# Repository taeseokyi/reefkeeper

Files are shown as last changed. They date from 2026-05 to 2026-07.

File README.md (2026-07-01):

# AquaWiz - 고정밀 pH/dKH 자동 측정 시스템

🌐 **실시간 측정 그래프:** https://taeseokyi.github.io/reefwiz/
(안드로이드 Chrome에서 열어 메뉴 → **홈 화면에 추가**를 누르면 앱처럼 설치됩니다)

> **:warning: 경고:** 이 프로젝트의 하드웨어, 소프트웨어, 문서는 **어떠한 공식 검증도 거치지 않았습니다.** 측정 정확도, 전기적 안전성, 장기 신뢰성에 대한 보증이 없으며, 사용으로 발생하는 모든 결과(장비 손상, 생물 피해, 화재, 감전 등)에 대한 **책임은 전적으로 사용자 본인**에게 있습니다.

산호 수조(리프 탱크)를 위한 Arduino Nano 기반 **자동 경도(dKH) 측정기**입니다.
탄산염 화학법을 이용하여 참조 해수와 수조수의 pH 차이로부터 dKH를 자동 산출합니다.

셋팅 구성

### 최종 형태 — 밀폐 폐루프 (공통 헤드스페이스)

> **밀폐는 선택이 아니라 필수입니다.** 참조수 통·측정 챔버·펌프 흡입을 **하나의 밀폐된 공기**로 묶어, 측정 순간 참조수(ref)와 수조수(tank)가 **같은 pCO₂**를 공유하도록 보장합니다. 이것이 방 CO₂ 변동을 차동으로 상쇄하는 핵심 조건이며, 동시에 증발(경도 농축)까지 차단합니다. 밀폐 적용 후 첫 새벽(고-CO₂) 측정에서 그간 재현되던 새벽 오차가 사라졌습니다(ΔpH −0.043 → **−0.008**) — [측정 대장](docs/measurement-ledger.md) 2026-06-19 참조.

| 제어기 |
|:---:|
| 제어기 |

### 주요 특징

- **[±0.07 dKH 정확도](docs/system-setup.md#측정-정확도)** — 16비트 ADC + 64회 오버샘플링 + Nernst 온도 보정, 분해능 ±0.001 dKH
- **[PC 연동 평형 자동 측정](docs/system-setup.md#자동-측정-시퀀스-pc-측-v4)** — 샘플링 → 폭기(CO2 평형) → tank·ref **진짜 평형(평탄)까지** pH 측정 → dKH 계산 → 정리. 펌웨어가 아닌 PC측 파이썬 스크립트가 평탄(수렴) 판정으로 단계를 제어
- **[탄산염 화학법](#측정-원리)** — `KH_tank = KH_ref × 10^(-ΔpH)`, 참조수와 동시 탈기로 CO2 변수 제거
- **[Nernst 온도 보정](docs/system-setup.md#nernst-온도-보정)** — 보정 온도 EEPROM 저장, 15~35°C 전 범위 오차 0%
- **[블루투스 제어](docs/user-manual.md#14-블루투스-터미널-앱)** — HC-06으로 스마트폰에서 원격 제어/모니터링 ( <a href="https://play.google.com/store/apps/details?id=de.kai_morich.serial_bluetooth_terminal" target="_blank">Serial Bluetooth Terminal</a> 앱 추천)
- **[참조 dKH 역산](docs/user-manual.md#35-calref--참조-dkh-역산)** — 수조 dKH 실측값으로 참조수 dKH를 자동 계산, 참조수 별도 측정 불필요
- **[밀폐 공통 헤드스페이스 (필수)](docs/system-setup.md#위즈-탱크)** — 참조수·측정수·펌프 흡입이 한 밀폐 공기를 공유 → 측정 순간 ref·tank pCO₂ 일치(방 CO₂ 공통모드 상쇄) + 증발/오염 차단. 새벽 고-CO₂에서도 ΔpH 안정(2026-06-19 검증)
- **[3D 프린팅 하우징](docs/system-setup.md#하우징-3d-프린팅)** — OpenSCAD 파라메트릭 설계, 부품 실측 후 즉시 출력
- **확장 가능** — ESP32 보드와 시리얼/블루투스 연결로 Wi-Fi, 웹 대시보드, 모바일 앱, 인터넷 접속으로 확장 가능

> 정밀한 pH 측정을 위해 Wi-Fi가 없는 Arduino Nano를 사용하여 전자기 간섭을 최소화하였습니다. Wi-Fi, 웹 대시보드, 데이터 로깅 등 부족한 기능은 ESP32를 시리얼/블루투스로 연결하면 해결 가능합니다.

> 연동 펌프의 토출량은 설정한 시간(초)에 비례하지만, 호스 길이나 수두차에 따라 실제 물량이 달라질 수 있습니다. 각 펌프에 PWM 속도 컨트롤러의 Motor− 출력을 L298N ENA/ENB에 연결하여 역 PWM으로 모터 속도를 제어하므로, 토출량을 미세하게 조정할 수 있습니다.

## 한눈에 보기

| 시스템 구성도 | 호스 연결도 |
|:---:|:---:|
| 구성도 | 호스 |

| 회로도 (Fritzing) | 하우징 (3D 프린팅) |
|:---:|:---:|
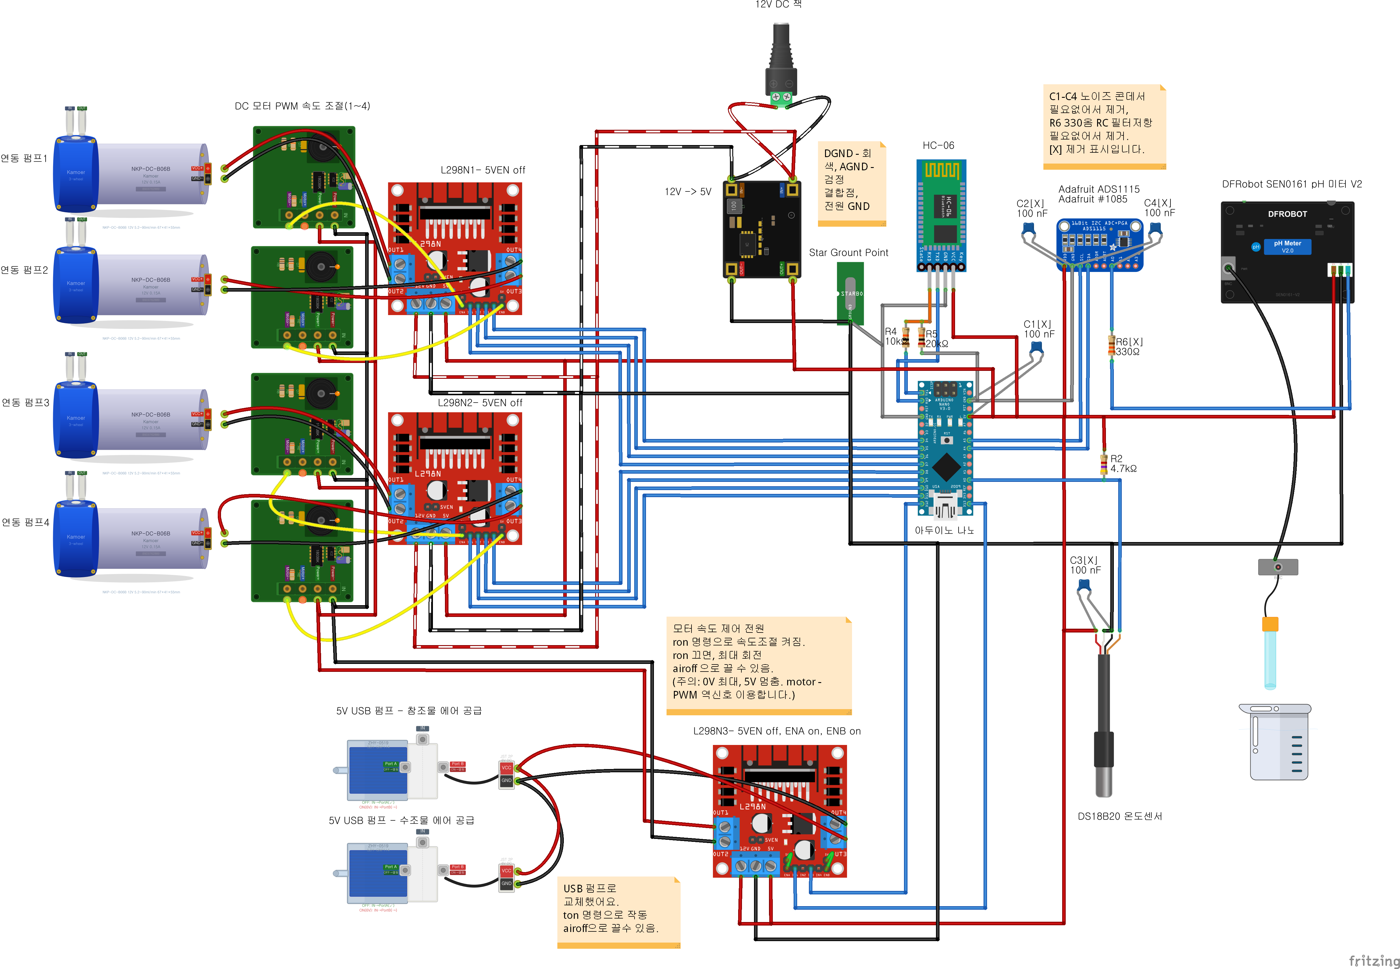
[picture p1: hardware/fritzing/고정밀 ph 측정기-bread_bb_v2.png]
회로도
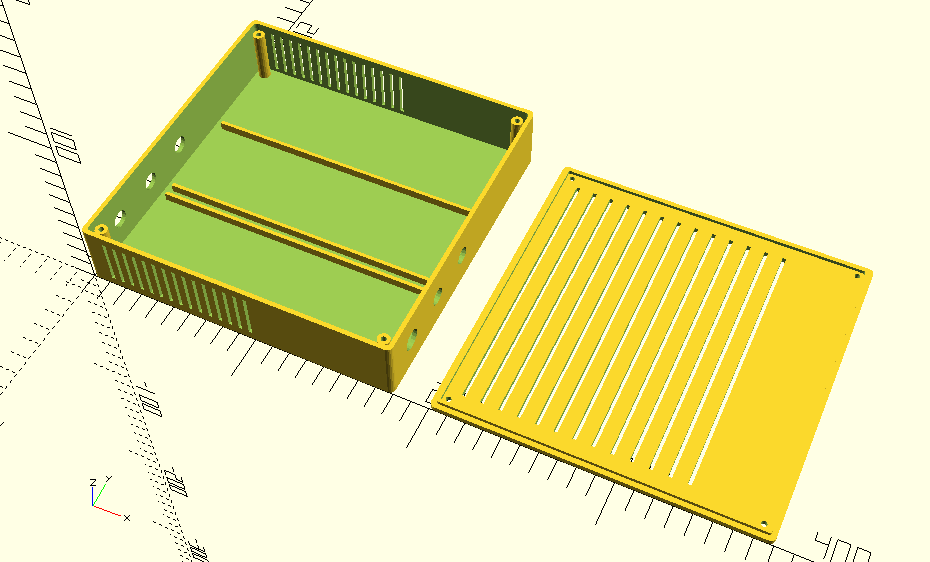
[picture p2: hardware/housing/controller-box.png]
제어기
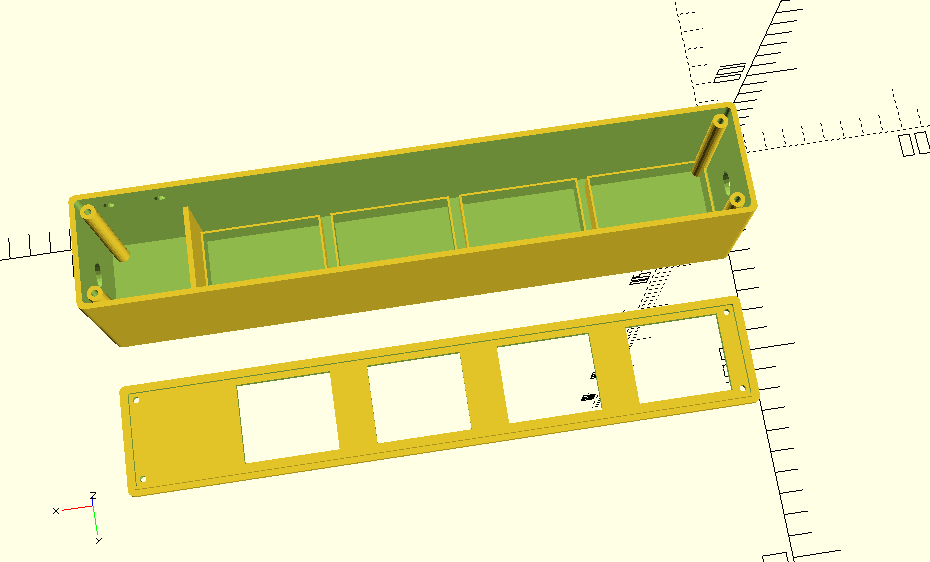
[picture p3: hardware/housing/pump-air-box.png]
펌프
|  |   |

## 측정 정확도

> **dKH 8.5 기준, 시스템 정확도 ±0.07 dKH (±1.2%)** — pH 프로브 반복성이 전체 오차의 97%를 차지하며, 전자 회로와 펌웨어 계산 로직은 프로브 성능을 100% 활용할 수 있는 수준입니다.

| 항목 | 성능 | 핵심 기술 |
|---|---|---|
| 측정 분해능 | **±0.001 dKH** | 16비트 ADC (ADS1115) + 64샘플 트림평균(정렬 후 상·하위 16개 버리고 중앙 32개 평균 → 폭기 버블 스파이크 제거) |
| 시스템 정확도 | **±0.07 dKH (±1.2%)** | Nernst 보정 + 동일 온도 차등 측정 |
| 온도 보정 오차 | **0%** | 보정 온도 EEPROM 저장, 15~35°C 전 범위 |

[상세 오차 분석 →](docs/system-setup.md#측정-정확도)

> **이 수치는 책상 계산이 아니라 수십 회의 실측·검증을 거쳐 다듬은 결과입니다.** 코드 버전(V0~V4)별 측정 기록, 환경 변수(방 CO₂) 통제, 차동 측정이 방 CO₂ 의존성을 제거함을 보인 ΔpH 검증, 그리고 그 해석을 뒷받침한 학술 문헌까지 — 신뢰성의 근거는 모두 [**측정 대장**](docs/measurement-ledger.md)에 시각순으로 정리되어 있습니다.

> **✅ 완전 널테스트로 확정 (2026-06-21):** 같은 물(위즈 해수)을 ref·tank 양쪽에 넣어 *물 차이를 0으로 만든* 완전 널에서 **ΔpH −0.003, dKH 8.387 (참값 8.448 대비 오차 −0.061)** 을 측정했습니다. 물 차이가 구성상 0이므로 이 −0.06 dKH가 계측기의 *순수* 시스템 offset입니다 — ±0.07 정확도 사양을 실측으로 뒷받침합니다. (참고: 측정 시점에 보였던 큰 오차는 *시험용 옛 200mL 시료 물의 알칼리니티 손실(CaCO₃ 석출)* 이었으며 계측기 오차가 아니었습니다. 신선한 물에선 무보정으로 ±0.1 dKH 안.) — [측정 대장 최종 결론](docs/measurement-ledger.md) 참조.

## 측정 원리

```
KH_tank = KH_ref × 10^(-ΔpH)
ΔpH = pH_ref − pH_tank
```

탈기 후 두 샘플의 CO2 농도가 동일해지면, pH 차이는 순수하게 알칼리니티(dKH) 차이만을 반영합니다.

> **★전제 = 같은 pCO₂.** 위 식은 측정 순간 ref·tank의 CO₂가 동일할 때만 순수 dKH차를 줍니다. 이를 보장하는 것이 **밀폐 공통 헤드스페이스**입니다 — 두 물이 하나의 밀폐 공기를 공유하므로 방 CO₂가 변해도 공통모드로 상쇄됩니다. 밀폐는 [위즈 탱크 구성](docs/system-setup.md#위즈-탱크)에서 **필수**로 다룹니다.

## 하드웨어

| 부품 | 모델 | 역할 |
|---|---|---|
| MCU | Arduino Nano V3.0 (ATmega328P) | 메인 컨트롤러 |
| pH 센서 | DFRobot SEN0161-V2 | pH 전압 측정 |
| ADC | Adafruit ADS1115 (16-bit) | I2C 고정밀 ADC |
| 온도 센서 | DS18B20 (PTFE) | Nernst 온도 보상 |
| 블루투스 | HC-06 | 하드웨어 Serial (9600 baud) |
| 모터 드라이버 | L298N x 3 | L298N1/N2: 도징 펌프 (12V), L298N3: 에어 펌프 (5V) |
| 도징 펌프 | Kamoer NKP-DC-B06S x 4 | 참조수/수조수 도징 |
| 에어 펌프 | USB 5V 에어 펌프 x 2 | 참조수/수조수 폭기 (L298N3 제어) |
| 전원 | 12V DC + Buck Converter (5V) | 전원 공급 |

- 구매 링크 포함 상세 목록: [준비물 목록](docs/parts-list.md)
- 구성 요소 상세 / 펌프 역할: [자동화 환경 구성 — 구성 요소](docs/system-setup.md#구성-요소)
- 3D 프린팅 하우징: [자동화 환경 구성 — 하우징](docs/system-setup.md#하우징-3d-프린팅)

### 회로도

브레드보드 회로도

Fritzing 소스: <a href="hardware/fritzing/고정밀%20ph%20측정기-bread.fzz" target="_blank">고정밀 ph 측정기-bread.fzz</a> | PDF: <a href="hardware/fritzing/고정밀%20ph%20측정기-bread_bb.pdf" target="_blank">브레드보드 도면</a>

**핀 배치 요약:**

```
D0  (RX)  ← HC-06 TX        D1  (TX)  → HC-06 RX (전압분배기)
D4~D7     → L298N1 IN1~IN4  D8~D11    → L298N2 IN1~IN4
D12       → L298N3 IN2 (에어 펌프 ON/OFF, ron/roff)  D13  → L298N3 IN4 (PWM 속도 제어기 ON/OFF, ton/toff)
A0  (D14) ← DS18B20 DQ      A4/A5     ↔ ADS1115 I2C
```

### 전원 / 접지

```
12V DC Jack
  ├── L298N1, L298N2 (모터 전원, 12V → 도징 펌프)
  ├── Buck 12V→5V (Arduino, ADS1115, HC-06)
  └── USB 5V → L298N3 (에어 펌프 제어)
속도 제어: PWM 컨트롤러 Motor− → L298N ENA/ENB (역 PWM)
접지: Star Ground Point (DGND/AGND 분리 후 한 점 결합)
```

## 빌드 및 업로드

| 라이브러리 | 제작자 |
|---|---|
| DFRobot_PH | DFRobot |
| Adafruit ADS1X15 | Adafruit |
| OneWire | Paul Stoffregen |
| DallasTemperature | Miles Burton |

1. Arduino IDE에서 [`firmware/aquawiz_ph_meter_final/aquawiz_ph_meter_final.ino`](firmware/aquawiz_ph_meter_final/aquawiz_ph_meter_final.ino) 열기
2. 보드: **Arduino Nano**, 프로세서: **ATmega328P** 선택
3. **HC-06을 D0/D1에서 분리** 후 업로드 → 완료 후 재연결

## 사용 방법

### 초기 설정

```
1. pH 2점 보정:   enterph → calph (pH7) → exitph → enterph → calph (pH4) → exitph
2. 온도 오프셋:   settemp:-0.3
3. 참조 dKH:      setref:8.5
```

### 자동 측정 (PC 연동)

폭기 중 측정을 반복하며 **tank·ref가 진짜 평형(평탄)에 도달할 때까지** 측정해야 하므로(평탄 판정 = 측정값 비교 후 반복 결정), 자동화는 펌웨어가 아닌 **PC측 파이썬 스크립트**가 담당합니다. 펌웨어에는 더 이상 `seq` 매크로가 없습니다.

```bash
# 1회 측정 후 종료 (Windows 작업 스케줄러 정시 호출용 / 수동 실행 가능)
python bin/measure_kh_once.py        # 포트 = 스크립트 기본값 COM15
python bin/measure_kh_once.py COM7   # 포트 직접 지정
```

스크립트는 준비(샘플링·헹굼) → **[A] tank·ref 동시 폭기 + tank 평탄까지** → 전이 → **[B] ref 평탄까지** → `calkh` → 정리 순으로 펌웨어 명령을 단계별 전송합니다. 상세 흐름·상수·스케줄러 등록은 [자동화 환경 구성 — 자동 측정 시퀀스](docs/system-setup.md#자동-측정-시퀀스-pc-측-v4)를 참조하세요.

### 주요 명령어

| 분류 | 명령어 |
|---|---|
| pH 측정 | `ref`, `tank`, `calkh`, `calref`, `status`, `khhist` |
| pH 보정 | `enterph`, `calph`, `exitph` |
| 설정 | `settime:HH`, `setref:x`, `settemp:x` |
| 모터 | `m1f:초`, `m1b:초`, `m1s` (m1~m4) |
| 에어/PWM | `ron`/`roff` (D12 에어 ON/OFF), `ton`/`toff` (D13 PWM 제어기 ON/OFF), `airoff` (둘 다 OFF) |
| 정지 | `m1s`~`m4s` (개별), `stop` (전체 모터+핀 OFF) |

전체 명령어 및 상세 설명은 [사용 설명서](docs/user-manual.md)를 참조하세요.

## 문서

| 문서 | 설명 |
|---|---|
| [자동화 환경 구성](docs/system-setup.md) | 구성 요소, 호스 연결, 측정 시퀀스, 하우징 |
| [사용 설명서](docs/user-manual.md) | 전체 명령어, 보정, 오류 메시지, 팁 |
| [준비물 목록](docs/parts-list.md) | 부품 사진, 구매 링크, 금액 |
| [**측정 대장**](docs/measurement-ledger.md) | 코드 버전별 실측 기록·환경·ΔpH 검증·참조 문헌 — **결과 신뢰성의 근거** |

## 산호 수조 권장 dKH 범위

| 유형 | dKH |
|---|-----|
| 자연 해수 | 6.5 ~ 7.5 |
| 산호 수조 권장 | 8 ~ 12 |
| SPS 경산호 최적 | 8 ~ 9 |
| LPS/소프트 코랄 | 7 ~ 11 |

## 라이선스

이 프로젝트는 개인 용도로 제작되었습니다.

---

이 프로젝트의 펌웨어, 문서, 다이어그램, 하우징 설계의 **80% 이상이 AI의 도움**을 받아 작성되었습니다.

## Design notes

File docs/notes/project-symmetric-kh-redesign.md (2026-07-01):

# project-symmetric-kh-redesign

> "KH 측정 대칭화 재설계 확정안 — 저장수조 직접 폭기, tank 우선, KCl 스윕=tank 헹굼, 3M KCl 보관 — 구현+Windows 배포 완료(2026-06-14)"

---

**2026-06-12 설계 확정 (사용자 주도), WSL bin/ 구현. 2026-06-14 펌프시간 튜닝 + Windows `measure_kh_once.py` 배포 완료(커밋 9b333e2).** 수렴 판정(`measure_converged`: 45초 간격, 연속 차 <CONV_EPS=**0.005**, 최대 6회, STABLE_SECS=60). 실제 펌프 동작시간은 [project-pump-timings](project-pump-timings.md) 참조(아래 시퀀스의 :5/:2는 설계 당시 placeholder). dkh.dat 형식은 불변(서버 호환), 수렴 횟수는 measure_kh.log 에만 기록.

**문제:** 기존 시퀀스는 참조수가 측정컵에서 30분 폭기(프로브 30분 소크=완전 평형) 후 측정, 수조수는 교체 ~20초 만에 측정 → 전극 응답 지연이 tank에만 실리는 계통 편향. 드리프트(0.01 pH/h)는 ref↔tank 간격이 짧아 무시 가능(~0.002 dKH); 표적은 지연 편향.

**확정 시퀀스 (tank 우선):**
```
[준비]  airoff → ton → m1f:5 (수조수→챔버)
[폭기]  ron 30분 (저장수조 5L + 챔버 동시) — 프로브는 측정컵 KCl에 휴식 → airoff
[tank]  m3b:5 (KCl 배출)
        m2f:2 → m2b:2   ← KCl 스윕 = tank 헹굼 겸용
        m2f:5 → T초 안정화 → 'tank' → m2b:5
[ref]   m4f:2 → m4b:2   ← ref 헹굼 (tank 잔막 제거)
        m4f:5 → T초 안정화 → 'ref' → 'calkh' → m4b:5
[정리]  m1b:5 (KCl 포함 챔버수→본수조 방출·희석) → m3f:5 (KCl 재공급) → airoff
```

**설계 근거:**
- 폭기를 저장수조 자체에서: 새 용기/펌프/펌웨어 불필요, 유일한 물리 작업=참조측 에어스톤을 측정컵→저장수조 이전. 5L 관성으로 ref 평형 안정.
- tank 우선: KCl 스윕이 tank 헹굼을 겸해 단계 절약. 쓸린 KCl은 챔버→m1b→본수조(무한 희석). ref 헹굼 반환수가 KCl-free → 5L 앵커(8.448) 보호.
- 펌웨어는 측정 순서 무관: ref/tank 플래그 독립(ino:618-619), calkh는 둘 다 요구 후 리셋(ino:404-430).
- 헹굼=희석 원리(잔막 0.3mL/채움 50mL ≈ 1/100), 펌프 제트가 교반 역할, 흔들기 불필요. ref 헹굼은 화학적으론 보험이지만 **타이밍 대칭(지연 공통모드 상쇄)을 위해 유지** — tank/ref 블록의 헹굼·채움·안정화 시간을 초 단위로 동일하게.

**보관액: 3M KCl in RODI (1L당 224g ≈ 22% w/v, 시약 직접 제조)**
- 용해도 OK: 포화 ≈4.2M@25°C, 3M은 0°C 근처까지 석출 없음 (이게 3M이 표준인 이유).
- 측정 외 상시 소크 = 컨디셔닝 그 자체 → **별도 재생 루틴 불필요.** 응답 둔화(수렴 횟수 증가로 감지) 시에만 묽은 HCl 세척 고려.
- 중성염이라 스윕 혼입 dKH 무영향. 본수조 K⁺ 유입 하루 ~1g KCl(잔막 0.2mL 가정) → 환수 길면 가끔 K⁺ 테스트.
- 저장조 증발 농축 → RODI 수위 보충.

**스크립트 구현 메모 (다음 세션):**
- 안정화 T = 60~120초, tank/ref 동일.
- 수렴 판정 권장: 'tank'/'ref'를 45초 간격 반복, 연속 차 <0.005이면 진행(최대 6회). 펌웨어가 마지막 값 덮어쓰므로 수정 불필요. 수렴 횟수 로그 = 전극 건강 지표.
- 참조수 5L 증발 농축(1%=+0.08 dKH 상당) → 주기적 수위 보충/calref.
- 에어스톤 이전 직후 첫 사이클은 폭기 1~2시간 수동 연장(5L 첫 평형).
- 에어스톤 이전 직후 첫 사이클은 폭기 수동 연장 권장(5L 첫 평형). 평상시 폭기=20분(AIR_SECS 1200).

**커밋/문서 (2026-06-12, 커밋 9979dfb 푸시 완료):** bin 스크립트 + `docs/system-setup.md` "자동 측정 시퀀스" 섹션 전면 재작성(설계 배경·9단계 흐름·스크립트 상수표·운용 메모) + 문서/SVG의 "KCL 3%"→"3M KCl" 일괄 변경.

**KCl 스윕 정당성 (사용자 질문에 답한 논리, 재논의 방지용):** 스윕한 KCl이 수조물 비이커 경유로 측정수에 일부 되돌아오는 것 맞음(반환 비율≈채움량/비이커수량≈1/3, 헹굼 없으면 ~18mM vs 있으면 ~6mM). 그래도 헹굼이 나은 이유: ①되돌아온 혼입은 **묽고 균일** — 중성염이라 알칼리도 무영향, 이온강도 +2% 수준으로 pH 영향 <0.002. ②헹굼이 막는 진짜 문제는 3M 원액 잔막의 **국소 농도 구배** → 정션 전위 드리프트(수 mV, 1mV≈0.017pH≈0.3dKH) + 수렴 지연. ③ref 블록에 헹굼이 있으므로 tank 헹굼 제거 시 전극 이력 비대칭 재발. ④혼입분은 m1b로 본수조 방출되어 누적 없음.

**Why:** 응답 지연 비대칭 제거가 목표. 사용자 결정 사항(저장수조 폭기, tank 우선, 3M KCl)을 보존해 다음 세션에서 재논의 없이 구현.

**How to apply:** 구현·배포 완료. 운용 모니터링은 measure_kh.log의 `[수렴실패]` 빈도(잦으면 STABLE_SECS↑)와 수렴 횟수(전극 노화) 관찰. 관련: [project-measure-kh-script](project-measure-kh-script.md), [project-pump-timings](project-pump-timings.md), [project-firmware-kh-calc](project-firmware-kh-calc.md), [feedback-run-windows-py-from-wsl](feedback-run-windows-py-from-wsl.md)

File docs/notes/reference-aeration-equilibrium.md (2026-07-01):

# reference-aeration-equilibrium

> "폭기 화학 — 대기평형이 pH 상한, \"과폭기\" 불가, 폭기 부족(비대칭)만 dKH 오차 유발"

---

폭기는 물의 pCO₂를 방 공기(~400ppm)와 **평형**시키는 과정. 평형 도달 시 pCO₂(물)=pCO₂(공기)가 되어 **더 폭기해도 pH가 안 올라감 — 대기평형 pH가 천장**. 따라서 "과폭기로 ΔpH가 평형을 넘어 틀어진다"는 메커니즘은 **없다**(사용자 지적 맞음, 2026-06-15). 폭기가 dKH를 틀어뜨리는 건 오직 **부족(ref·tank 비대칭)**일 때 — 한쪽에 CO₂가 잔류하면 그쪽 pH가 부당히 낮아져 가짜 ΔpH.

차동식 `KH_tank = 8.448 × 10^(−(pH_ref−pH_tank))`([project-firmware-kh-calc](project-firmware-kh-calc.md))가 순수 KH차를 반영하려면 **ref·tank의 pCO₂가 같아야** 함. 그래서 측정 시퀀스는 ref(5L 김치통)+tank(챔버) **동시 폭기**로 양쪽을 같은 평형에 맞춤([project-symmetric-kh-redesign](project-symmetric-kh-redesign.md)). 양쪽 평형 후 남는 ΔpH = 진짜 KH차 + 전극 노이즈(±0.005~0.01). 민감도 ≈19.5 dKH/pH(0.01 pH = 0.19 dKH)라 작은 ΔpH도 dKH로 증폭됨. 평형 도달이 안 되면(부피 큼) 시간이 율속 — 5L는 8h에도 잔차 0.020, 소부피(~150mL)면 20분 1회로 완전평형. 관련 [project-kh-offset-aeration-test](project-kh-offset-aeration-test.md)

**부피 대칭 불필요(2026-06-15 사용자 정정)**: 평형 pH = f(AT, pCO₂, T, S)이고 **부피 항 없음**(헨리법칙 [CO₂]aq=K_H·pCO₂는 부피 무관). 따라서 수조수 100mL vs 참조수 1L처럼 **부피가 달라도 둘 다 완전 평형이면 ΔpH 오차 0** — 부피는 상쇄됨. "같은 부피라야 대칭"은 부분평형(미완)일 때만 성립(부피 다르면 평형곡선상 다른 지점). 즉 관건은 부피 일치가 아니라 **둘 다 완전 평형 도달 + ref/tank의 pCO₂·온도 일치**. 율속은 느린 쪽(부피 큰 ref) → 폭기시간을 그 기준으로. ref를 상시 폭기로 늘 평형 유지하면 매 측정 때 100mL 수조수만 평형시키면 됨(소부피라 빠름). 완전평형 도달의 실측 증거 = 수렴판정 plateau(45s/0.005). 1L·20분이면 마진 충분([reference-aeration-literature](reference-aeration-literature.md) Takahashi 직접버블링 15분).

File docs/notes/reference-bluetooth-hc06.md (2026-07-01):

# reference-bluetooth-hc06

> "HC-06 블루투스 WSL 연결 방법 — rfcomm, MAC 주소"

---

**HC-06 MAC:** `98:DA:60:0F:C5:7A`

**WSL에서 연결 순서:**
1. Windows PowerShell (관리자): `usbipd bind --busid 1-1` (최초 1회)
2. Windows PowerShell: `usbipd attach --wsl --busid 1-1` (재시작 시마다)
3. WSL: `sudo service bluetooth start`
4. WSL: `sudo rfcomm release rfcomm0` (기존 bind 있을 때)
5. WSL: `sudo rfcomm connect rfcomm0 98:DA:60:0F:C5:7A 1`
   → "Connected /dev/rfcomm0 ..." 메시지 후 터미널 유지 (또는 nohup 백그라운드)

**주의사항:**
- HC-06은 1:1 연결 — 폰 앱 연결 중이면 PC에서 접속 불가, 폰 먼저 끊을 것
- rfcomm connect 터미널 닫으면 연결 끊김
- bluetoothctl trust 설정 필요: `bluetoothctl trust 98:DA:60:0F:C5:7A`

**연결 확인:**
```bash
python3 -c "import serial,time; s=serial.Serial('/dev/rfcomm0',9600,timeout=3); time.sleep(1); s.write(b'status\r\n'); time.sleep(2); [print(s.readline().decode().strip()) for _ in range(20) if s.in_waiting]"
```

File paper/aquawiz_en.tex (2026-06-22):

\documentclass[11pt]{article}

% ---- arXiv-style preprint layout (pdflatex) ----
\usepackage[utf8]{inputenc}
\usepackage[T1]{fontenc}
\usepackage{lmodern}
\usepackage[margin=1in]{geometry}
\usepackage{amsmath,amssymb}
\usepackage{graphicx}
\usepackage{booktabs}
\usepackage{array}
\usepackage{multirow}
\usepackage{longtable}
\usepackage{caption}
\usepackage{authblk}
\usepackage{xcolor}
\usepackage{enumitem}
\usepackage[hidelinks]{hyperref}
\usepackage{textcomp}
\usepackage{mhchem}
\usepackage{siunitx}
\sisetup{detect-all}
\usepackage{pgfplots}
\pgfplotsset{compat=1.15}
\usetikzlibrary{arrows.meta,positioning,calc}

\captionsetup{font=small,labelfont=bf}
\renewcommand{\arraystretch}{1.15}

% convenience macros
\newcommand{\dpH}{\ensuremath{\Delta\mathrm{pH}}}
\newcommand{\dkh}{\ensuremath{\,\mathrm{dKH}}}
\newcommand{\co}{\ensuremath{\mathrm{CO_2}}}
\newcommand{\pco}{\ensuremath{p_{\mathrm{CO_2}}}}
\newcommand{\at}{\ensuremath{A_\mathrm{T}}}

\title{\bfseries A Low-Cost Single-Probe Differential-pH Aeration Monitor for\\
Seawater Carbonate Alkalinity: Systematic-Error Decomposition and\\
Sub-0.25\,dKH Accuracy via Sealed Common-Headspace Equilibration}

\author[1]{nowforyou\thanks{Correspondence: \texttt{taeseokyi@gmail.com}}}
\affil[1]{REEF FAMILY}

\date{\today}

\begin{document}
\maketitle

\begin{abstract}
\noindent
Carbonate alkalinity (``KH'', expressed in degrees, \dkh) is the single most
control-critical water-chemistry parameter in reef aquaria, yet affordable
continuous monitors are scarce and reagent titration is laborious. We describe
an open, reagent-free monitor that infers alkalinity from the equilibrium pH a
seawater sample reaches after aeration to atmospheric \co{}, using a
\emph{single} pH probe to measure an aquarium sample (``tank'') and a
known-alkalinity reference (``ref'') in immediate succession. Because dKH is
computed from the pH \emph{difference}
($\mathrm{KH_{tank}} = \mathrm{KH_{ref}}\cdot 10^{\dpH}$), absolute probe drift
and room-\co{} excursions are common-mode signals that cancel. Over a
nine-day instrumented campaign (30 logged measurements across five
firmware/method revisions) we observed a persistent uncorrected error of
$-0.92\dkh$ and, rather than zero-point calibrating it away, decomposed it.
Three interventions---(i) plateau-following measurement to true gas
equilibrium, (ii) a single \emph{sealed common headspace} shared by sample,
reference and pump intake, and (iii) an actively aerated 5\,L reference anchor
that pins the headspace \pco{}---collapsed the dawn-\co{} error and the
diurnal evaporation confound, and shrank measurement scatter to
$\mathrm{SD}=\pm0.08\dkh$ (about one-third of the $\pm0.25\dkh$ design goal). A
sequence of null experiments (identical water in both vessels, true
$\dpH=0$) then localized the residual: a \emph{complete null} returned
$\dpH=-0.003$, $\mathrm{dKH}=8.387$, i.e.\ an instrument offset of only
$-0.06\dkh$. The remaining $-0.86\dkh$ was traced to alkalinity loss
(\co{}\,driven \ce{CaCO3} precipitation / biofilm) in the days-old, small,
open tank aliquot---a sample-handling artifact, not a measurement fault.
Re-running the null on the same aged aliquot over the following day showed the
offset drifting away from zero ($-0.22$ then $+0.22\dkh$ on successive runs) with
the electronics untouched, confirming the attribution in the time domain.
The instrument therefore meets the $\pm0.25\dkh$ goal uncorrected, with
zero-point calibration deemed unnecessary. Our independently obtained error
structure (room-\co{} sensitivity, bubble-quality dependence, sealing as the
remedy) reproduces the published behaviour of a commercial counterpart, providing
external validation of both the diagnosis and the remedy.
\end{abstract}

\noindent\textbf{Keywords:} reef aquarium; carbonate alkalinity; total
alkalinity; \co{} equilibration; differential pH; low-cost instrumentation;
common-mode rejection; \ce{CaCO3} precipitation.

% =====================================================================
\section{Introduction}
% =====================================================================
Stony corals and other calcifying reef organisms deposit calcium carbonate at
a rate that continuously consumes carbonate alkalinity. In a closed reef
aquarium the resulting alkalinity drawdown is fast (often
$0.5$--$1.5\dkh\,\mathrm{day^{-1}}$) and swings of more than $\sim1\dkh$ are
implicated in coral tissue stress. Alkalinity (\at{}, conventionally reported
by hobbyists as ``KH'' in German degrees, $1\dkh \approx
0.357\,\mathrm{meq\,L^{-1}}$) is therefore the parameter most worth measuring
\emph{often}.

The accessible options are unsatisfying for continuous use. Manual reagent
titration (e.g.\ commercial drop kits) is accurate but labour-intensive and
discrete. Colorimetric robots automate titration but consume reagent and are
expensive. Direct potentiometric pH alone is \emph{not} an alkalinity measurement,
because seawater pH depends jointly on \at{} and \pco{}, and aquarium \pco{}
varies strongly over the day (room ventilation, photosynthesis, respiration).

A reagent-free alternative exploits the fact that if a sample is aerated until
its \pco{} equilibrates with the surrounding air, the equilibrium pH becomes a
single-valued function of alkalinity at fixed temperature and salinity. A
commercial product (AquaWiz) is built on this principle and is used by reef
hobbyists, but community reports document recurring inaccuracy tied to room-\co{}
fluctuation and to aeration/bubble quality. The contribution of this paper is
not the principle but a \emph{quantitative diagnosis}: starting from a working
DIY build, we conduct a nine-day instrumented campaign, expose a $-0.92\dkh$ raw error,
and show by construction (null experiments) that essentially all of it is a
sample-handling artifact rather than an instrument limitation---reducing the
true instrument offset to $-0.06\dkh$ and meeting a $\pm0.25\dkh$ goal without
calibration. Along the way we establish a small set of design rules (sealed
common headspace; plateau-following to true equilibrium; an actively aerated
reference anchor; a two-gate plateau criterion) that we expect to generalize to
any single-probe differential-pH alkalinity monitor.

% =====================================================================
\section{Measurement Principle}\label{sec:principle}
% =====================================================================

\subsection{Aeration makes equilibrium pH a proxy for alkalinity}
At fixed temperature $T$ and salinity $S$, the seawater carbonate system has
two degrees of freedom; fixing any two of
$\{\at{}, \mathrm{DIC}, \pco{}, \mathrm{pH}\}$ determines the rest. Aeration with
a large excess of room air drives the dissolved \co{} toward Henry's-law
equilibrium with the gas phase, $[\co{}]_{aq}=K_H\,\pco{}$, so that
$\pco{}(\mathrm{water}) \to \pco{}(\mathrm{air})$. Once \pco{} is clamped by the
atmosphere, the equilibrium pH is a single-valued function of alkalinity:
\begin{equation}
\mathrm{pH_{eq}} = f(\at{},\,\pco{},\,T,\,S).
\label{eq:pheq}
\end{equation}
With \pco{}, $T$, $S$ held common, the \emph{only} variable that can move
$\mathrm{pH_{eq}}$ is \at{}. Measured equilibrium pH is therefore a proxy for
alkalinity.

\subsection{Why the differential cancels room \co{}}
The instrument never relies on the absolute value of \pco{}. It aerates the
reference and the tank sample to the \emph{same} atmospheric ceiling (in the
final design, by aerating both against one shared headspace simultaneously,
Sec.~\ref{sec:methods}) and reports the \emph{difference} of their equilibrium
pH. Because the absolute \pco{} term is common to both samples, it cancels in
the difference: a room-\co{} excursion is a common-mode signal that drops out.
What survives the subtraction is the true alkalinity difference plus electrode
noise ($\pm0.005$--$0.01$\,pH). This is the central robustness argument of the
method, and the reason a \emph{single} probe (rather than two matched probes)
is used: a single sensor's slow asymmetry-potential and reference-junction
drift load identically onto both readings and cancel in \dpH{}.

\subsection{Over-aeration is impossible; only \emph{insufficient} aeration errs}
Equation~\eqref{eq:pheq} has a hard ceiling at $\pco{}(\mathrm{air})$: once the
water reaches atmospheric equilibrium, further aeration cannot raise pH. There
is consequently no ``over-aeration'' failure mode. Error enters only through
\emph{insufficiency}: if residual \co{} remains in one vessel, that side's pH is
unfairly depressed and a spurious \dpH{} appears. The differential's assumption
is precisely that ref and tank share the same \pco{}; broken symmetry breaks
the cancellation. This motivates measuring to a genuine plateau rather than for
a fixed time (Sec.~\ref{sec:methods}).

\subsection{Volume independence at full equilibrium}
Equation~\eqref{eq:pheq} contains no volume term (Henry's law is
intensive). Hence even a large volume mismatch---in our final null,
$100\,\mathrm{mL}$ of tank water against a $5\,\mathrm{L}$ reference---produces
\emph{zero} differential error provided both vessels reach \emph{full}
equilibrium. The familiar ``equal volumes for symmetry'' rule applies only
under \emph{partial} equilibration, where unequal volumes sit at different
points on the first-order approach curve
$C(t)-C^\ast = (C_0-C^\ast)\,e^{-t/\tau}$. The true requirements are just
(a) both fully equilibrated and (b) matched \pco{} and $T$. The larger volume
is rate-limiting, with a time constant
\begin{equation}
\tau \;\propto\; \frac{V}{K_H\,Q_\mathrm{gas}}\,\beta
\;\sim\; \frac{1}{\mathrm{VVM}}\,\beta,
\label{eq:tau}
\end{equation}
where $\mathrm{VVM}=Q_\mathrm{gas}/V$ is gas volume per liquid volume per
minute and $\beta$ is a seawater chemical factor (only trace
$[\co{}]_{aq}$ is strippable; the Revelle buffering raises $\tau$ by
$\sim8$--$15\times$). Equation~\eqref{eq:tau} is the basis for the
``increase aeration to shorten the measurement'' lever discussed later, and for
the choice to miniaturize the rate-limiting reference.

\subsection{The differential dKH formula}
The firmware (Arduino Nano / ATmega328P; pH via DFRobot Gravity probe + ADS1115
16-bit ADC) digitizes one probe, reading reference then tank pH, and computes
\begin{equation}
\boxed{\;\mathrm{KH_{tank}} \;=\; \mathrm{KH_{ref}}\cdot 10^{-(\mathrm{pH_{ref}}-\mathrm{pH_{tank}})}
\;=\; \mathrm{KH_{ref}}\cdot 10^{\dpH}\;}
\label{eq:dkh}
\end{equation}
with $\dpH \equiv \mathrm{pH_{tank}}-\mathrm{pH_{ref}}$ and
$\mathrm{KH_{ref}}=8.448\dkh$ an EEPROM-stored \emph{anchor} constant (set by a
\texttt{calref} command after evaporation top-off; \emph{not} a per-run
measurement---this is why the reference column reads a constant 8.448 in every
log line). Equation~\eqref{eq:dkh} depends only on \dpH{}; absolute pH cancels
exactly. Differentiating,
\begin{equation}
\frac{d\,\mathrm{KH_{tank}}}{d\,\dpH}\bigg|_{\dpH=0}
= \mathrm{KH_{ref}}\ln 10 \approx 19.45\;\dkh\,\mathrm{pH^{-1}},
\label{eq:sens}
\end{equation}
i.e.\ $0.01$\,pH of uncancelled difference maps to $\approx0.19\dkh$. This high
sensitivity is what makes both the cancellation and the plateau criterion
matter. Temperature compensation is applied per reading by a Nernst relation
$\mathrm{pH_{corr}}=7.0+(\mathrm{pH_{raw}}-7.0)\,(273.15+T_\mathrm{cal})/(273.15+T_\mathrm{meas})$,
nominally zero-error over 15--35\,\textcelsius. Each pH reading is a trimmed
mean of 64 samples (discard the top and bottom 16, average the middle 32) to
reject aeration-bubble spikes.

% =====================================================================
\section{Apparatus}\label{sec:apparatus}
% =====================================================================
The build (Table~\ref{tab:bom}, Fig.~\ref{fig:device}) is a closed fluidic loop
around four bidirectional peristaltic pumps, two USB air pumps, a single pH
probe, and a 1-Wire temperature sensor, all driven by an Arduino Nano over a
9600-baud Bluetooth (HC-06) serial link to a host PC.

\begin{figure}[t]
\centering
\begin{tikzpicture}[
  font=\footnotesize, >={Latex[length=1.8mm]},
  vessel/.style={draw, rounded corners=2pt, fill=blue!6, align=center},
  pump/.style={draw, circle, fill=yellow!35, font=\scriptsize\bfseries, inner sep=0.4pt, minimum size=5.5mm},
  flow/.style={<->, thick, blue!55!black},
  air/.style={-{Latex[length=1.6mm]}, densely dotted, red!65!black, thick},
  wire/.style={-{Latex[length=1.6mm]}, gray!55!black},
]
% sealed headspace
\draw[dashed, rounded corners=7pt, gray!65, line width=0.9pt] (0.1,-3.05) rectangle (10.9,1.95);
\node[anchor=north east, gray!55!black, font=\scriptsize] at (10.8,1.88) {Sealed common headspace ($\approx$4\,L)};
% controller (outside, top)
\node[draw, rounded corners=2pt, fill=gray!10, align=center] (mcu) at (4.9,2.75)
  {Arduino Nano $+$ HC-06\,/\,ADS1115 pH\,/\,DS18B20};
% vessels
\node[vessel, minimum width=15mm, minimum height=20mm, fill=cyan!10] (aq) at (-2.2,-0.6) {Main\\reef\\aquarium};
\node[vessel, minimum width=14mm, minimum height=14mm] (hold) at (1.9,0.7) {Holding};
\node[vessel, minimum width=21mm, minimum height=21mm] (meas) at (4.9,-0.7) {Measurement\\chamber};
\node[vessel, minimum width=16mm, minimum height=19mm] (ref) at (8.9,-0.4) {Reference\\1\,L\\\scriptsize($+T$ sensor)};
\node[vessel, minimum width=15mm, minimum height=11mm, fill=green!8] (kcl) at (4.9,-2.45) {3\,M KCl};
\node[draw, rounded corners=1pt, fill=red!9, font=\scriptsize, align=center] (airp) at (8.9,-2.45) {Air pumps (\texttt{ron})};
% pH probe
\draw[line width=1pt] ([xshift=-3mm]meas.north) -- ++(0,5mm) coordinate (pp);
\node[font=\scriptsize, anchor=south] at (pp) {pH probe};
% liquid flows with pumps
\draw[flow] (aq.east) -- (hold.west);
\node[pump] at ($(aq.east)!0.5!(hold.west)$) {M1};
\draw[flow] (hold.south) -- (meas.north west);
\node[pump] at ($(hold.south)!0.5!(meas.north west)$) {M2};
\draw[flow] (ref.west) -- (meas.east);
\node[pump] at ($(ref.west)!0.5!(meas.east)$) {M4};
\draw[flow] (kcl.north) -- (meas.south);
\node[pump] at ($(kcl.north)!0.5!(meas.south)$) {M3};
% air lines
\draw[air] (airp.north) -- (ref.south);
\draw[air] (airp.west) to[out=180,in=-90] (meas.south east);
% probe wire to controller
\draw[wire] (pp) to[out=90,in=-90] (mcu.south);
\end{tikzpicture}
\caption{Schematic of the sealed closed-loop monitor. A single pH probe in the
measurement chamber reads the tank aliquot and the reference in turn; four
bidirectional peristaltic pumps (M1--M4) move liquid between the main aquarium,
holding beaker, measurement chamber, reference reservoir, and KCl store; two air
pumps (\texttt{ron}) aerate the reference and the chamber simultaneously. The
reference, chambers and pump intakes share one sealed headspace ($\approx$4\,L),
so sample and reference see identical $p_{\mathrm{CO_2}}$ and evaporation is
suppressed; the controller sits outside. Between runs the probe rests in 3\,M
KCl (M3).}
\label{fig:device}
\end{figure}

\begin{table}[t]
\centering
\caption{Bill of materials (current build).}
\label{tab:bom}
\footnotesize
\begin{tabular}{@{}p{0.26\linewidth} p{0.50\linewidth} c@{}}
\toprule
Subsystem & Part & Qty \\
\midrule
Microcontroller & Arduino Nano V3.0 (ATmega328P) & 1 \\
pH probe & DFRobot Gravity pH V2 (SEN0161-V2), single glass electrode & 1 \\
ADC & DFRobot Gravity I\textsuperscript{2}C ADS1115 (16-bit) & 1 \\
Temperature & DS18B20 waterproof (1-Wire), in the 5\,L reference & 1 \\
Comms & HC-06 Bluetooth, 9600\,baud & 1 \\
Pumps & NKP-DC-B06B 12\,V peristaltic, bidirectional (M1--M4) & 4 \\
Motor drivers & L298 2\,A modules (2 for pumps, 1 for air) & 3 \\
Air pumps & USB 5\,V, switched together (\texttt{ron}) & 2 \\
Reference reservoir & 5\,L sealed container (``Wiz tank'') & 1 \\
Chambers & 200\,mL beakers: holding, measurement, 3\,M KCl & 3 \\
Probe storage & 3\,M KCl ($\approx$22\,\% w/v) & --- \\
\bottomrule
\end{tabular}
\end{table}

\paragraph{Fluidic topology (current).} All pumps are bidirectional
($\mathtt{f}$ = forward, $\mathtt{b}$ = reverse):
\begin{itemize}[nosep,leftmargin=1.4em]
\item \textbf{M1}: main aquarium $\leftrightarrow$ \emph{holding} beaker;
\item \textbf{M2}: holding $\leftrightarrow$ \emph{measurement} chamber;
\item \textbf{M3}: 3\,M KCl beaker $\leftrightarrow$ measurement chamber (probe soak / storage);
\item \textbf{M4}: 5\,L reference $\leftrightarrow$ measurement chamber.
\end{itemize}
Routing the tank sample through an intermediate holding beaker lets it be
temporarily \emph{parked} while the reference is measured, minimizing the
between-phase delay (Sec.~\ref{sec:methods}). Run times are encoded as the
integer in $\mathtt{mXf{:}NN}$ / $\mathtt{mXb{:}NN}$ (seconds); reverse runs
$\sim$8--10\,s longer than forward to fully clear the hose (current values
$\mathtt{m1f{:}70/m1b{:}82}$, $\mathtt{m2f{:}60/m2b{:}68}$,
$\mathtt{m3f{:}60/m3b{:}68}$, $\mathtt{m4f{:}60/m4b{:}70}$; the 5\,L hose is
longest, hence \texttt{m4b:70}).

\paragraph{Control commands.} Air and motor enables are independent lines:
\texttt{ron} turns \emph{both} air pumps on (used only while liquid is
stationary---bubble cleaning and measurement); \texttt{ton} enables the PWM
motor controller (\emph{required} before any pump will turn); \texttt{airoff}
drops both. A load-bearing invariant follows: because \texttt{airoff} also
disables the PWM controller, every liquid move must be preceded by
\texttt{airoff}\,$\rightarrow$\,\texttt{ton}; the last air command before a
motor must be \texttt{ton}. Measurement primitives are \texttt{tank} / \texttt{ref}
(sample and store one pH reading) and \texttt{calkh} (apply
Eq.~\eqref{eq:dkh}).

\paragraph{Sealed common headspace (required).} The 5\,L reference, the
measurement chamber, and the pump intake share \emph{one} sealed headspace.
This is not an optional refinement: it (i) guarantees tank and ref see identical
\pco{} at the instant of measurement (the differential's premise), (ii) blocks
room-\co{} excursions at the source, and (iii) suppresses evaporation. In the
final configuration the headspace is $\approx$4\,L, the reference $\approx$1\,L,
and the tank aliquot $100\,\mathrm{mL}$; an air stone placed \emph{in} the
reference actively pins the shared \pco{} within minutes (the
``anchor'', Sec.~\ref{sec:methods}). Separate or isolated headspaces are
explicitly forbidden---two headspaces drift independently and destroy the
cancellation.

% =====================================================================
\section{Methods}\label{sec:methods}
% =====================================================================

\subsection{Two-phase plateau-following cycle (V4)}
Plateau detection is a host-side decision loop, so the PC script drives the
firmware step by step. The cycle measures \textbf{tank first, then ref}, so the
5\,L reference is co-aerated throughout the tank phase and converges quickly
when its turn comes:
\begin{enumerate}[nosep,leftmargin=1.6em]
\item \emph{Prep:} \texttt{m3b} (drain KCl from chamber)
$\rightarrow$ \texttt{m1f} (aquarium $\to$ holding)
$\rightarrow$ \texttt{m2f} (holding $\to$ chamber).
\item \emph{Phase A:} \texttt{ron}; measure \texttt{tank} every 30\,s until
plateau (chamber tank + 5\,L aerated together).
\item \emph{Transition:} \texttt{m2b} parks the tank aliquot back in holding;
\texttt{m4f} brings reference into the chamber.
\item \emph{Phase B:} \texttt{ron}; measure \texttt{ref} until plateau
(fast---already near equilibrium).
\item \texttt{calkh}; then cleanup: \texttt{m4b} (recover ref to 5\,L),
\texttt{m1b} (return parked tank to aquarium), \texttt{m3f} (restore KCl soak),
\texttt{airoff} (probe rests in KCl).
\end{enumerate}

\subsection{Two-gate plateau criterion}
Readings are held as integer milli-pH (mpH) to avoid floating-point boundary
jitter. A plateau is declared only when \emph{both} gates hold over a sliding
window (Table~\ref{tab:plateau}): a short \emph{span} gate (last 4 readings,
$\mathrm{max}-\mathrm{min}\le 2$\,mpH) rejects noise, and a longer \emph{net}
gate (last 8 readings, $|w_{-1}-w_{0}|\le 1$\,mpH) rejects a slow monotonic
exponential tail that the span gate alone would mistake for convergence. The
longer net look-back (8 vs.\ 4 points; ``B1'') was the fix for early latches in
which the tank stopped climbing prematurely. Per-phase wall-clock and
read-count caps ($\mathtt{PHASE\_MAX}=7200\,\mathrm{s}$,
$\mathtt{MEAS\_MAX}=240$) and a consecutive-failure cap
($\mathtt{FAIL\_MAX}=5$) bound the loop so it can never hang.

\begin{table}[t]
\centering
\caption{Plateau-following parameters (\texttt{measure\_until\_flat}).}
\label{tab:plateau}
\footnotesize
\begin{tabular}{@{}llp{0.5\linewidth}@{}}
\toprule
Constant & Value & Meaning \\
\midrule
\texttt{FLAT\_SPAN\_N}  & 4 & span window (jitter gate) \\
\texttt{FLAT\_SPAN\_MPH}& 2 & last 4: $\max-\min\le 2$\,mpH \\
\texttt{FLAT\_NET\_N}   & 8 & net look-back (drift gate; B1) \\
\texttt{FLAT\_NET\_MPH} & 1 & last 8: $|w_{-1}-w_0|\le 1$\,mpH \\
\texttt{MEAS\_INTERVAL} & 30\,s & between readings (aeration continuous) \\
\texttt{PHASE\_MAX\_SECS}& 7200\,s & per-phase cap (2\,h; 4\,h total) \\
\texttt{MEAS\_MAX}      & 240 & per-phase read cap \\
\texttt{FAIL\_MAX}      & 5 & consecutive parse failures tolerated \\
\bottomrule
\end{tabular}
\end{table}

Figure~\ref{fig:plateau} shows a measured pair of approach curves. The tank,
freshly drawn into the chamber, climbs a slow first-order tail toward its
ceiling and is held by the net gate until it is genuinely flat (latching at
$\sim$624\,s when the 8-point net drift falls to 1\,mpH). The reference, having
co-aerated in the 5\,L reservoir throughout the tank phase, is already at
equilibrium and latches in $\sim$2.6\,min---a direct illustration of why
measuring tank-first is faster, and of why the span gate alone (satisfied near
$\sim$546\,s) would have latched the tank early.

\begin{figure}[t]
\centering
\begin{tikzpicture}
\begin{axis}[
  width=0.86\linewidth, height=6.2cm,
  xlabel={Elapsed time (s)}, ylabel={pH (equilibrium approach)},
  xmin=-20,xmax=660, ymin=7.825, ymax=7.915,
  grid=both, major grid style={gray!18}, minor grid style={gray!8},
  legend style={at={(0.63,0.55)},anchor=center, fill=white, fill opacity=0.85,
    text opacity=1, draw=gray!40, font=\footnotesize}, legend cell align=left,
  tick label style={font=\footnotesize}, label style={font=\small},
]
\addplot[blue!70!black, mark=*, mark size=1.1pt, thick] coordinates {
(0,7.829)(38,7.832)(77,7.834)(116,7.836)(156,7.838)(195,7.840)(234,7.841)
(273,7.843)(312,7.844)(351,7.845)(390,7.846)(429,7.847)(468,7.848)(507,7.849)
(546,7.849)(585,7.850)(624,7.850)};
\addlegendentry{tank (chamber sample)}
\addplot[red!75!black, mark=square*, mark size=1.1pt, thick, dashed] coordinates {
(0,7.906)(38,7.909)(77,7.909)(117,7.909)(156,7.909)};
\addlegendentry{ref (co-aerated 5\,L)}
\node[anchor=west,font=\scriptsize,blue!50!black] at (axis cs:430,7.843) {net-gate latch @624\,s};
\draw[blue!50!black,->,>=stealth] (axis cs:560,7.844) -- (axis cs:620,7.849);
\end{axis}
\end{tikzpicture}
\caption{Measured plateau-following curves (sealed, net-gate run). The tank
sample (solid) climbs a slow exponential tail and is latched only when the
two-gate criterion (last-4 span $\le 2$\,mpH \emph{and} last-8 net $\le 1$\,mpH)
is met; the co-aerated reference (dashed) is already near equilibrium and latches
quickly. The two series sit at different pH because the underlying samples differ
(this run predates the null campaign); only their respective \emph{plateau}
values enter Eq.~\eqref{eq:dkh}.}
\label{fig:plateau}
\end{figure}

\subsection{Logging and fault handling}
Each completed run appends one line
\texttt{HH ref\_pH tank\_pH 8.448 tank\_kh temp} to \texttt{dkh.dat}. Two
distinct markers encode abnormal outcomes: an \emph{all-zeros} line on hard
failure (timeout, serial loss, or unverified KCl soak), which additionally
\emph{latches}---a subsequent run refuses to measure and re-writes the marker
until a human clears it, protecting the probe from unattended pump cycling; and
a \emph{negative} \texttt{tank\_kh} (magnitude preserved, sign flipped) when a
phase hits its cap without reaching plateau, which the data server reads as
``did-not-plateau'' but which does \emph{not} trip the latch. A \texttt{finally}
block runs an emergency cleanup (air off, drain chamber, restore KCl soak) on
any non-completion.

\subsection{Null-test protocol}
The diagnostic backbone is the \emph{null test}: the reference and tank vessels
are filled with the \emph{same} water so the true alkalinity difference is zero
and the correct output is exactly $\dpH=0$, $\mathrm{dKH}=8.448$. Two variants
are used. In a \emph{partial null}, only the small tank aliquot is replaced with
fresh seawater while the aged 5\,L reference is retained, so a change in \dpH{}
isolates the tank water's contribution. In a \emph{complete null}, reference
water is also placed in the tank chamber, so the water difference is zero
\emph{by construction} and any residual \dpH{} is purely instrumental.

\subsection{Revision history and the one-change-at-a-time rule}
The build evolved through five revisions (Table~\ref{tab:versions}). Changes
were made one causal axis at a time, so that each measurement campaign tests a
single mechanism; where two constants were changed together
(e.g.\ stabilization window and convergence band), they were justified as the
\emph{same} causal axis (response completeness), not two independent variables.

\begin{table}[t]
\centering
\caption{Method/firmware revisions. ``ron held'' = continuous aeration between runs.}
\label{tab:versions}
\footnotesize
\begin{tabular}{@{}llp{0.56\linewidth}@{}}
\toprule
Rev & Period & Change vs.\ prior \\
\midrule
V0 & 6/14--6/15 & First symmetric build; reference drawn from 5\,L into a cup; fixed 1200\,s aeration. \\
V1 & 6/15--6/16 & Added continuous aeration between runs (\texttt{ron} held). \\
V2 & 6/16--6/17 & Reference taken as a small directly-aerated aliquot (holding $\to$ chamber); aeration off during the reading. \\
V3 & 6/17 & Aeration \emph{during} measurement (pin tank/ref to same \pco{}); path symmetrized; KCl-rinse bubble clean (later dropped). \\
V4 & 6/17$\to$ & \textbf{Plateau-following} to true equilibrium (no fixed time); two-phase tank-then-ref; anti-hang caps; emergency cleanup. Subsequently: \emph{sealed common headspace}, \emph{5\,L active anchor}, and the two-gate (B1) criterion. \\
\bottomrule
\end{tabular}
\end{table}

% =====================================================================
\section{Results}\label{sec:results}
% =====================================================================
Table~\ref{tab:data} lists the full campaign. Throughout, $\dpH<0$ means the
tank read more acidic than the reference (lower apparent alkalinity), and by
Eq.~\eqref{eq:dkh} the raw error is
$\mathrm{dKH}-8.448 = 8.448\,(10^{\dpH}-1)$.

{\scriptsize\setlength{\tabcolsep}{4pt}
\begin{longtable}{@{}r l l r r r r r p{0.30\linewidth}@{}}
\caption{Complete measurement campaign (30 runs). ``abs pH'' is the common-mode
level (a room-\co{} proxy within a single day only). Config abbreviations:
S = sealed headspace, A = 5\,L active anchor, N = net-gate, B1 = net look-back 8.
\textbf{Null staging:} a fresh seawater batch is aliquoted at the start; PN =
partial null (the $100\,\mathrm{mL}$ tank chamber alone is refilled with that
fresh aliquot while the aged $5\,\mathrm{L}$ reference is kept, isolating the
tank-water contribution); CN = complete null (reference water is then transferred
into the tank chamber as well, so both vessels hold \emph{identical} water and the
water difference is zero by construction).}
\label{tab:data}\\
\toprule
\# & Date/time & Cfg & pH$_\mathrm{ref}$ & pH$_\mathrm{tank}$ & \dpH{} & dKH & $T$ & Conditions \\
\midrule
\endfirsthead
\multicolumn{9}{l}{\scriptsize\emph{Table~\ref{tab:data} (continued)}}\\
\toprule
\# & Date/time & Cfg & pH$_\mathrm{ref}$ & pH$_\mathrm{tank}$ & \dpH{} & dKH & $T$ & Conditions \\
\midrule
\endhead
\midrule
\multicolumn{9}{r}{\scriptsize\emph{continued on next page}}\\
\endfoot
\bottomrule
\endlastfoot
1 & 06-14 20:12 & V0 & 7.959 & 8.021 & $+0.062$ & 9.741 & 26.7 & first manual symmetric run \\
2 & 06-14 21:00 & V0 & 7.997 & 8.072 & $+0.075$ & 10.054& 26.2 & --- \\
3 & 06-15 05:00 & V0 & 8.057 & 8.077 & $+0.020$ & 8.843 & 26.4 & dawn but $+$; window open (ventilated), low \co{} \\
4 & 06-15 13:00 & V1 & 8.050 & 8.042 & $-0.008$ & 8.293 & 27.0 & first continuous aeration \\
5 & 06-15 21:00 & V1 & 8.109 & 8.091 & $-0.018$ & 8.109 & 27.3 & clean low-\co{} point \\
6 & 06-16 05:00 & V1 & 7.810 & 7.751 & $-0.059$ & 7.362 & 27.5 & dawn closed-room \co{} spike (both abs pH fell $\sim$0.3) \\
7 & 06-16 13:00 & V1b& 8.091 & 8.063 & $-0.028$ & 7.922 & 27.7 & tighter window/band \\
-- & 06-16 21:00 & --- & \multicolumn{5}{c}{\emph{failed (0.000; power cut, port semaphore)}} & \\
8 & 06-16 21:21 & V2 & 8.042 & 8.021 & $-0.021$ & 8.039 & 28.6 & first V2 (manual) \\
9 & 06-17 05:00 & V2 & 7.997 & 7.939 & $-0.058$ & 7.386 & 27.8 & V2 dawn test \emph{failed}; regressed to V1 \\
10& 06-17 13:00 & V3 & 8.109 & 8.091 & $-0.018$ & 8.095 & 28.2 & first V3; ref under-equilibrated (5 reads) \\
11& 06-17 21:00 & V4 & 8.113 & 8.071 & $-0.042$ & 7.669 & 27.8 & first V4 + trim-mean firmware; clean plateaus \\
12& 06-18 05:00 & V4 & 7.738 & 7.695 & $-0.043$ & 7.657 & 28.2 & \textbf{decisive:} dawn $-0.043\approx$ evening $-0.042$ despite 0.4 abs-pH swing $\Rightarrow$ \co{}-level independence \\
13& 06-18 13:00 & V4 & 8.081 & 8.055 & $-0.026$ & 7.950 & 28.3 & same low \co{} as \#11 yet $-0.026$; dKH $+0.29$ jump $\Rightarrow$ baseline \emph{not} constant (evaporation, open 200\,mL day 5) \\
14& 06-19 05:00 & V4+S & 7.976 & 7.968 & $-0.008$ & 8.283 & 28.1 & \textbf{seal verif.\,\textcircled{1}}: dawn dip collapses $-0.05\!\to\!-0.008$; plateau 33$\to$4 reads \\
15& 06-19 13:00 & V4+S & 7.957 & 7.947 & $-0.010$ & 8.255 & 28.6 & \textbf{seal verif.\,\textcircled{2}}: dawn$\to$noon jump $+0.29\!\to\!-0.03$ ($\sim$10$\times$); evaporation removed \\
16& 06-19 21:00 & V4+S & 7.969 & 7.968 & $-0.001$ & 8.421 & 26.8 & near-perfect null (raw err $-0.027$, smallest); but $+0.166$ vs.\ \#14/15 $\Rightarrow$ offset not a perfect constant; AC transient ($-1.8$\,\textcelsius) \\
17& 06-20 05:00 & V4+S & 7.922 & 7.871 & $-0.051$ & 7.521 & 27.7 & dawn dip recurs; tank 11$\times$ monotone = early latch (not true plateau); AC cooling slowed kinetics \\
18& 06-20 15:00 & V4+SAN& 7.975 & 7.929 & $-0.046$ & 7.602 & 27.1 & first 5\,L anchor; tank \emph{true} plateau (34$\times$, 21.6\,min) yet $-0.046$ $\Rightarrow$ \textbf{genuine gap}, not latch artifact \\
19& 06-20 18:11 & V4+S,2$\times$& 7.979 & 7.924 & $-0.055$ & 7.443 & 26.4 & controlled exp; 2$\times$ aeration halves climb (1296$\to$711\,s) but \dpH{} unchanged $\Rightarrow$ \emph{not} kinetics \\
20& 06-20 18:57 & V4+S,2$\times$& 7.975 & 7.931 & $-0.044$ & 7.636 & 26.7 & ref-first + hose swap; gap persists $\Rightarrow$ order/path/non-equilibrium all rejected \\
21& 06-20 19:50 & V4+S & 7.975 & 7.926 & $-0.049$ & 7.539 & 26.9 & reproduction \\
22& 06-20 20:29 & V4+SA& 7.977 & 7.921 & $-0.056$ & 7.426 & 26.9 & tank-first+park; ref fastest ever (4$\times$); tank early latch (7.921) $\Rightarrow$ motivates B1 \\
23& 06-20 21:00 & V4+SA,B1& 7.979 & 7.926 & $-0.053$ & 7.474 & 27.0 & \textbf{B1 ok}: tank 25$\times$/945\,s true plateau; confirms \#22 was $\sim$5\,mpH short; gap (7th) \\
24& 06-21 05:00 & V4+SA,B1& 7.974 & 7.928 & $-0.046$ & 7.594 & 26.7 & dawn matches evening cluster $\Rightarrow$ time-of-day dependence ruled out (gap, 8th) \\
25& 06-21 06:00 & V4+S,PN& 7.973 & 7.963 & $-0.010$ & $-8.255$ & 26.7 & \textbf{partial null}: fresh tank only; tank pH $+37$\,mpH, \dpH{} $-0.05\!\to\!-0.010$; tank not plateaued (old cap) $\Rightarrow$ lower bound \\
26& 06-21 13:00 & V4+S,PN& 7.964 & 7.956 & $-0.008$ & 8.298 & 27.2 & \textbf{partial null, full eq.}: dKH 8.298, raw err $-0.15$; back in good cluster; 4\,h cap validated \\
27& 06-21 19:00 & V4+S,CN& 7.960 & 7.957 & $-0.003$ & 8.387 & 27.4 & \textbf{complete null}: reference water into tank chamber too $\Rightarrow$ both identical; raw err $-0.061$ = pure instrument offset; $100\,$mL vs.\ 5\,L cancels \\
28& 06-21 21:00 & V4+S,CN& 7.959 & 7.958 & $-0.001$ & 8.434 & 27.4 & \textbf{complete null} (2nd): $\dpH-0.001$ (resolution limit), raw err $-0.014$ (smallest); reconfirms the $\le0.06\dkh$ offset \\
-- & 06-22 05:00 & V4+S,CN & \multicolumn{5}{c}{\emph{failed (cap)}} & 55-min scheduler cap killed it mid-ref; tank had plateaued (7.955); fix: 5\,h cap \\
29& 06-22 09:00 & V4+S,CN& 7.959 & 7.948 & $-0.011$ & 8.226 & 27.4 & \textbf{aged complete null} ($\sim$14\,h, $100\,\mathrm{mL}$ exposed aliquot): null decayed to raw err $-0.22$; tank true plateau 59$\times$ (long aeration drives precipitation, KH$\downarrow$) \\
30& 06-22 13:00 & V4+S,CN& 7.950 & 7.961 & $+0.011$ & 8.664 & 27.6 & \textbf{aged null reverses} ($\sim$18\,h): short plateau (tank 8$\times$), $\dpH>0$, dKH $8.664$ (raw err $+0.22$) $\Rightarrow$ evaporative concentration (KH$\uparrow$) overtakes precipitation \\
\bottomrule
\end{longtable}
}

\subsection{The dawn-\co{} error and its diagnosis}
The earliest clear pathology was a dawn collapse of \dpH{} (run \#6,
$-0.059$; error $-1.09\dkh$). The decisive clue was common mode: \emph{both}
absolute pH values fell $\sim0.3$ overnight (ref $8.109\!\to\!7.810$, tank
$8.091\!\to\!7.751$), reversing the daytime upward trend---the signature of a
closed-room \co{} build-up acidifying the aeration water. A natural experiment
confirmed it: on the one ventilated night (run \#3, window open) the absolute
pH stayed high and \dpH{} was a normal $+0.020$, whereas closed nights gave
$-0.058/-0.059$. Crucially, room \co{} is exactly the common-mode variable the
differential is \emph{supposed} to cancel; its leakage into \dpH{} signalled a
broken ref/tank symmetry, not an environmental problem to be ventilated away.

\subsection{Plateau-following and the inter-phase drift conflict}
Measuring to a true plateau (V4) removed the \co{}-\emph{level} dependence: runs
\#11/\#12 gave $\dpH=-0.042$ and $-0.043$ across a 0.4-unit swing in absolute
pH. But the first V4 run had exposed a competing failure: a 31-minute tank
measurement whose pH rose to a peak then \emph{fell} (room \co{} drifting during
the measurement), latching at a value set by whenever the single probe happened
to sample each vessel. This \emph{inter-phase drift}, of order
\begin{equation}
\epsilon_\mathrm{drift} \;\approx\; \Delta t_{\mathrm{tank{-}ref}}\times \frac{dC}{dt},
\label{eq:drift}
\end{equation}
sets up a fundamental conflict with a single probe: full equilibrium needs long
measurements, but long measurements widen the tank--ref sampling gap
$\Delta t$ and thus the drift. The same form with $dT/dt$ explains run \#16,
where an air-conditioner cooling overshoot ($-1.8$\,\textcelsius{} during the
run) coincided with a $+0.166\dkh$ excursion.

\subsection{Sealing collapses both confounds}
A single \emph{sealed common headspace} resolves the conflict at the source. By
compelling the reference and tank to share a single common air volume, it makes
the common \pco{} intrinsic rather than coincidental, blocks room-\co{}
excursions, and additionally suppresses the evaporation that had been
concentrating the open tank aliquot.
The effect was immediate (runs \#14/\#15): the dawn dip collapsed from
$-0.05$ to $-0.008$; the dawn$\to$noon dKH jump shrank $\sim$10$\times$
(from $+0.29$ open to $-0.03$ sealed); and the plateau time was reduced from
$\sim$33 readings ($\sim$50\,min) to $\sim$4 ($\sim$5\,min)---which in turn
collapses $\Delta t$ in Eq.~\eqref{eq:drift}, structurally removing the
inter-phase drift. The uncorrected error fell from $-0.78$ to $\sim-0.18\dkh$.

\subsection{The active anchor and the persistence of a genuine gap}
Sealing alone left a slow headspace drift, because a passive shared air volume
re-equilibrates only by surface diffusion (tens of minutes). Placing an air
stone \emph{in} the 5\,L reference (the ``anchor'') actively pins the shared
\pco{} within minutes; a volume audit confirms the dominance hierarchy
(sample $\sim$3\,\si{\micro mol} $\ll$ headspace $\sim$65\,\si{\micro mol}
$\ll$ 5\,L $\sim$500\,\si{\micro mol}). Yet with the anchor and the net-gate
in place, a $\sim$$-0.046$ to $-0.053$ gap \emph{persisted} even when the tank
reached a verified true plateau (run \#18: 34 readings, 21.6\,min). A
controlled pair of experiments (runs \#19/\#20) then rejected, in turn, four
device-side explanations: doubling the aeration halved the climb time but left
\dpH{} unchanged (\emph{not} kinetics); reversing the measurement order and
swapping hoses did not reverse the sign (\emph{not} order, warm-up, or fluid
path); and a tank started from a higher initial pH settled to the \emph{same}
equilibrium (\emph{not} under-equilibration). The gap was a property of the
\emph{water}.

\subsection{Null experiments localize the error}
Because the device hypotheses were exhausted, we tested the water directly.
A \emph{partial null} (run \#25, fresh seawater in the tank chamber only)
collapsed \dpH{} from $-0.05$ to $-0.010$ (tank pH $+37$\,mpH); at full
equilibrium (run \#26) it gave $\mathrm{dKH}=8.298$, raw error $-0.15$---back in
the good cluster. Swapping fresh water into the tank had recovered almost the
entire error, implicating the aged tank aliquot. The \emph{complete null}
(run \#27), with reference water in \emph{both} vessels so the water difference
is zero by construction, returned $\dpH=-0.003$, $\mathrm{dKH}=8.387$, raw error
$\mathbf{-0.061}$, with both sides at verified true plateaus despite the
$100\,\mathrm{mL}$:$5\,\mathrm{L}$ volume mismatch---a direct confirmation of
volume independence (Sec.~\ref{sec:principle}).

\subsection{Error decomposition and accuracy}
The two nulls decompose the headline error (Table~\ref{tab:budget},
Fig.~\ref{fig:budget}):
\begin{equation}
\underbrace{-0.92\dkh}_{\text{raw}} \;=\;
\underbrace{-0.86\dkh}_{\substack{\text{aged-tank alkalinity loss}\\(\ce{CaCO3}\text{ precip./biofilm})}}
\;+\;
\underbrace{-0.06\dkh}_{\substack{\text{instrument offset}\\(\dpH=-3\,\mathrm{mpH})}}.
\end{equation}
Across the seven-point cluster (runs \#18--24) the \emph{precision} was
$\dpH = -0.0499\pm0.0048$ ($\approx$5\,mpH), $\mathrm{dKH}=7.531\pm0.084$---a
scatter about one-third of the $\pm0.25\dkh$ goal. With the bulk error
identified as a sample artifact and the instrument offset at $-0.06\dkh$
(one-quarter of the goal), the monitor meets $\pm0.25\dkh$ \emph{uncorrected};
zero-point calibration was judged unnecessary, and with normal (non-degraded)
reef water the uncorrected error should fall within $\pm0.1\dkh$.

\begin{table}[t]
\centering
\caption{Error budget after full diagnosis.}
\label{tab:budget}
\footnotesize
\begin{tabular}{@{}lcl@{}}
\toprule
Component & Magnitude & Character / remedy \\
\midrule
Aged-tank alkalinity loss & $-0.86\dkh$ & sample handling; use fresh aliquot \\
Instrument offset & $-0.06\dkh$ & $\dpH=-3$\,mpH; below correction value \\
Precision (1$\sigma$) & $\pm0.08\dkh$ & electrode noise + residual drift \\
Room-\co{} dependence & $\approx 0$ & removed by sealing \\
Evaporation confound & $\approx 0$ & removed by sealing \\
\bottomrule
\end{tabular}
\end{table}

\begin{figure}[t]
\centering
\begin{tikzpicture}
\begin{axis}[
  ybar, bar width=30pt,
  width=0.82\linewidth, height=5.8cm,
  symbolic x coords={Raw,Degrade,Offset},
  xtick=data,
  xticklabels={Raw error,Aged-tank degrade,Instrument offset},
  nodes near coords, nodes near coords align={below},
  every node near coord/.append style={font=\footnotesize,
    /pgf/number format/.cd, fixed, fixed zerofill, precision=2},
  ymin=-1.05, ymax=0.12,
  ylabel={Contribution to error (dKH)},
  tick label style={font=\footnotesize}, label style={font=\small},
  ymajorgrids, major grid style={gray!18},
  enlarge x limits=0.28,
]
\addplot[draw=black, fill=blue!22] coordinates {(Raw,-0.92)(Degrade,-0.86)(Offset,-0.06)};
\draw[gray] (axis cs:Raw,0) -- (axis cs:Offset,0);
\end{axis}
\end{tikzpicture}
\caption{Decomposition of the $-0.92\dkh$ raw error. The complete null isolates
the instrument offset at $-0.06\dkh$ (one-quarter of the $\pm0.25\dkh$ goal); the
partial null attributes the remaining $-0.86\dkh$ to alkalinity loss in the aged
tank aliquot (\ce{CaCO3} precipitation / biofilm)---a sample artifact, not an
instrument fault.}
\label{fig:budget}
\end{figure}

\subsection{Time-resolved breakdown of the null}
The decomposition makes a falsifiable prediction: if the bulk error is sample
chemistry rather than electronics, an otherwise-perfect null should \emph{drift}
as the sample ages, in whichever direction the dominant chemistry dictates. We
tested this by re-running the complete null on the same $100\,\mathrm{mL}$
aliquot over the following day, without touching the instrument
(Fig.~\ref{fig:degrade}, runs \#29--30). The raw error---$-0.061$ and
$-0.014\dkh$ at 0 and 2\,h---first fell to $-0.222\dkh$ at $\sim$14\,h, then
\emph{reversed} to $+0.216\dkh$ at $\sim$18\,h; both extremes were reached at
verified true plateaus (tank 59 and 8 readings), so each is genuine, not a
latching artifact. They are opposite signs of one vulnerability: a long aeration
run (\#29) raises carbonate saturation and drives \ce{CaCO3} precipitation,
lowering alkalinity (KH$\downarrow$), whereas a short run after prolonged
exposure of the small, repeatedly opened aliquot (\#30) lets evaporative
concentration win (KH$\uparrow$). Either way the small exposed aliquot wanders by
$\sim\pm0.2\dkh$ while the instrument offset floor stays at its fresh value. This
is the time-domain confirmation of the error decomposition---and a practical
caveat: a small, aged, exposed aliquot is unreliable in \emph{both} directions,
so the sample must be fresh and adequately sized.

\begin{figure}[t]
\centering
\begin{tikzpicture}
\begin{axis}[
  width=0.84\linewidth, height=6.0cm,
  xlabel={Time since first complete null (h)},
  ylabel={Raw null error (dKH)},
  xmin=-1, xmax=19.5, ymin=-0.33, ymax=0.33,
  grid=both, major grid style={gray!18},
  tick label style={font=\footnotesize}, label style={font=\small},
]
\draw[gray,thick] (axis cs:-1,0) -- (axis cs:19.5,0);
\draw[green!45!black,dashed] (axis cs:-1,0.25) -- (axis cs:19.5,0.25);
\draw[green!45!black,dashed] (axis cs:-1,-0.25) -- (axis cs:19.5,-0.25);
\node[anchor=east,font=\scriptsize,green!40!black] at (axis cs:19.4,0.29) {$\pm0.25\dkh$ goal};
\addplot[blue!70!black, mark=*, thick,
  error bars/.cd, y dir=both, y explicit]
  coordinates {
  (0,-0.061) +- (0,0.08)
  (2,-0.014) +- (0,0.08)
  (14,-0.222) +- (0,0.08)
  (18,0.216) +- (0,0.08)
  };
\node[font=\scriptsize,blue!45!black,align=center] at (axis cs:10.6,-0.135) {precipitation\\KH$\downarrow$};
\node[font=\scriptsize,blue!45!black,align=center] at (axis cs:15.2,0.125) {evaporation\\KH$\uparrow$};
\end{axis}
\end{tikzpicture}
\caption{Time-resolved \emph{bidirectional} drift of the complete null. With
reference water in \emph{both} vessels (water difference zero by construction),
the raw error stays within the $\pm0.08\dkh$ precision (error bars) and the
$\pm0.25\dkh$ goal for the first hours, then wanders as the small
($100\,\mathrm{mL}$), exposed tank aliquot ages: a long aeration run drives
\ce{CaCO3} precipitation (KH$\downarrow$, $-0.22\dkh$ at $\sim$14\,h), while
prolonged exposure lets evaporative concentration win (KH$\uparrow$, $+0.22\dkh$
at $\sim$18\,h). The electronics are unchanged; only the sample alkalinity
drifts, in either direction---confirming that the dominant error term is sample
chemistry (cf.\ Fig.~\ref{fig:budget}).}
\label{fig:degrade}
\end{figure}

% =====================================================================
\section{Discussion}
% =====================================================================
\paragraph{Implications of the error decomposition.} The natural response to a
stable $\sim-0.8\dkh$ offset is to zero-point calibrate. Resisting that---on the
methodological principle that a calibration constant should be applied only
after independent replication, and never to a small non-independent
sample---was decisive, because the offset turned out \emph{not} to be a
constant device property (it varied $\pm0.085\dkh$ across the sealed cluster and
ultimately proved to be mostly degraded sample water). Calibrating it away would
have embedded a sample artifact in the instrument's calibration and masked the
genuine $-0.06\dkh$ floor.

\paragraph{External validation.} Our independently derived error structure
mirrors published behaviour of the commercial AquaWiz, lending it external
support. Community reports identify room-\co{} variation as the dominant error
and a sealed container as the field fix; the manufacturer's own guidance---that
a sharp \co{} change ``only affects readings for about an hour'' and that one
should ``connect the air intake to the skimmer's outdoor air line''---matches
both our $\sim$1-hour inter-phase drift episode and our gas-reference-fixing
remedy (we realize it by sealing rather than by an outdoor line). The
second-most-reported commercial error, bubble-quality degradation from salt
creep ($>2\dkh$ error, clean every six months), matches our aeration-sufficiency
analysis. Reported field accuracy ($\le0.2\dkh$ vs.\ a Hanna checker;
$\le0.75\dkh$ uncalibrated over seven weeks; ``under $0.5\dkh$ = excellent, use
for trend'') brackets our $\pm0.25\dkh$ result and our trend-oriented intent.
Notably, commercial units are managed by periodic calibration and cleaning and do not pursue a
true equilibrium plateau; our plateau-following step extends this further.

\paragraph{Scientific grounding.} The kinetic separation underlying the method
is well established: the aqueous \co{} hydration/dehydration relaxation completes
in $\sim$16\,s \cite{johnson1982}, so chemistry is never rate-limiting;
the slow step is physical gas exchange, $\sim$15\,min for direct
bubbling \cite{takahashi}, consistent with our observed plateau times. The
differential ``$\at{}$ from \pco{}-equilibration plus pH'' principle has a recent
analytical-chemistry basis demonstrated down to $0.5\,\mathrm{mL}$ samples at
$\pm1$--$2\,\si{\micro mol\,kg^{-1}}$ precision \cite{fleger2025}, supporting
small-volume miniaturization as the correct direction.

\paragraph{Limitations.} (i) With a single probe the inter-phase drift of
Eq.~\eqref{eq:drift} cannot be driven to zero; it is only suppressed (by sealing
and by minimizing $\Delta t$). (ii) The dominant historical error was sample
degradation, so the operating discipline---use a fresh, adequately sized tank
aliquot and recirculate rather than store---is part of the instrument, not an
afterthought. (iii) Long plateaus under slow drift can make a measurement run to
hours; the wall-clock caps bound this but a hard external scheduler limit must be
set above the code's 4-hour ceiling. (iv) Absolute pH is informative only as a
within-day \co{} proxy; only \dpH{} is quantitative.

\paragraph{Recommended operation.} Seal the common headspace; anchor the
reference with active aeration; measure tank-then-ref with the two-gate plateau
criterion; use fresh sample water; clean the air path periodically; and treat
the output as a trend instrument calibrated, if at all, against an independent
kit on a monthly cadence keyed to the ref$\leftrightarrow$tank divergence.

% =====================================================================
\section{Conclusion}
% =====================================================================
A reagent-free, single-probe differential-pH aeration monitor can measure reef
carbonate alkalinity to better than $\pm0.25\dkh$ \emph{without} zero-point
calibration, once three design rules are observed: a single sealed common
headspace, plateau-following to true gas equilibrium, and an actively aerated
reference anchor. The value of the eight-day campaign was less in any one number
than in \emph{decomposing} a $-0.92\dkh$ raw error: null experiments showed that
$-0.86\dkh$ of it was alkalinity loss in a degraded sample aliquot and only
$-0.06\dkh$ was the instrument. The differential design delivered its promised
common-mode rejection of room \co{} and probe drift; what remained was chemistry
in a beaker, not error in the electronics. We expect the design rules and the
null-decomposition methodology to transfer to other low-cost alkalinity
instruments.

% ---------------------------------------------------------------
\section*{Reproducibility}
Firmware, the host measurement script (\texttt{measure\_kh\_once.py}), the raw
log (\texttt{dkh.dat}), and the full measurement ledger are available in the
project repository~\cite{repo}.

\section*{Acknowledgments}
This project was completed thanks to the passion of Mango-miyeok of REEF FAMILY
and all the participants of the DIY meetup.

% ---------------------------------------------------------------
\begin{thebibliography}{9}
\bibitem{repo} nowforyou (REEF FAMILY), ``ReefKeeper: open differential-pH
aeration alkalinity monitor (firmware, host scripts, measurement ledger),''
project repository, \url{https://github.com/taeseokyi/reefkeeper}.
\bibitem{johnson1982} K.~S.~Johnson, ``Carbon dioxide hydration and dehydration
kinetics in seawater,'' \emph{Limnol.\ Oceanogr.} \textbf{27}(5), 849--855
(1982). doi:10.4319/lo.1982.27.5.0849.
\bibitem{soli} A.~L.~Soli and R.~H.~Byrne, ``CO\textsubscript{2} system
hydration and dehydration kinetics and the equilibrium CO\textsubscript{2}/H\textsubscript{2}CO\textsubscript{3}
ratio in aqueous NaCl solution,'' \emph{Mar.\ Chem.} (2002).
\bibitem{zeebe2001} R.~E.~Zeebe and D.~Wolf-Gladrow, \emph{CO\textsubscript{2}
in Seawater: Equilibrium, Kinetics, Isotopes}, Elsevier Oceanography Series 65
(2001).
\bibitem{takahashi} T.~Takahashi, ``Methods for measurement of
$p\mathrm{CO_2}$ and total CO\textsubscript{2} in seawater'' (carbonate-system
methodology; direct-bubbling equilibration $\sim$15\,min).
\bibitem{fleger2025} K.~Fleger, X.~Liu, W.~Berelson, J.~Adkins \emph{et al.},
``Total alkalinity measurements in small samples based on
CO\textsubscript{2} equilibration and spectrophotometric pH,''
\emph{Anal.\ Chim.\ Acta} (2025). doi:10.1016/j.aca.2025.344432.
\bibitem{roberts2005} (Gas-stripping first-order equilibration;
$\ln(C_0/C_t)\propto \phi/V$.) Roberts, \emph{Geophys.\ Res.\ Lett.} (2005).
\bibitem{egleston2010} C.~S.~Egleston, C.~L.~Sabine, F.~M.~M.~Morel,
``Revelle (buffer) factor of the seawater carbonate system,''
\emph{Global Biogeochem.\ Cycles} (2010).
\bibitem{community} Reef-hobbyist community field reports on the commercial
AquaWiz alkalinity monitor (room-\co{} error, sealed-container fix, bubble
degradation, manufacturer guidance): Reef2Reef threads \#1159272, \#1073924,
\#1115439; UltimateReef \#939234; Bay Area Reefers \#40433.
\end{thebibliography}

\end{document}

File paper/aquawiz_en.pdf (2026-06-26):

## A Low-Cost Single-Probe Differential-pH Aeration Monitor for Seawater Carbonate Alkalinity: Systematic-Error Decomposition and Sub-0.25 dKH Accuracy via Sealed Common-Headspace Equilibration

nowforyou∗1

1REEF FAMILY

June 27, 2026

Abstract
Carbonate alkalinity (“KH”, expressed in degrees, dKH) is the single most control-critical waterchemistry parameter in reef aquaria, yet affordable continuous monitors are scarce and reagent titration is laborious. We describe an open, reagent-free monitor that infers alkalinity from the equilibrium pH a seawater sample reaches after aeration to atmospheric CO2, using a single pH probe to measure an aquarium sample (“tank”) and a known-alkalinity reference (“ref”) in immediate succession. Because dKH is computed from the pH difference (KHtank = KHref ·10∆pH), absolute probe drift and room-CO2 excursions are common-mode signals that cancel. Over a nine-day instrumented campaign (30 logged measurements across five firmware/method revisions) we observed a persistent uncorrected error of −0.92 dKH and, rather than zero-point calibrating it away, decomposed it. Three interventions—(i) plateau-following measurement to true gas equilibrium, (ii) a single sealed common headspace shared by sample, reference and pump intake, and (iii) an actively aerated 5 L reference anchor that pins the headspace pCO2—collapsed the dawn-CO2 error and the diurnal evaporation confound, and shrank measurement scatter to SD = ±0.08 dKH (about one-third of the ±0.25 dKH design goal). A sequence of null experiments (identical water in both vessels, true ∆pH = 0) then localized the residual: a complete null returned ∆pH = −0.003, dKH = 8.387, i.e. an instrument offset of only −0.06 dKH. The remaining −0.86 dKH was traced to alkalinity loss (CO2 driven CaCO3 precipitation / biofilm) in the days-old, small, open tank aliquot—a sample-handling artifact, not a measurement fault. Re-running the null on the same aged aliquot over the following day showed the offset drifting away from zero (−0.22 then +0.22 dKH on successive runs) with the electronics untouched, confirming the attribution in the time domain. The instrument therefore meets the ±0.25 dKH goal uncorrected, with zero-point calibration deemed unnecessary. Our independently obtained error structure (room-CO2 sensitivity, bubble-quality dependence, sealing as the remedy) reproduces
the published behaviour of a commercial counterpart, providing external validation of both the diagnosis and the remedy.

Keywords: reef aquarium; carbonate alkalinity; total alkalinity; CO2 equilibration; differential pH; low-cost instrumentation; common-mode rejection; CaCO3 precipitation.

∗Correspondence: taeseokyi@gmail.com

## 1 Introduction

Stony corals and other calcifying reef organisms deposit calcium carbonate at a rate that continuously consumes carbonate alkalinity. In a closed reef aquarium the resulting alkalinity drawdown is fast (often 0.5–1.5 dKH day−1
) and swings of more than ∼ 1 dKH are implicated in coral tissue stress. Alkalinity (AT, conventionally reported by hobbyists as “KH” in German degrees, 1 dKH ≈ 0.357 meq L−1
) is therefore the parameter most worth measuring often. The accessible options are unsatisfying for continuous use. Manual reagent titration (e.g. commercial drop kits) is accurate but labour-intensive and discrete. Colorimetric robots automate titration but consume reagent and are expensive. Direct potentiometric pH alone is not an alkalinity measurement, because seawater pH depends jointly on AT and pCO2
, and aquarium pCO2 varies strongly over the day (room ventilation, photosynthesis, respiration).
A reagent-free alternative exploits the fact that if a sample is aerated until its pCO2 equilibrates
with the surrounding air, the equilibrium pH becomes a single-valued function of alkalinity at fixed temperature and salinity. A commercial product (AquaWiz) is built on this principle and is used by reef hobbyists, but community reports document recurring inaccuracy tied to room-CO2 fluctuation and to aeration/bubble quality. The contribution of this paper is not the principle but a quantitative diagnosis: starting from a working DIY build, we conduct a nine-day instrumented campaign, expose a −0.92 dKH raw error, and show by construction (null experiments) that essentially all of it is a sample-handling artifact rather than an instrument limitation—reducing the true instrument offset to −0.06 dKH and meeting a ±0.25 dKH goal without calibration. Along the way we establish a small set of design rules (sealed common headspace; plateau-following to true equilibrium; an actively aerated reference anchor; a two-gate plateau criterion) that we expect to generalize to any single-probe differential-pH alkalinity monitor.

## 2 Measurement Principle

### 2.1 Aeration makes equilibrium pH a proxy for alkalinity

At fixed temperature T and salinity S, the seawater carbonate system has two degrees of freedom; fixing any two of {AT, DIC, pCO2

, pH} determines the rest. Aeration with a large excess of room air drives the dissolved CO2 toward Henry’s-law equilibrium with the gas phase, [CO2]aq = KH pCO2 ,
so that pCO2

(water) → pCO2
(air). Once pCO2
is clamped by the atmosphere, the equilibrium pH is a single-valued function of alkalinity:

pHeq = f(AT, pCO2

, T, S). | (1)

With pCO2

, T, S held common, the only variable that can move pHeq is AT. Measured equilibrium pH is therefore a proxy for alkalinity.

### 2.2 Why the differential cancels room CO2

The instrument never relies on the absolute value of pCO2

. It aerates the reference and the tank sample to the same atmospheric ceiling (in the final design, by aerating both against one shared headspace simultaneously, Sec. 4) and reports the difference of their equilibrium pH. Because the absolute pCO2

term is common to both samples, it cancels in the difference: a room-CO2 excursion is a common-mode signal that drops out. What survives the subtraction is the true alkalinity difference plus electrode noise (±0.005–0.01 pH). This is the central robustness argument of the method, and the reason a single probe (rather than two matched probes) is used: a single sensor’s slow asymmetry-potential and reference-junction drift load identically onto both readings and cancel in ∆pH.

### 2.3 Over-aeration is impossible; only insufficient aeration errs

Equation (1) has a hard ceiling at pCO2

(air): once the water reaches atmospheric equilibrium, further aeration cannot raise pH. There is consequently no “over-aeration” failure mode. Error enters only through insufficiency: if residual CO2 remains in one vessel, that side’s pH is unfairly depressed and a spurious ∆pH appears. The differential’s assumption is precisely that ref and tank share the same pCO2

; broken symmetry breaks the cancellation. This motivates measuring to a genuine plateau rather than for a fixed time (Sec. 4).

### 2.4 Volume independence at full equilibrium

Equation (1) contains no volume term (Henry’s law is intensive). Hence even a large volume mismatch—in our final null, 100 mL of tank water against a 5 L reference—produces zero differential error provided both vessels reach full equilibrium. The familiar “equal volumes for symmetry” rule applies only under partial equilibration, where unequal volumes sit at different points on the first-order approach curve C(t) − C

∗ = (C0 − C

∗
) e

−t/τ . The true requirements are just (a) both fully equilibrated and (b) matched pCO2 and T. The larger volume is rate-limiting, with a time constant

τ ∝

V

KH Qgas

β ∼

1
VVM
β, | (2)

where VVM = Qgas/V is gas volume per liquid volume per minute and β is a seawater chemical factor (only trace [CO2]aq is strippable; the Revelle buffering raises τ by ∼ 8–15×). Equation (2) is the basis for the “increase aeration to shorten the measurement” lever discussed later, and for the choice to miniaturize the rate-limiting reference.

### 2.5 The differential dKH formula

The firmware (Arduino Nano / ATmega328P; pH via DFRobot Gravity probe + ADS1115 16-bit ADC) digitizes one probe, reading reference then tank pH, and computes

KHtank = KHref · 10−(pHref−pHtank) = KHref · 10∆pH | (3)

with ∆pH ≡ pHtank −pHref and KHref = 8.448 dKH an EEPROM-stored anchor constant (set by a calref command after evaporation top-off; not a per-run measurement—this is why the reference column reads a constant 8.448 in every log line). Equation (3) depends only on ∆pH; absolute pH cancels exactly. Differentiating,

d KHtank
d ∆pH
∆pH=0

= KHref ln 10 ≈ 19.45 dKH pH−1
, | (4)

i.e. 0.01 pH of uncancelled difference maps to ≈ 0.19 dKH. This high sensitivity is what makes both the cancellation and the plateau criterion matter. Temperature compensation is applied per reading by a Nernst relation pHcorr = 7.0+ (pHraw −7.0) (273.15+Tcal)/(273.15+Tmeas), nominally zero-error over 15–35 ℃. Each pH reading is a trimmed mean of 64 samples (discard the top and bottom 16, average the middle 32) to reject aeration-bubble spikes.

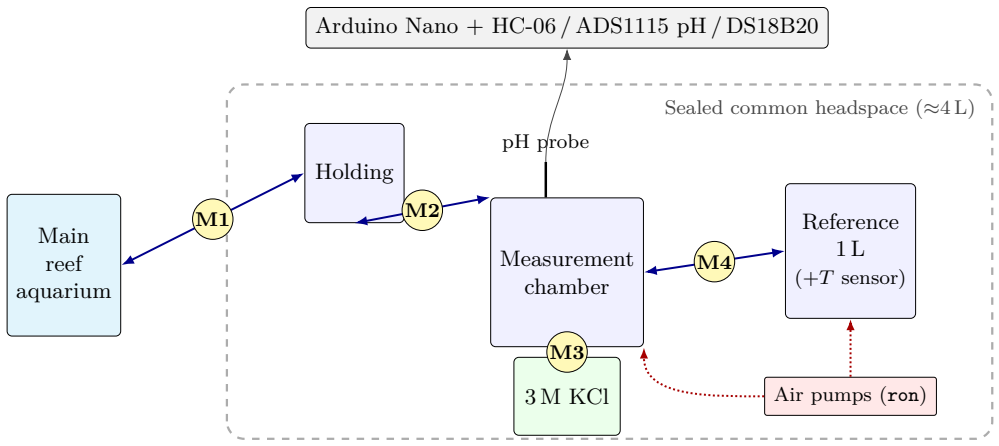
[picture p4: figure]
Sealed common headspace (≈4 L); Main reef aquarium; Holding; Measurement chamber; Reference 1 L; (+T sensor); 3 M KCl; Air pumps (ron); pH probe

Arduino Nano + HC-06 / ADS1115 pH / DS18B20

Figure 1: Schematic of the sealed closed-loop monitor. A single pH probe in the measurement chamber reads the tank aliquot and the reference in turn; four bidirectional peristaltic pumps (M1–M4) move liquid between the main aquarium, holding beaker, measurement chamber, reference reservoir, and KCl store; two air pumps (ron) aerate the reference and the chamber simultaneously. The reference, chambers and pump intakes share one sealed headspace (≈4 L), so sample and reference see identical pCO2
and evaporation is
suppressed; the controller sits outside. Between runs the probe rests in 3 M KCl (M3).

## 3 Apparatus

The build (Table 1, Fig. 1) is a closed fluidic loop around four bidirectional peristaltic pumps, two USB air pumps, a single pH probe, and a 1-Wire temperature sensor, all driven by an Arduino Nano over a 9600-baud Bluetooth (HC-06) serial link to a host PC.

Fluidic topology (current). All pumps are bidirectional (f = forward, b = reverse):
- M1: main aquarium ↔ holding beaker;
- M2: holding ↔ measurement chamber;
- M3: 3 M KCl beaker ↔ measurement chamber (probe soak / storage);
- M4: 5 L reference ↔ measurement chamber.
Routing the tank sample through an intermediate holding beaker lets it be temporarily parked while the reference is measured, minimizing the between-phase delay (Sec. 4). Run times are encoded as the integer in mXf:NN / mXb:NN (seconds); reverse runs ∼8–10 s longer than forward to fully clear the hose (current values m1f:70/m1b:82, m2f:60/m2b:68, m3f:60/m3b:68, m4f:60/m4b:70; the 5 L hose is longest, hence m4b:70).

Control commands. Air and motor enables are independent lines: ron turns both air pumps on (used only while liquid is stationary—bubble cleaning and measurement); ton enables the PWM motor controller (required before any pump will turn); airoff drops both. A load-bearing invariant follows: because airoff also disables the PWM controller, every liquid move must be preceded by airoff → ton; the last air command before a motor must be ton. Measurement primitives are tank / ref (sample and store one pH reading) and calkh (apply Eq. (3)).

Sealed common headspace (required). The 5 L reference, the measurement chamber, and the pump intake share one sealed headspace. This is not an optional refinement: it (i) guarantees tank and ref see identical pCO2

at the instant of measurement (the differential’s premise), (ii) blocks

Table 1: Bill of materials (current build).

Subsystem | Part | Qty
Microcontroller | Arduino Nano V3.0 (ATmega328P) | 1
pH probe | DFRobot Gravity pH V2 (SEN0161-V2), single glass elec- trode | 1
ADC | DFRobot Gravity I²C ADS1115 (16-bit) | 1
Temperature | DS18B20 waterproof (1-Wire), in the 5 L reference | 1
Comms | HC-06 Bluetooth, 9600 baud | 1
Pumps | NKP-DC-B06B 12 V peristaltic, bidirectional (M1–M4) | 4
Motor drivers | L298 2 A modules (2 for pumps, 1 for air) | 3
Air pumps | USB 5 V, switched together (ron) | 2
Reference reservoir | 5 L sealed container (“Wiz tank”) | 1
Chambers | 200 mL beakers: holding, measurement, 3 M KCl | 3
Probe storage | 3 M KCl (≈22 % w/v) | —

room-CO2 excursions at the source, and (iii) suppresses evaporation. In the final configuration the headspace is ≈4 L, the reference ≈1 L, and the tank aliquot 100 mL; an air stone placed in the reference actively pins the shared pCO2 within minutes (the “anchor”, Sec. 4). Separate or isolated headspaces are explicitly forbidden—two headspaces drift independently and destroy the cancellation.

## 4 Methods

### 4.1 Two-phase plateau-following cycle (V4)

Plateau detection is a host-side decision loop, so the PC script drives the firmware step by step. The cycle measures tank first, then ref, so the 5 L reference is co-aerated throughout the tank phase and converges quickly when its turn comes:
1. Prep: m3b (drain KCl from chamber) → m1f (aquarium → holding) → m2f (holding → chamber).
2. Phase A: ron; measure tank every 30 s until plateau (chamber tank + 5 L aerated together).
3. Transition: m2b parks the tank aliquot back in holding; m4f brings reference into the chamber.
4. Phase B: ron; measure ref until plateau (fast—already near equilibrium).
5. calkh; then cleanup: m4b (recover ref to 5 L), m1b (return parked tank to aquarium), m3f (restore KCl soak), airoff (probe rests in KCl).

### 4.2 Two-gate plateau criterion

Readings are held as integer milli-pH (mpH) to avoid floating-point boundary jitter. A plateau is declared only when both gates hold over a sliding window (Table 2): a short span gate (last 4 readings, max − min ≤ 2 mpH) rejects noise, and a longer net gate (last 8 readings, |w−1 − w0| ≤ 1 mpH) rejects a slow monotonic exponential tail that the span gate alone would mistake for convergence. The longer net look-back (8 vs. 4 points; “B1”) was the fix for early latches in which the tank stopped climbing prematurely. Per-phase wall-clock and read-count caps (PHASE_MAX = 7200 s, MEAS_MAX = 240) and a consecutive-failure cap (FAIL_MAX = 5) bound the loop so it can never hang.
Figure 2 shows a measured pair of approach curves. The tank, freshly drawn into the chamber, climbs a slow first-order tail toward its ceiling and is held by the net gate until it is genuinely flat

Table 2: Plateau-following parameters (measure_until_flat).

Constant | Value | Meaning
FLAT_SPAN_N | 4 | span window (jitter gate)
FLAT_SPAN_MPH | 2 | last 4: max − min ≤ 2 mpH
FLAT_NET_N | 8 | net look-back (drift gate; B1)
FLAT_NET_MPH | 1 | last 8: |w−1 − w0| ≤ 1 mpH
MEAS_INTERVAL | 30 s | between readings (aeration continuous)
PHASE_MAX_SECS | 7200 s | per-phase cap (2 h; 4 h total)
MEAS_MAX | 240 | per-phase read cap
FAIL_MAX | 5 | consecutive parse failures tolerated

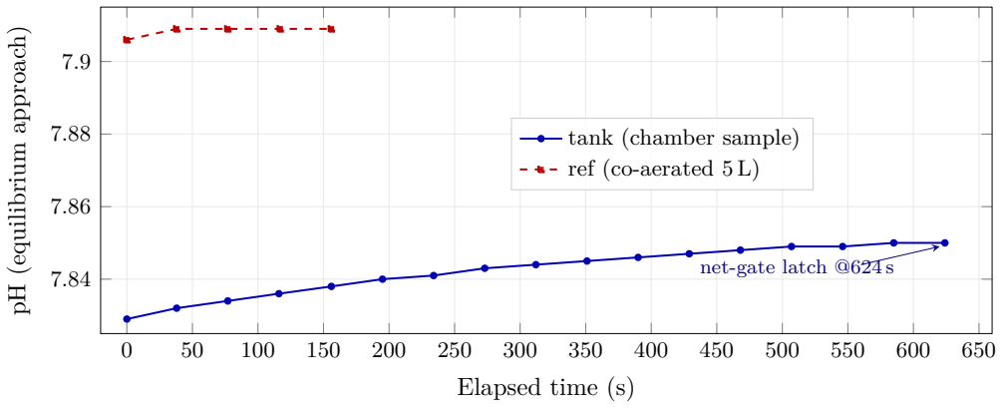
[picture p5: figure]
net-gate; latch @624 s; Elapsed time (s); pH (equilibrium approach); tank (chamber; sample); ref (co-aerated

Figure 2: Measured plateau-following curves (sealed, net-gate run). The tank sample (solid) climbs a slow exponential tail and is latched only when the two-gate criterion (last-4 span ≤ 2 mpH and last-8 net ≤ 1 mpH) is met; the co-aerated reference (dashed) is already near equilibrium and latches quickly. The two series sit at different pH because the underlying samples differ (this run predates the null campaign); only their respective plateau values enter Eq. (3).

(latching at ∼624 s when the 8-point net drift falls to 1 mpH). The reference, having co-aerated in the 5 L reservoir throughout the tank phase, is already at equilibrium and latches in ∼2.6 min—a direct illustration of why measuring tank-first is faster, and of why the span gate alone (satisfied near ∼546 s) would have latched the tank early.

### 4.3 Logging and fault handling

Each completed run appends one line HH ref_pH tank_pH 8.448 tank_kh temp to dkh.dat. Two distinct markers encode abnormal outcomes: an all-zeros line on hard failure (timeout, serial loss, or unverified KCl soak), which additionally latches—a subsequent run refuses to measure and rewrites the marker until a human clears it, protecting the probe from unattended pump cycling; and a negative tank_kh (magnitude preserved, sign flipped) when a phase hits its cap without reaching plateau, which the data server reads as “did-not-plateau” but which does not trip the latch. A finally block runs an emergency cleanup (air off, drain chamber, restore KCl soak) on any non-completion.

Table 3: Method/firmware revisions. “ron held” = continuous aeration between runs.

Rev | Period | Change vs. prior
V0 | 6/14–6/15 | First symmetric build; reference drawn from 5 L into a cup; fixed 1200 s aeration.
V1 | 6/15–6/16 | Added continuous aeration between runs (ron held).
V2 | 6/16–6/17 | Reference taken as a small directly-aerated aliquot (holding → chamber); aeration off during the reading.
V3 | 6/17 | Aeration during measurement (pin tank/ref to same pCO2 ); path symmetrized; KCl-rinse bubble clean (later dropped).
V4 | 6/17→ | Plateau-following to true equilibrium (no fixed time); two-phase tank-then-ref; anti-hang caps; emergency cleanup. Subsequently: sealed common headspace, 5 L active anchor, and the two-gate (B1) criterion.

### 4.4 Null-test protocol

The diagnostic backbone is the null test: the reference and tank vessels are filled with the same water so the true alkalinity difference is zero and the correct output is exactly ∆pH = 0, dKH = 8.448. Two variants are used. In a partial null, only the small tank aliquot is replaced with fresh seawater while the aged 5 L reference is retained, so a change in ∆pH isolates the tank water’s contribution. In a complete null, reference water is also placed in the tank chamber, so the water difference is zero by construction and any residual ∆pH is purely instrumental.

### 4.5 Revision history and the one-change-at-a-time rule

The build evolved through five revisions (Table 3). Changes were made one causal axis at a time, so that each measurement campaign tests a single mechanism; where two constants were changed together (e.g. stabilization window and convergence band), they were justified as the same causal axis (response completeness), not two independent variables.

## 5 Results

Table 4 lists the full campaign. Throughout, ∆pH < 0 means the tank read more acidic than the reference (lower apparent alkalinity), and by Eq. (3) the raw error is dKH−8.448 = 8.448 (10∆pH − 1).

Table 4: Complete measurement campaign (30 runs). “abs pH” is the common-mode level (a room-CO2 proxy within a single day only). Config abbreviations: S = sealed headspace, A = 5 L active anchor, N = net-gate, B1 = net look-back 8. Null staging: a fresh seawater batch is aliquoted at the start; PN = partial null (the 100 mL tank chamber alone is refilled with that fresh aliquot while the aged 5 L reference is kept, isolating the tank-water contribution); CN = complete null (reference water is then transferred into the tank chamber as well, so both vessels hold identical water and the water difference is zero by construction).

# Date/time | Cfg | pHref | pHtank | ∆pH | dKH | T Conditions

1 06-14 20:12 V0 | 7.959 | 8.021 +0.062 | 9.741 | 26.7 first manual symmetric run
2 06-14 21:00 V0 | 7.997 | 8.072 +0.075 | 10.054 | 26.2 —
3 06-15 05:00 V0 | 8.057 | 8.077 +0.020 | 8.843 | 26.4 dawn but +; window open (venti-
| | | | | | lated), low CO2
4 06-15 13:00 V1 | 8.050 | 8.042 −0.008 | 8.293 | 27.0 first continuous aeration

continued on next page

Table 4 (continued)

# Date/time | Cfg | pHref | pHtank | ∆pH | dKH | T Conditions

5 06-15 21:00 V1 | 8.109 | 8.091 −0.018 | 8.109 | 27.3 clean low-CO2 point
6 06-16 05:00 V1 | 7.810 | 7.751 −0.059 | 7.362 | 27.5 dawn closed-room CO2 spike (both
| | | | | | abs pH fell ∼0.3)
7 06-16 13:00 V1b | 8.091 | 8.063 −0.028 | 7.922 | 27.7 tighter window/band
– 06-16 21:00 — | failed (0.000; power cut, port semaphore)
8 06-16 21:21 V2 | 8.042 | 8.021 −0.021 | 8.039 | 28.6 first V2 (manual)
9 06-17 05:00 V2 | 7.997 | 7.939 −0.058 | 7.386 | 27.8 V2 dawn test failed; regressed to V1
10 06-17 13:00 V3 | 8.109 | 8.091 −0.018 | 8.095 | 28.2 first V3; ref under-equilibrated (5
| | | | | | reads)
11 06-17 21:00 V4 | 8.113 | 8.071 −0.042 | 7.669 | 27.8 first V4 + trim-mean firmware; clean
| | | | | | plateaus
12 06-18 05:00 V4 | 7.738 | 7.695 −0.043 | 7.657 | 28.2 decisive: dawn −0.043 ≈ evening
| | | | | | −0.042 despite 0.4 abs-pH swing ⇒ CO2-level independence
13 06-18 13:00 V4 | 8.081 | 8.055 −0.026 | 7.950 | 28.3 same low CO2 as #11 yet −0.026;
| | | | | | dKH +0.29 jump ⇒ baseline not con- stant (evaporation, open 200 mL day 5)
14 06-19 05:00 V4+S | 7.976 | 7.968 −0.008 | 8.283 | 28.1 seal verif. ⃝1 : | dawn dip collapses
| | | | | | −0.05→−0.008; plateau 33→4 reads
15 06-19 13:00 V4+S | 7.957 | 7.947 −0.010 | 8.255 | 28.6 seal verif. ⃝2 : | dawn→noon jump
| | | | | | +0.29 → −0.03 (∼10×); evaporation removed
16 06-19 21:00 V4+S | 7.969 | 7.968 −0.001 | 8.421 | 26.8 near-perfect null (raw err −0.027,
| | | | | | smallest); but +0.166 vs. #14/15 ⇒ offset not a perfect constant; AC tran- sient (−1.8 ℃)
17 06-20 05:00 V4+S | 7.922 | 7.871 −0.051 | 7.521 | 27.7 dawn dip recurs; tank 11× monotone
| | | | | | = early latch (not true plateau); AC cooling slowed kinetics
18 06-20 15:00 V4+SAN | 7.975 | 7.929 −0.046 | 7.602 | 27.1 first 5 L anchor; tank true plateau
| | | | | | (34×, 21.6 min) yet −0.046 ⇒ gen- uine gap, not latch artifact
19 06-20 18:11 V4+S,2× 7.979 | 7.924 −0.055 | 7.443 | 26.4 controlled exp; 2× aeration halves
| | | | | | climb (1296→711 s) but ∆pH un- changed ⇒ not kinetics
20 06-20 18:57 V4+S,2× 7.975 | 7.931 −0.044 | 7.636 | 26.7 ref-first + hose swap; gap persists
| | | | | | ⇒ order/path/non-equilibrium all re- jected
21 06-20 19:50 V4+S | 7.975 | 7.926 −0.049 | 7.539 | 26.9 reproduction
22 06-20 20:29 V4+SA | 7.977 | 7.921 −0.056 | 7.426 | 26.9 tank-first+park; ref fastest ever (4×);
| | | | | | tank early latch (7.921) ⇒ motivates B1
23 06-20 21:00 V4+SA,B1 | 7.979 | 7.926 −0.053 | 7.474 | 27.0 B1 ok: tank 25×/945 s true plateau;
| | | | | | confirms #22 was ∼5 mpH short; gap (7th)
24 06-21 05:00 V4+SA,B1 | 7.974 | 7.928 −0.046 | 7.594 | 26.7 dawn matches evening cluster ⇒ time-
| | | | | | of-day dependence ruled out (gap, 8th)
25 06-21 06:00 V4+S,PN | 7.973 | 7.963 −0.010 −8.255 | 26.7 partial null: fresh tank only; tank
| | | | | | pH +37 mpH, ∆pH −0.05 → −0.010; tank not plateaued (old cap) ⇒ lower bound
26 06-21 13:00 V4+S,PN | 7.964 | 7.956 −0.008 | 8.298 | 27.2 partial null, full eq.: dKH 8.298,
| | | | | | raw err −0.15; back in good cluster; 4 h cap validated
27 06-21 19:00 V4+S,CN | 7.960 | 7.957 −0.003 | 8.387 | 27.4 complete null: reference water into
| | | | | | tank chamber too ⇒ both identical; raw err −0.061 = pure instrument off- set; 100 mL vs. 5 L cancels

continued on next page

Table 4 (continued)

# Date/time | Cfg | pHref | pHtank | ∆pH | dKH | T Conditions

28 06-21 21:00 V4+S,CN | 7.959 | 7.958 −0.001 | 8.434 | 27.4 complete null (2nd): ∆pH − 0.001
| | | | | | (resolution limit), raw err −0.014 (smallest); reconfirms the ≤ 0.06 dKH offset
– 06-22 05:00 V4+S,CN | failed (cap) | 55-min scheduler cap killed it mid-ref;
| | | | | | tank had plateaued (7.955); fix: 5 h cap
29 06-22 09:00 V4+S,CN | 7.959 | 7.948 −0.011 | 8.226 | 27.4 aged complete null (∼14 h, 100 mL
| | | | | | exposed aliquot): null decayed to raw err −0.22; tank true plateau 59× (long aeration drives precipitation, KH↓)
30 06-22 13:00 V4+S,CN | 7.950 | 7.961 +0.011 | 8.664 | 27.6 aged null reverses (∼18 h): short
| | | | | | plateau (tank 8×), ∆pH > 0, dKH 8.664 (raw err +0.22) ⇒ evaporative concentration (KH↑) overtakes precip- itation

### 5.1 The dawn-CO2 error and its diagnosis

The earliest clear pathology was a dawn collapse of ∆pH (run #6, −0.059; error −1.09 dKH). The decisive clue was common mode: both absolute pH values fell ∼ 0.3 overnight (ref 8.109 → 7.810, tank 8.091 → 7.751), reversing the daytime upward trend—the signature of a closed-room CO2 build-up acidifying the aeration water. A natural experiment confirmed it: on the one ventilated night (run #3, window open) the absolute pH stayed high and ∆pH was a normal +0.020, whereas closed nights gave −0.058/ − 0.059. Crucially, room CO2 is exactly the common-mode variable the differential is supposed to cancel; its leakage into ∆pH signalled a broken ref/tank symmetry, not an environmental problem to be ventilated away.

### 5.2 Plateau-following and the inter-phase drift conflict

Measuring to a true plateau (V4) removed the CO2-level dependence: runs #11/#12 gave ∆pH = −0.042 and −0.043 across a 0.4-unit swing in absolute pH. But the first V4 run had exposed a competing failure: a 31-minute tank measurement whose pH rose to a peak then fell (room CO2 drifting during the measurement), latching at a value set by whenever the single probe happened to sample each vessel. This inter-phase drift, of order

ϵdrift ≈ ∆ttank−ref ×

dC
dt , | (5)

sets up a fundamental conflict with a single probe: full equilibrium needs long measurements, but long measurements widen the tank–ref sampling gap ∆t and thus the drift. The same form with dT /dt explains run #16, where an air-conditioner cooling overshoot (−1.8 ℃ during the run) coincided with a +0.166 dKH excursion.

### 5.3 Sealing collapses both confounds

A single sealed common headspace resolves the conflict at the source. By compelling the reference
and tank to share a single common air volume, it makes the common pCO2 | intrinsic rather than
coincidental, blocks room-CO2 excursions, and additionally suppresses the evaporation that had been concentrating the open tank aliquot. The effect was immediate (runs #14/#15): the dawn dip collapsed from −0.05 to −0.008; the dawn→noon dKH jump shrank ∼10× (from +0.29 open

to −0.03 sealed); and the plateau time was reduced from ∼33 readings (∼50 min) to ∼4 (∼5 min)— which in turn collapses ∆t in Eq. (5), structurally removing the inter-phase drift. The uncorrected error fell from −0.78 to ∼ −0.18 dKH.

### 5.4 The active anchor and the persistence of a genuine gap

Sealing alone left a slow headspace drift, because a passive shared air volume re-equilibrates only by surface diffusion (tens of minutes). Placing an air stone in the 5 L reference (the “anchor”) actively pins the shared pCO2 within minutes; a volume audit confirms the dominance hierarchy (sample ∼3 µmol ≪ headspace ∼65 µmol ≪ 5 L ∼500 µmol). Yet with the anchor and the net-gate in place, a ∼−0.046 to −0.053 gap persisted even when the tank reached a verified true plateau (run #18: 34 readings, 21.6 min). A controlled pair of experiments (runs #19/#20) then rejected, in turn, four device-side explanations: doubling the aeration halved the climb time but left ∆pH unchanged (not kinetics); reversing the measurement order and swapping hoses did not reverse the sign (not order, warm-up, or fluid path); and a tank started from a higher initial pH settled to the same equilibrium (not under-equilibration). The gap was a property of the water.

### 5.5 Null experiments localize the error

Because the device hypotheses were exhausted, we tested the water directly. A partial null (run #25, fresh seawater in the tank chamber only) collapsed ∆pH from −0.05 to −0.010 (tank pH +37 mpH); at full equilibrium (run #26) it gave dKH = 8.298, raw error −0.15—back in the good cluster. Swapping fresh water into the tank had recovered almost the entire error, implicating the aged tank aliquot. The complete null (run #27), with reference water in both vessels so the water difference is zero by construction, returned ∆pH = −0.003, dKH = 8.387, raw error −0.061, with both sides at verified true plateaus despite the 100 mL:5 L volume mismatch—a direct confirmation of volume independence (Sec. 2).

### 5.6 Error decomposition and accuracy

The two nulls decompose the headline error (Table 5, Fig. 3):

−0.92 dKH | {z }

raw

= −0.86 dKH | {z }

aged-tank alkalinity loss
(CaCO3 precip./biofilm)
+ −0.06 dKH | {z }

instrument offset
(∆pH=−3 mpH)
. | (6)

Across the seven-point cluster (runs #18–24) the precision was ∆pH = −0.0499±0.0048 (≈5 mpH), dKH = 7.531 ± 0.084—a scatter about one-third of the ±0.25 dKH goal. With the bulk error identified as a sample artifact and the instrument offset at −0.06 dKH (one-quarter of the goal), the monitor meets ±0.25 dKH uncorrected; zero-point calibration was judged unnecessary, and with normal (non-degraded) reef water the uncorrected error should fall within ±0.1 dKH.

### 5.7 Time-resolved breakdown of the null

The decomposition makes a falsifiable prediction: if the bulk error is sample chemistry rather than electronics, an otherwise-perfect null should drift as the sample ages, in whichever direction the dominant chemistry dictates. We tested this by re-running the complete null on the same 100 mL aliquot over the following day, without touching the instrument (Fig. 4, runs #29–30). The raw error—−0.061 and −0.014 dKH at 0 and 2 h—first fell to −0.222 dKH at ∼14 h, then reversed to +0.216 dKH at ∼18 h; both extremes were reached at verified true plateaus (tank 59 and 8

Table 5: Error budget after full diagnosis.

Component | Magnitude | Character / remedy
Aged-tank alkalinity loss | −0.86 dKH | sample handling; use fresh aliquot
Instrument offset | −0.06 dKH | ∆pH = −3 mpH; below correction value
Precision (1σ) | ±0.08 dKH | electrode noise + residual drift
Room-CO2 dependence | ≈ 0 | removed by sealing
Evaporation confound | ≈ 0 | removed by sealing
Raw error | Aged-tank degrade | Instrument offset

−1

−0.5

0

−0.92

−0.86

−0.06

Contribution to error (dKH)

Figure 3: Decomposition of the −0.92 dKH raw error. The complete null isolates the instrument offset at −0.06 dKH (one-quarter of the ±0.25 dKH goal); the partial null attributes the remaining −0.86 dKH to alkalinity loss in the aged tank aliquot (CaCO3 precipitation / biofilm)—a sample artifact, not an instrument fault.

readings), so each is genuine, not a latching artifact. They are opposite signs of one vulnerability: a long aeration run (#29) raises carbonate saturation and drives CaCO3 precipitation, lowering alkalinity (KH↓), whereas a short run after prolonged exposure of the small, repeatedly opened aliquot (#30) lets evaporative concentration win (KH↑). Either way the small exposed aliquot wanders by ∼ ±0.2 dKH while the instrument offset floor stays at its fresh value. This is the timedomain confirmation of the error decomposition—and a practical caveat: a small, aged, exposed aliquot is unreliable in both directions, so the sample must be fresh and adequately sized.

## 6 Discussion

Implications of the error decomposition. The natural response to a stable ∼ −0.8 dKH offset is to zero-point calibrate. Resisting that—on the methodological principle that a calibration constant should be applied only after independent replication, and never to a small non-independent sample—was decisive, because the offset turned out not to be a constant device property (it varied ±0.085 dKH across the sealed cluster and ultimately proved to be mostly degraded sample water). Calibrating it away would have embedded a sample artifact in the instrument’s calibration and masked the genuine −0.06 dKH floor.

External validation. Our independently derived error structure mirrors published behaviour of the commercial AquaWiz, lending it external support. Community reports identify room-CO2 variation as the dominant error and a sealed container as the field fix; the manufacturer’s own guidance—that a sharp CO2 change “only affects readings for about an hour” and that one should

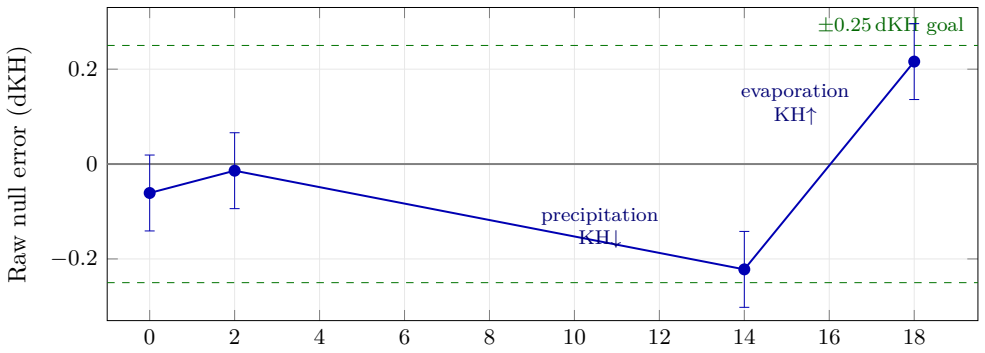
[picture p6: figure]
±0.25 dKH goal; precipitation KH↓; evaporation KH↑; Raw null error (dKH)

Time since first complete null (h)

Figure 4: Time-resolved bidirectional drift of the complete null. With reference water in both vessels (water difference zero by construction), the raw error stays within the ±0.08 dKH precision (error bars) and the ±0.25 dKH goal for the first hours, then wanders as the small (100 mL), exposed tank aliquot ages: a long aeration run drives CaCO3 precipitation (KH↓, −0.22 dKH at ∼14 h), while prolonged exposure lets evaporative concentration win (KH↑, +0.22 dKH at ∼18 h). The electronics are unchanged; only the sample alkalinity drifts, in either direction—confirming that the dominant error term is sample chemistry (cf. Fig. 3).

“connect the air intake to the skimmer’s outdoor air line”—matches both our ∼1-hour inter-phase drift episode and our gas-reference-fixing remedy (we realize it by sealing rather than by an outdoor line). The second-most-reported commercial error, bubble-quality degradation from salt creep (> 2 dKH error, clean every six months), matches our aeration-sufficiency analysis. Reported field accuracy (≤ 0.2 dKH vs. a Hanna checker; ≤ 0.75 dKH uncalibrated over seven weeks; “under 0.5 dKH = excellent, use for trend”) brackets our ±0.25 dKH result and our trend-oriented intent. Notably, commercial units are managed by periodic calibration and cleaning and do not pursue a true equilibrium plateau; our plateau-following step extends this further.

Scientific grounding. The kinetic separation underlying the method is well established: the aqueous CO2 hydration/dehydration relaxation completes in ∼16 s [2], so chemistry is never rate-limiting; the slow step is physical gas exchange, ∼15 min for direct bubbling [5], consistent with our observed plateau times. The differential “AT from pCO2
-equilibration plus pH” principle has a recent analytical-chemistry basis demonstrated down to 0.5 mL samples at ±1–2 µmol kg−1 precision [6], supporting small-volume miniaturization as the correct direction.

Limitations. (i) With a single probe the inter-phase drift of Eq. (5) cannot be driven to zero; it is only suppressed (by sealing and by minimizing ∆t). (ii) The dominant historical error was sample degradation, so the operating discipline—use a fresh, adequately sized tank aliquot and recirculate rather than store—is part of the instrument, not an afterthought. (iii) Long plateaus under slow drift can make a measurement run to hours; the wall-clock caps bound this but a hard external scheduler limit must be set above the code’s 4-hour ceiling. (iv) Absolute pH is informative only as a within-day CO2 proxy; only ∆pH is quantitative.

Recommended operation. Seal the common headspace; anchor the reference with active aeration; measure tank-then-ref with the two-gate plateau criterion; use fresh sample water; clean the air path periodically; and treat the output as a trend instrument calibrated, if at all, against an independent kit on a monthly cadence keyed to the ref↔tank divergence.

## 7 Conclusion

A reagent-free, single-probe differential-pH aeration monitor can measure reef carbonate alkalinity to better than ±0.25 dKH without zero-point calibration, once three design rules are observed: a single sealed common headspace, plateau-following to true gas equilibrium, and an actively aerated reference anchor. The value of the eight-day campaign was less in any one number than in decomposing a −0.92 dKH raw error: null experiments showed that −0.86 dKH of it was alkalinity loss in a degraded sample aliquot and only −0.06 dKH was the instrument. The differential design delivered its promised common-mode rejection of room CO2 and probe drift; what remained was chemistry in a beaker, not error in the electronics. We expect the design rules and the null-decomposition methodology to transfer to other low-cost alkalinity instruments.

## Reproducibility

Firmware, the host measurement script (measure_kh_once.py), the raw log (dkh.dat), and the full measurement ledger are available in the project repository [1].

## Acknowledgments

This project was completed thanks to the passion of Mango-miyeok of REEF FAMILY and all the participants of the DIY meetup.

## References

[1] nowforyou (REEF FAMILY), “ReefWiz: open differential-pH aeration alkalinity monitor (firmware, host scripts, measurement ledger),” project repository, https://github.com/taeseokyi/reefwiz. (https://github.com/taeseokyi/reefwiz)
[2] K. S. Johnson, “Carbon dioxide hydration and dehydration kinetics in seawater,” Limnol. Oceanogr. 27(5), 849–855 (1982). doi:10.4319/lo.1982.27.5.0849.
[3] A. L. Soli and R. H. Byrne, “CO2 system hydration and dehydration kinetics and the equilibrium CO2/H2CO3 ratio in aqueous NaCl solution,” Mar. Chem. (2002).
[4] R. E. Zeebe and D. Wolf-Gladrow, CO2 in Seawater: Equilibrium, Kinetics, Isotopes, Elsevier Oceanography Series 65 (2001).
[5] T. Takahashi, “Methods for measurement of pCO2 and total CO2 in seawater” (carbonatesystem methodology; direct-bubbling equilibration ∼15 min).
[6] K. Fleger, X. Liu, W. Berelson, J. Adkins et al., “Total alkalinity measurements in small samples based on CO2 equilibration and spectrophotometric pH,” Anal. Chim. Acta (2025). doi:10.1016/j.aca.2025.344432.
[7] (Gas-stripping first-order equilibration; ln(C0/Ct) ∝ ϕ/V .) Roberts, Geophys. Res. Lett. (2005).
[8] C. S. Egleston, C. L. Sabine, F. M. M. Morel, “Revelle (buffer) factor of the seawater carbonate system,” Global Biogeochem. Cycles (2010).

[9] Reef-hobbyist community field reports on the commercial AquaWiz alkalinity monitor (room-CO2 error, sealed-container fix, bubble degradation, manufacturer guidance): Reef2Reef threads #1159272, #1073924, #1115439; UltimateReef #939234; Bay Area Reefers #40433.

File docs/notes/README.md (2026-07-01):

# 연구 노트 (측정 대장 참조용)

> 관련 문서: [측정 대장](../measurement-ledger.md) | [프로젝트 개요 (README)](../../README.md)

[측정 대장](../measurement-ledger.md) 본문에서 인용하는 세부 진단·검증 노트 모음이다. KH 측정 정확도를 다듬어 온 과정에서 나온 작업 메모를 시점 스냅샷으로 옮겨 놓았다 — 이후 실측으로 갱신되었을 수 있으니, 최신 결론은 항상 측정 대장 본문을 기준으로 본다.

- [feedback-no-catchup-measure](feedback-no-catchup-measure.md) — 밀린(놓친) KH 측정 보충은 불필요 — StartWhenAvailable 추가하지 말 것
- [feedback-one-change-at-a-time](feedback-one-change-at-a-time.md) — KH 측정 시스템 튜닝/실험은 한 번에 하나씩만 변경하고 효과 측정 후 다음으로
- [feedback-regression-test-simulator](feedback-regression-test-simulator.md) — measure_kh_once.py 등 측정/BT 로직 변경은 배포 전 항상 시뮬레이터(bin/test_measure_sim.py)로 회귀 검증
- [feedback-run-windows-py-from-wsl](feedback-run-windows-py-from-wsl.md) — WSL에서 Windows Python 스크립트(test_pump 등) 실행하는 정해진 방법 (-X utf8 필수)
- [feedback-validation-independent-replication](feedback-validation-independent-replication.md) — 보정(영점 등) 적용 전, 비독립 소표본을 독립 재현으로 검증 — 일정 vs 우연을 먼저 가른다
- [project-accuracy-target](project-accuracy-target.md) — KH 측정 목표 오차 = ±0.5 dKH 허용 / ±0.25 dKH 희망. 다일 널(n=13): 편향 −0.13 실재(σ0.061), 온도·KCl 원인 아님=액간전위. 목표는 여전히 충족
- [project-bt-rf-reconnect](project-bt-rf-reconnect.md) — HC-06 블루투스 SPP RF 순단 진단과 measure_kh_once.py 4계층 대응(연결확인·재연결·재시도·모터정지+keepalive)
- [project-dkh-temp-column-is-sealed-box](project-dkh-temp-column-is-sealed-box.md) — dkh.dat 온도 컬럼=밀폐 측정챔버 내부 수온(참조수·수조수 평형온도), 실제 메인 리프수조 수온의 대리값 아님
- [project-firmware-kh-calc](project-firmware-kh-calc.md) — 펌웨어 dKH 차동 계산식과 ref_pH/tank_pH 상승=전극 드리프트 진단
- [project-kh-offset-aeration-test](project-kh-offset-aeration-test.md) — KH 널테스트 ΔpH 오프셋 튜닝 — 부피·시간상수 비대칭(5L ref가 느려 방CO₂ 과도 추종 못 함) 진단과 대응
- [project-kh-v4-firmware-state](project-kh-v4-firmware-state.md) — KH 측정 상태 스냅샷 — V4 평형추종 측정 + 신펌웨어(트림평균) + dkh.dat 규약
- [project-measure-kh-script](project-measure-kh-script.md) — KH 측정 파이썬 스크립트 — once(V4 본 측정)/test 진단, dkh.dat 기록, Windows COM 포트
- [project-pump-timings](project-pump-timings.md) — 연동펌프 동작시간(초) — 헹굼·측정이송 모두 60/68, m1f80/m1b92(긴 호스)
- [project-symmetric-kh-redesign](project-symmetric-kh-redesign.md) — KH 측정 대칭화 재설계 확정안 — 저장수조 직접 폭기, tank 우선, KCl 스윕=tank 헹굼, 3M KCl 보관
- [project-windows-files](project-windows-files.md) — Windows 작업 폴더 파일 현황 및 작업 스케줄러 설정
- [reference-aeration-equilibrium](reference-aeration-equilibrium.md) — 폭기 화학 — 대기평형이 pH 상한, "과폭기" 불가, 폭기 부족(비대칭)만 dKH 오차 유발
- [reference-aeration-literature](reference-aeration-literature.md) — 해수 폭기/CO₂ 평형 시간의 학술 문헌값 — 화학완화 16초 vs 물리 가스교환 15분, 소부피화 근거
- [reference-aquawiz-overseas-cases](reference-aquawiz-overseas-cases.md) — 해외 상용 AquaWiz 커뮤니티 오차 분석(reef2reef 등) — 방CO₂·기포 오차구조가 우리 진단과 일치
- [reference-bluetooth-hc06](reference-bluetooth-hc06.md) — HC-06 블루투스 WSL 연결 방법 — rfcomm, MAC 주소

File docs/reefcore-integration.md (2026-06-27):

# reefCore 생태계 연동 — AquaWiz dKH 올리기

> 관련 문서: [프로젝트 개요 (README)](../README.md) | [자동화 구성](system-setup.md) | [측정 대장](measurement-ledger.md)

AquaWiz(reefWiz)가 측정한 **탄산경도(dKH)** 를 **reefCore 생태계**의 내 체커(reefChecker)에 측정값으로 올리는 연동입니다. 2026-06-23 메커니즘 검증·실측 성공.

> ⚠️ **자격증명·시크릿은 이 문서에 값으로 적지 않습니다.** 모두 환경변수명으로만 표기하며, 공개 저장소에 실제 값을 커밋하지 않습니다.

## 1. 생태계 구성

| 구성요소 | 역할 |
|---|---|
| **reefCore** | 허브/클라우드 (앱·계정·DB). 사이트 `reef.anih.net` (React SPA) |
| **reefChecker** | Hanna Checker HC 비색계 기반 ESPHome 기기 (dKH/Ca/Mg/NO3/PO4/pH 측정) |
| **reefWiz** | 본 프로젝트(AquaWiz). dKH를 위 생태계로 공급 |

## 2. 아키텍처

- **REST API**: `https://reefapi.anih.net`. 인증 `POST /auth/login {email, password}` → JWT(`Authorization: Bearer …`).
- **측정값 주입 경로**: 현재 채택 경로는 **기기가 MQTT로 발행 → 백엔드가 수집**. (정정 2026-06-25: 과거 "REST 생성 엔드포인트 없음"이라 적었으나, 실제로는 `POST /devices/{mac}/measurements {mode,value,unit,temp,measured_at,memo}`(ManualMeasurementRequest)가 **존재**한다. 이 경로는 retain 자체가 없어 유령 중복 위험이 없고 `measured_at` 을 명시할 수 있는 **더 깔끔한 대안**이나, REST 인증(JWT)이 필요하다. 현 conf 자격은 **MQTT 전용**(`/mqtt/auth` 로 검증)이라 `/auth/login` 에는 401 — 웹 계정 비번이 있어야 전환 가능. 미채택, 향후 옵션.)
- **MQTT 브로커**: `reef.anih.net:8883` (MQTT over TLS). 여러 기기가 쓰는 **공유 브로커**.
- **MQTT 인증**: reefCore **계정 자격** 사용 — username = 계정 이메일(`$REEFCORE_USER`), password = 계정 비번(`$REEFCORE_PASS`).
- **기기 등록**(참고): `POST reefapi.anih.net/devices/register {mac, email, device_type}`. `device_type` ∈ `reefcore`/`checker`/`ato`/`module`. 펌웨어에 박힌 등록 키(`$REEFCORE_REG_KEY`)로 인가하는 것으로 추정.

## 3. dKH 올리는 메커니즘 (검증됨)

체커는 ESPHome 표준 토픽으로 상태를 발행합니다:

```
reefcore-checker-<mac6>/sensor|select|switch|number/<엔티티>/state
```

이 중 **"최근 측정값" 센서 토픽**에 아래 형식의 요약 문자열을 발행하면, 백엔드가 이를 파싱해 `{mode, value, unit, temp, measured_at}` 측정 레코드를 생성합니다:

```
토픽   : reefcore-checker-<mac6>/sensor/________________/state
                                  └ 한글 엔티티명이 sanitize되어 언더스코어로 보임
페이로드: "<mode>: <value> <unit> | <temp>°C @ <YYYY-MM-DD HH:MM>"
예시    : "dKH: 8.43 dKH | 27.2°C @ 2026-06-23 13:39"
```

- 발행 시 **고유 client_id**(`reefwiz-*`)를 쓰면 체커의 MQTT 세션을 끊지 않습니다.
- 대상 체커 MAC은 `$REEFCORE_MAC`(기본값=내 체커)로 지정. 토픽의 `<mac6>`는 MAC 끝 6자리.

## 4. 구현 — `measure_kh_once.py` 에 통합 (채택)

측정 종료 시점이 가변(평탄까지, 최대 4h)이라 고정 시각 스케줄로는 완료를 놓친다. 그래서
**측정 스크립트가 `dkh.dat` 에 기록한 직후** `publish_to_reefcore()` 로 한 번 발행한다(측정당 정확히 1회).

- **best-effort**: 자격 미설정·paho 미설치·연결 실패 등 어떤 오류도 측정을 중단시키지 않는다.
- **값 `None`(값 없음)만 발행 제외, 나머지는 전부 발행** — `0`=측정 에러, 음수=평탄 미도달(V4 규약)도 **그대로 발행해 부호·0 자체가 상태를 전달**한다(reefCore 가 dkh.dat 와 동일 규약을 반영). 게이트는 `_publishable(tank_kh)`(=`tank_kh is not None`). calkh 에러 경로(`else`)도 `0.0` 을 발행한다. ※ reefCore 백엔드가 음수/0 dKH 를 파싱·저장할 수 있어야 의미가 있다(부호=상태).
- 발행은 **`retain=False`**·`qos=1`, 고유 client_id(`reefwiz-bridge`)라 체커 세션을 끊지 않는다.
  - ⚠️ **`retain=False` 가 중요하다.** 이 토픽은 단순 상태가 아니라 "수신 시 측정 레코드를 생성"하는 이벤트 토픽이라, `retain=True` 면 브로커가 보관한 옛 측정값을 **백엔드 재접속 때마다 재전달 → 유령 중복 레코드**를 만들 수 있다. 백엔드는 상시 접속(`/debug/state` 의 `mqtt_connected:true`)이라 `retain=False` 여도 발행이 정상 도달한다(2026-06-25 실측: retain=False 발행 후 `/debug/state` 의 '최근 측정값' 토픽이 즉시 갱신됨). 과거 `retain=True` 로 남았던 retained 메시지는 빈 retained 발행으로 클리어 완료.

자격증명 로딩 우선순위(`_reefcore_creds()`): **환경변수 → 설정 파일**. 스케줄 작업이 사용자
환경변수를 못 보는 경우가 있어 설정 파일 폴백을 둔다.

```ini
# C:\dkh\reefcore.conf  (저장소 밖, .gitignore — 평문 자격이므로 외부 노출/커밋 금지)
user=<reefCore 계정 이메일>
pass=<reefCore 계정 비번>
mac=<체커 MAC>
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

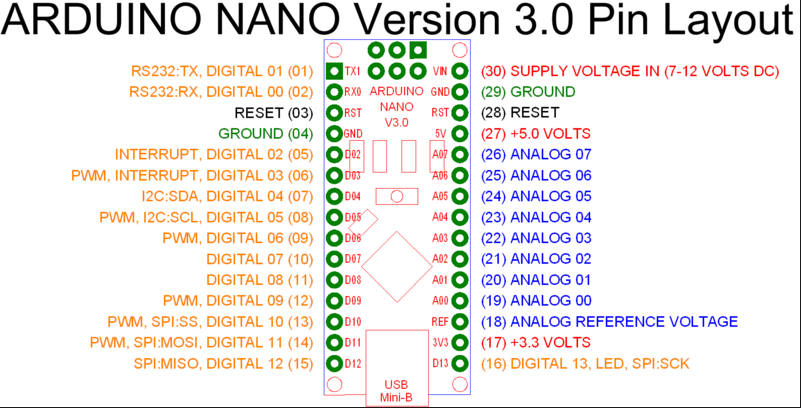
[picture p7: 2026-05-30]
docs/images/arduino-nano-pinout.png

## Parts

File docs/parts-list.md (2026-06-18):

# AquaWiz 준비물 목록

> 관련 문서: [프로젝트 개요 (README)](../README.md) | [자동화 환경 구성](system-setup.md) | [사용 설명서](user-manual.md) | [측정 대장](measurement-ledger.md)

## 디바이스마트

| # | 사진 | 부품명 | 수량 | 금액 |
|---|---|---|---|---|
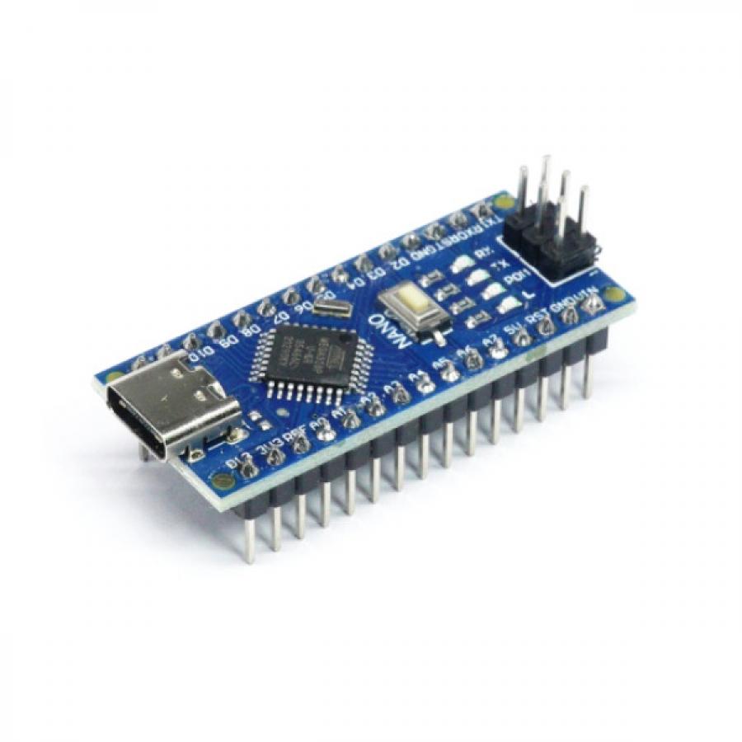
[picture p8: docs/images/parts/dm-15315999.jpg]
| 1 |  | <a href="https://www.devicemart.co.kr/goods/view?no=15315999" target="_blank">아두이노 나노 호환보드 V3.0 CH340 C타입</a> | 1 | 5,500원 |
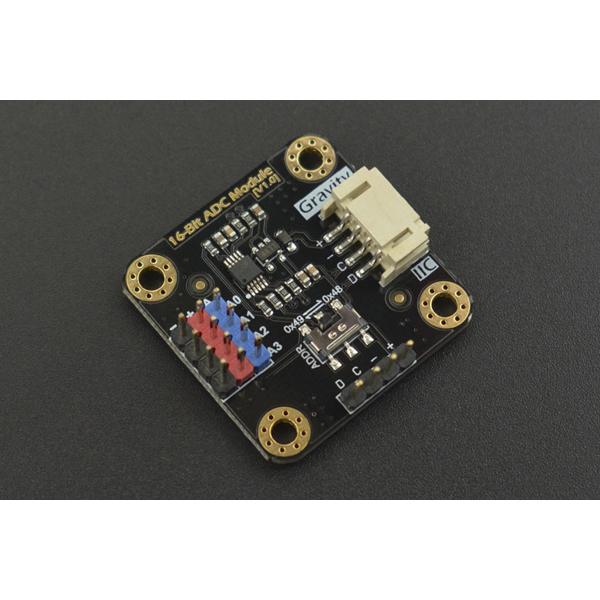
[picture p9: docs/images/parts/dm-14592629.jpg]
| 2 |  | <a href="https://www.devicemart.co.kr/goods/view?no=14592629" target="_blank">Gravity: I2C ADS1115 16-Bit ADC Module</a> | 1 | 23,000원 |
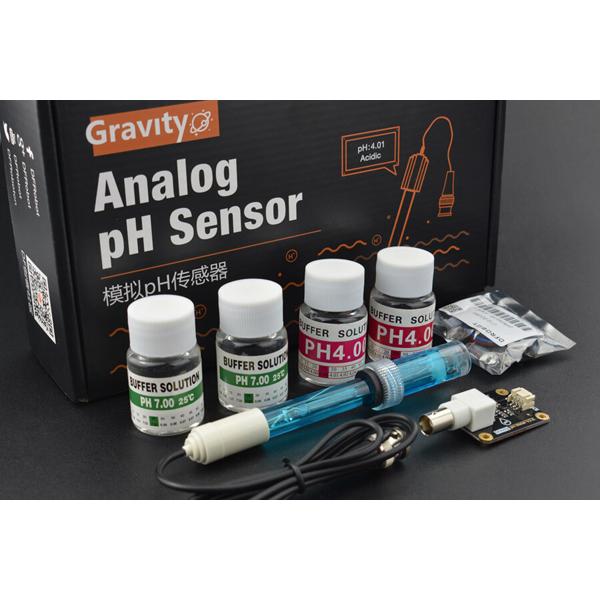
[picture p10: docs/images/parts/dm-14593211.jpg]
| 3 |  | <a href="https://www.devicemart.co.kr/goods/view?no=14593211" target="_blank">Gravity: Analog pH Sensor/Meter Kit V2</a> | 1 | 57,500원 |
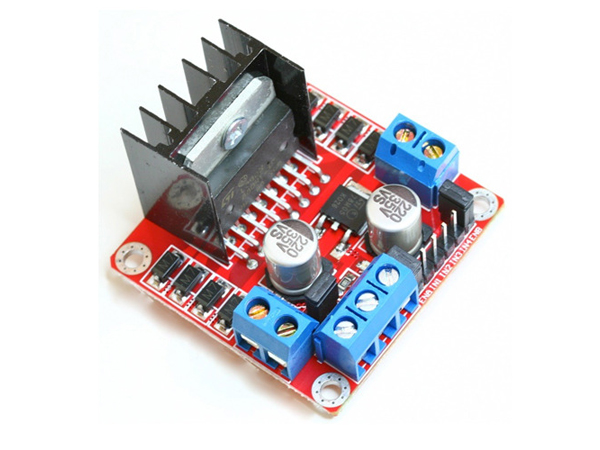
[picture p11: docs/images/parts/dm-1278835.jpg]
| 4 |  | <a href="https://www.devicemart.co.kr/goods/view?no=1278835" target="_blank">2A L298 모터드라이버 모듈 (아두이노 호환)</a> | 3 | 8,100원 |
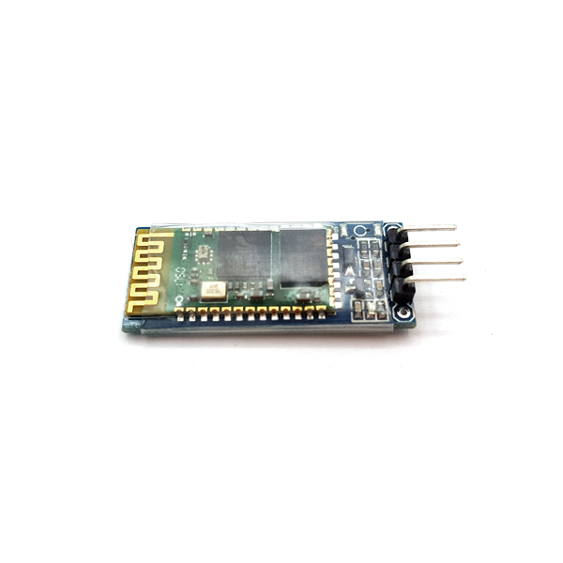
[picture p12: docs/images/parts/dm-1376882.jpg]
| 5 |  | <a href="https://www.devicemart.co.kr/goods/view?no=1376882" target="_blank">블루투스 모듈 HC-06 (DIP) 펌웨어 v1.8</a> | 1 | 5,500원 |
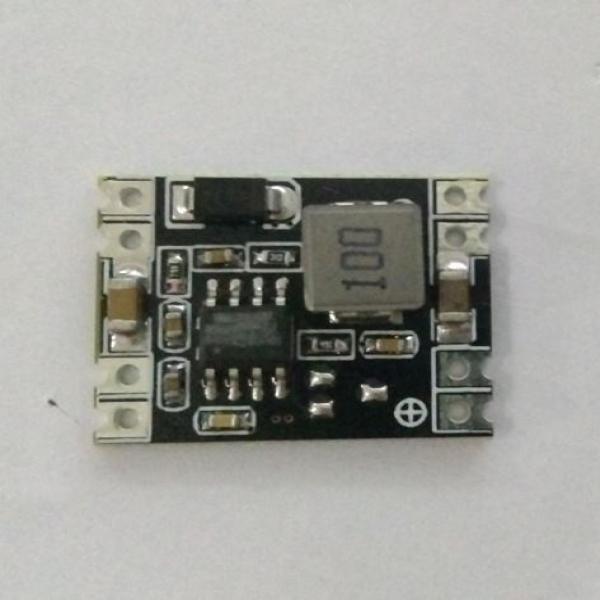
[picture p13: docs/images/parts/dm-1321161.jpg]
| 6 |  | <a href="https://www.devicemart.co.kr/goods/view?no=1321161" target="_blank">5V 고정 출력 강하형 DC-DC 3A 컨버터</a> | 1 | 3,500원 |
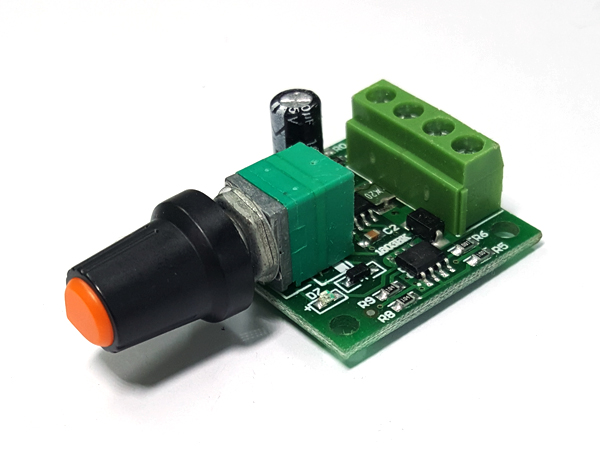
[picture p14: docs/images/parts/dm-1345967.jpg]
| 7 |  | <a href="https://www.devicemart.co.kr/goods/view?no=1345967" target="_blank">PWM 12V 2A DC모터 속도 제어 컨트롤러</a> | 4 | 8,000원 |
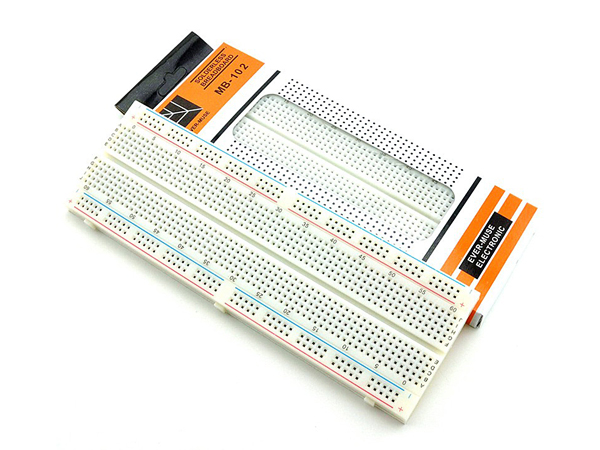
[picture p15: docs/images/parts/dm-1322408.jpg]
| 9 |  | <a href="https://www.devicemart.co.kr/goods/view?no=1322408" target="_blank">브레드보드 830핀 MB-102</a> | 1 | 1,400원 |
| | | **디바이스마트 소계** | | **124,320원** |

## AliExpress

| # | 사진 | 부품명 | 수량 | 금액 |
|---|---|---|---|---|
| 10 |  | <a href="https://www.aliexpress.com/item/1005001888639071.html" target="_blank">연동 펌프 NKP-DC-B06B (12V, yellow)</a> | 4 | ₩21,680 |
| | | **AliExpress 소계** | | **₩21,680** |

## 별도 구매 필요 부품

### 전자부품

| # | 부품명 | 사양 | 수량 | 용도 |
|---|---|---|---|---|
| 11 | DS18B20 방수 온도센서 | PTFE 케이블, 1-Wire | 1 | Nernst 온도 보상 (위즈 탱크 침수) |
| 12 | <a href="https://smartstore.naver.com/vim/products/4583133452" target="_blank">USB 5V 에어 펌프</a> | DC 5V, USB 전원 | 2 | 참조수/수조수 폭기 (L298N3 제어) |
| 13 | 세라믹 콘덴서 100nF (104) | 50V 이상 | 4 | C1: Arduino, C2: ADS1115 VDD, C3: 아날로그 입력 RC필터, C4: DS18B20 |
| 14 | 저항 330Ω (주황-주황-갈색-금) | 1/4W | 1 | ADS1115 아날로그 입력 RC 필터 직렬 저항 (R6) |
| 15 | 저항 4.7kΩ (노랑-보라-빨강-금) | 1/4W | 1 | DS18B20 풀업 저항 (R2) |
| 16 | 저항 10kΩ (갈색-검정-주황-금) | 1/4W | 1 | HC-06 TX 전압분배기 (R4) |
| 17 | 저항 20kΩ (빨강-검정-주황-금) | 1/4W | 1 | HC-06 TX 전압분배기 (R5) |
| 18 | 12V DC 어댑터 | 12V 3A 이상 | 1 | 전체 시스템 전원 |
| 19 | DC 잭 (배럴커넥터) | 5.5x2.1mm | 1 | 어댑터 연결용 |
| 20 | 점퍼 와이어 | M-M, M-F 혼합 | 1세트 | 브레드보드 배선 |

### 비전자 부품 (실험 환경)

| # | 부품명 | 사양 | 수량 | 용도 |
|---|---|---|---|---|
| 21 | 실리콘 에어 스톤 | 수족관용 | 2 | 에어 펌프 출력단 기포 분산 |
| 22 | 실리콘 호스 | 내경 2~4mm | 적량 | 펌프/에어 연결 |
| 23 | 비이커 | 200ml | 3 | 수조물 / pH 측정 / 3M KCl |
| 24 | 위즈 탱크 용기 | 다이소 락앤락 김치통 (5L) | 1 | 참조 해수 + 비이커 수납 (아래 참고) |
| 25 | 3M KCl 용액 | - | 적량 | pH 프로브 저장수 (건조 방지) |
| 26 | pH 보정 버퍼 용액 | pH 4.0 / pH 7.0 | 각 1 | pH 2점 보정 |

## 총 합계

| 구매처 | 금액 |
|---|---|
| 디바이스마트 | 124,320원 |
| AliExpress | 21,680원 |
| 별도 구매 | 미정 |
| **주문 합계** | **146,000원** |

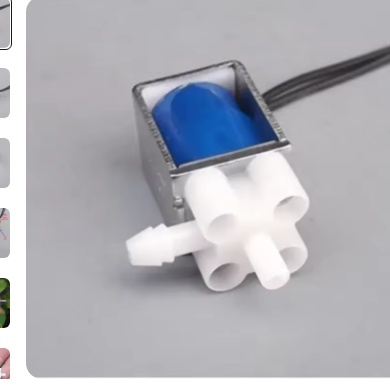
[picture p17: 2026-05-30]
docs/images/parts/ali-solenoid.jpg

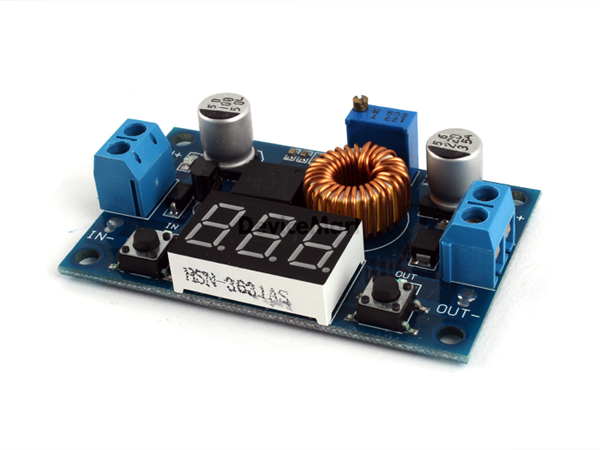
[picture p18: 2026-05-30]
docs/images/parts/dm-1321262.jpg

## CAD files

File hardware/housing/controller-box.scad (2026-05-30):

// AquaWiz 제어기 하우징
// 내부 부품: 브레드보드 x2, L298N x3, Buck 5V, Buck 6V(XL4015), PWM x4
// Arduino Nano, ADS1115, HC-06은 브레드보드 위에 장착

// ==================== 파라미터 ====================

// 벽 두께
wall = 2.5;
lid_h = 3;

// 브레드보드 MB-102 (165 x 55 x 10mm) x 2개 나란히
bb_w = 165;
bb_d = 55;
bb_h = 10;
bb_gap = 5;  // 브레드보드 사이 간격

// L298N 모터드라이버 (43 x 43 x 27mm) x 3개
l298_w = 43;
l298_d = 43;
l298_h = 27;
l298_gap = 5;

// Buck 5V 컨버터 (45 x 20 x 14mm)
buck5v_w = 45;
buck5v_d = 20;
buck5v_h = 14;

// XL4015 가변 컨버터 (54 x 23 x 15mm)
xl4015_w = 54;
xl4015_d = 23;
xl4015_h = 15;

// PWM 속도 컨트롤러 (30 x 24 x 15mm) x 4개
pwm_w = 30;
pwm_d = 24;
pwm_h = 15;

// 내부 배치: 상단=브레드보드 영역, 하단=드라이버 영역
// 여유 공간
margin = 5;

// 내부 치수 계산
inner_w = bb_w + 2*margin;  // 175
inner_d = bb_d*2 + bb_gap + l298_d + l298_gap + 2*margin;  // 168
inner_h = max(l298_h, bb_h + 20) + margin;  // 42

// 외부 치수
outer_w = inner_w + 2*wall;
outer_d = inner_d + 2*wall;
outer_h = inner_h + wall;

// 나사 기둥
screw_d = 3;
post_d = 7;
post_h = 5;

// 통풍구
vent_w = 2;
vent_gap = 4;

// ==================== 모듈 ====================

module rounded_box(w, d, h, r=3) {
    hull() {
        for (x = [r, w-r], y = [r, d-r])
            translate([x, y, 0]) cylinder(h=h, r=r, $fn=20);
    }
}

module vent_slots(w, h, n=6) {
    for (i = [0:n-1])
        translate([i*(vent_w + vent_gap), 0, 5])
            cube([vent_w, wall+1, h-10]);
}

module screw_post(h) {
    difference() {
        cylinder(d=post_d, h=h, $fn=20);
        translate([0, 0, -0.1])
            cylinder(d=screw_d, h=h+0.2, $fn=20);
    }
}

module cable_hole(d=8) {
    rotate([90, 0, 0])
        cylinder(d=d, h=wall+2, $fn=20);
}

// ==================== 본체 (하단) ====================

module controller_base() {
    difference() {
        // 외벽
        rounded_box(outer_w, outer_d, outer_h);

        // 내부 공간
        translate([wall, wall, wall])
            rounded_box(inner_w, inner_d, inner_h + 1, r=2);

        // 전면 통풍구 (L298N 방열)
        translate([wall + 10, -0.5, 0])
            vent_slots(inner_w - 20, outer_h, n=15);

        // 후면 통풍구
        translate([wall + 10, outer_d - wall - 0.5, 0])
            vent_slots(inner_w - 20, outer_h, n=15);

        // 좌측 케이블 홀 (모터/솔레노이드 연결) x3
        for (i = [0:2])
            translate([-0.5, wall + margin + 20 + i*30, outer_h/2])
                rotate([0, 90, 0])
                    cylinder(d=10, h=wall+1, $fn=20);

        // 우측 DC잭 홀
        translate([outer_w - wall - 0.5, wall + margin + 15, outer_h/2])
            rotate([0, 90, 0])
                cylinder(d=12, h=wall+1, $fn=20);

        // 우측 케이블 홀 (펌프 연결)
        for (i = [0:1])
            translate([outer_w - wall - 0.5, wall + margin + 45 + i*30, outer_h/2])
                rotate([0, 90, 0])
                    cylinder(d=10, h=wall+1, $fn=20);
    }

    // 나사 기둥 (4 코너)
    corner_inset = wall + 5;
    for (pos = [[corner_inset, corner_inset],
                [outer_w - corner_inset, corner_inset],
                [corner_inset, outer_d - corner_inset],
                [outer_w - corner_inset, outer_d - corner_inset]])
        translate([pos[0], pos[1], wall])
            screw_post(inner_h - lid_h);

    // 브레드보드 지지대 (레일)
    bb_x = wall + margin;
    bb_y = wall + margin;
    for (i = [0:1]) {
        translate([bb_x, bb_y + i*(bb_d + bb_gap), wall])
            cube([bb_w, 2, post_h]);
        translate([bb_x, bb_y + i*(bb_d + bb_gap) + bb_d - 2, wall])
            cube([bb_w, 2, post_h]);
    }
}

// ==================== 뚜껑 ====================

module controller_lid() {
    difference() {
        rounded_box(outer_w, outer_d, lid_h);

        // 나사 홀
        corner_inset = wall + 5;
        for (pos = [[corner_inset, corner_inset],
                    [outer_w - corner_inset, corner_inset],
                    [corner_inset, outer_d - corner_inset],
                    [outer_w - corner_inset, outer_d - corner_inset]])
            translate([pos[0], pos[1], -0.1])
                cylinder(d=screw_d, h=lid_h+0.2, $fn=20);

        // 상단 통풍 슬롯
        for (i = [0:12])
            translate([wall + 10 + i*(vent_w + vent_gap*2), wall + 10, -0.1])
                cube([vent_w, outer_d - wall*2 - 20, lid_h + 0.2]);
    }

    // 끼움 테두리
    translate([wall + 0.3, wall + 0.3, lid_h])
        difference() {
            rounded_box(inner_w - 0.6, inner_d - 0.6, 2, r=1.5);
            translate([1.5, 1.5, -0.1])
                rounded_box(inner_w - 3.6, inner_d - 3.6, 2.2, r=1);
        }
}

// ==================== 렌더링 ====================

// 본체
controller_base();

// 뚜껑 (옆에 배치)
translate([outer_w + 20, 0, 0])
    controller_lid();

// 치수 표시 (디버그용)
echo(str("제어기 외부 치수: ", outer_w, " x ", outer_d, " x ", outer_h + lid_h, " mm"));
echo(str("내부 치수: ", inner_w, " x ", inner_d, " x ", inner_h, " mm"));

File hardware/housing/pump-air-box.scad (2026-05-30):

// AquaWiz 펌프 + 에어 분배기 하우징
// 내부 부품: 연동 펌프 NKP-DC-B06B x4, 3-way 솔레노이드 밸브 x2

// ==================== 파라미터 ====================

wall = 2.5;
lid_h = 3;

// NKP-DC-B06B 연동 펌프 (약 55 x 38 x 65mm, 모터 포함)
pump_w = 55;   // 폭 (좌우)
pump_d = 38;   // 깊이 (앞뒤)
pump_h = 65;   // 높이 (모터 축 방향)
pump_gap = 8;  // 펌프 사이 간격
pump_n = 4;

// 펌프 마운트 홀 (M3 나사)
pump_mount_d = 3.2;
pump_mount_dist = 30;  // 마운트 홀 간격 (추정)

// 3-way 솔레노이드 밸브 (약 15 x 10 x 20mm)
sol_w = 15;
sol_d = 10;
sol_h = 20;
sol_gap = 8;
sol_n = 2;

margin = 5;

// 레이아웃: 펌프 4개 일렬 + 솔레노이드 2개 옆에
pump_area_w = pump_n * pump_w + (pump_n - 1) * pump_gap;  // 244
sol_area_w = sol_n * sol_w + (sol_n - 1) * sol_gap;  // 74

inner_w = pump_area_w + sol_area_w + margin * 3;  // 333
inner_d = max(pump_d, sol_d) + 2*margin;  // 48
inner_h = max(pump_h, sol_h) + margin;  // 70

outer_w = inner_w + 2*wall;
outer_d = inner_d + 2*wall;
outer_h = inner_h + wall;

// 호스 홀 직경
hose_d = 6;  // 실리콘 호스 외경
air_hose_d = 5;  // 에어 호스

screw_d = 3;
post_d = 7;

// ==================== 모듈 ====================

module rounded_box(w, d, h, r=3) {
    hull() {
        for (x = [r, w-r], y = [r, d-r])
            translate([x, y, 0]) cylinder(h=h, r=r, $fn=20);
    }
}

module screw_post(h) {
    difference() {
        cylinder(d=post_d, h=h, $fn=20);
        translate([0, 0, -0.1])
            cylinder(d=screw_d, h=h+0.2, $fn=20);
    }
}

module pump_mount() {
    // 펌프 안착 가이드 (U자형)
    guide_h = 15;
    guide_w = pump_w + 1;  // 여유
    guide_d = pump_d + 1;

    difference() {
        // 외벽
        translate([-1, -1, 0])
            cube([guide_w + 2, guide_d + 2, guide_h]);
        // 내부
        translate([0, 0, wall])
            cube([guide_w, guide_d, guide_h]);
    }
}

module hose_hole() {
    rotate([90, 0, 0])
        cylinder(d=hose_d, h=wall+2, $fn=20);
}

// ==================== 본체 ====================

module pump_air_base() {
    difference() {
        rounded_box(outer_w, outer_d, outer_h);

        // 내부 공간
        translate([wall, wall, wall])
            rounded_box(inner_w, inner_d, inner_h + 1, r=2);

        // 상단 호스 홀 - 펌프 입출구 (각 펌프당 2개 = 8개)
        for (i = [0:pump_n-1]) {
            px = wall + margin + i*(pump_w + pump_gap) + pump_w/2;
            // 입구 호스
            translate([px - 10, outer_d - wall - 0.5, outer_h - 15])
                hose_hole();
            // 출구 호스
            translate([px + 10, outer_d - wall - 0.5, outer_h - 15])
                hose_hole();
        }

        // 솔레노이드 에어 홀 (입력 1 + 출력 2 x 2개)
        sol_start = wall + margin*2 + pump_area_w;
        for (i = [0:sol_n-1]) {
            sx = sol_start + i*(sol_w + sol_gap) + sol_w/2;
            // 에어 입력
            translate([sx, outer_d - wall - 0.5, outer_h - 12])
                rotate([90, 0, 0])
                    cylinder(d=air_hose_d, h=wall+2, $fn=20);
            // 에어 출력
            translate([sx, -0.5, outer_h - 12])
                rotate([-90, 0, 0])
                    cylinder(d=air_hose_d, h=wall+2, $fn=20);
        }

        // 전선 홀 (우측, 전원 + 신호)
        translate([outer_w - wall - 0.5, outer_d/2, outer_h/2])
            rotate([0, 90, 0])
                cylinder(d=12, h=wall+1, $fn=20);

        // 전선 홀 (좌측)
        translate([-0.5, outer_d/2, outer_h/2])
            rotate([0, 90, 0])
                cylinder(d=12, h=wall+1, $fn=20);
    }

    // 나사 기둥
    ci = wall + 5;
    for (pos = [[ci, ci], [outer_w-ci, ci],
                [ci, outer_d-ci], [outer_w-ci, outer_d-ci]])
        translate([pos[0], pos[1], wall])
            screw_post(inner_h - lid_h);

    // 펌프 안착 가이드
    for (i = [0:pump_n-1]) {
        px = wall + margin + i*(pump_w + pump_gap);
        py = wall + margin;
        translate([px, py, wall])
            pump_mount();
    }

    // 솔레노이드 구분벽
    translate([wall + margin*2 + pump_area_w - wall, wall, wall])
        cube([wall, inner_d, inner_h * 0.6]);
}

// ==================== 뚜껑 ====================

module pump_air_lid() {
    difference() {
        rounded_box(outer_w, outer_d, lid_h);

        // 나사 홀
        ci = wall + 5;
        for (pos = [[ci, ci], [outer_w-ci, ci],
                    [ci, outer_d-ci], [outer_w-ci, outer_d-ci]])
            translate([pos[0], pos[1], -0.1])
                cylinder(d=screw_d, h=lid_h+0.2, $fn=20);

        // 펌프 헤드 접근용 개구부 (호스 연결)
        for (i = [0:pump_n-1]) {
            px = wall + margin + i*(pump_w + pump_gap) + pump_w/2;
            translate([px - pump_w/2 + 5, wall + 5, -0.1])
                cube([pump_w - 10, inner_d - 10, lid_h + 0.2]);
        }
    }

    // 끼움 테두리
    translate([wall + 0.3, wall + 0.3, lid_h])
        difference() {
            rounded_box(inner_w - 0.6, inner_d - 0.6, 2, r=1.5);
            translate([1.5, 1.5, -0.1])
                rounded_box(inner_w - 3.6, inner_d - 3.6, 2.2, r=1);
        }
}

// ==================== 렌더링 ====================

pump_air_base();

translate([0, outer_d + 20, 0])
    pump_air_lid();

echo(str("펌프+분배기 외부 치수: ", outer_w, " x ", outer_d, " x ", outer_h + lid_h, " mm"));
echo(str("내부 치수: ", inner_w, " x ", inner_d, " x ", inner_h, " mm"));

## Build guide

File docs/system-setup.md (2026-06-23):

# AquaWiz 자동화 환경 구성

> 관련 문서: [프로젝트 개요 (README)](../README.md) | [사용 설명서](user-manual.md) | [준비물 목록](parts-list.md) | [측정 대장](measurement-ledger.md)

## 실물 사진

| 제어기 |
|:---:|
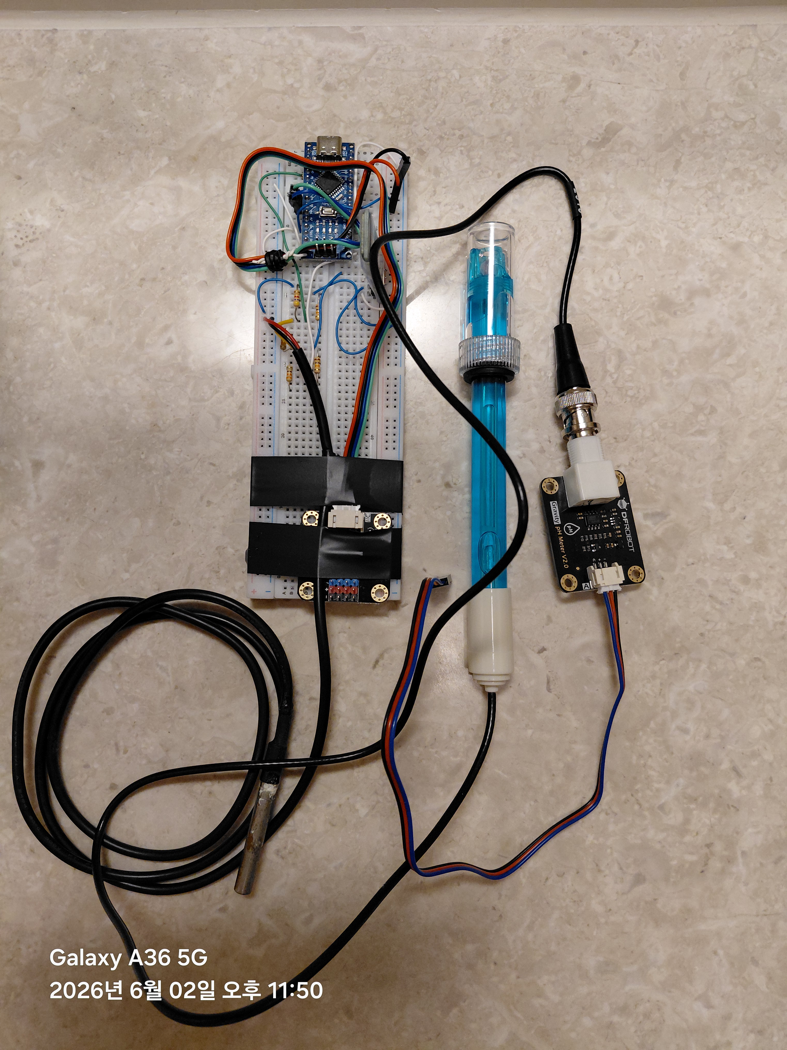
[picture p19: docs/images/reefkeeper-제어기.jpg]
|  |

### 최종 형태 — 밀폐 폐루프 (공통 헤드스페이스)

> 참조수 통(5L)·측정 챔버·펌프 흡입을 **하나의 밀폐 공기**로 묶은 최종 구성입니다. 측정 순간 ref·tank가 같은 pCO₂를 공유해 방 CO₂ 변동을 차동으로 상쇄하고, 증발도 차단합니다. **밀폐는 선택이 아니라 필수** — 근거·검증은 아래 [위즈 탱크](#위즈-탱크)와 [측정 대장](measurement-ledger.md)(2026-06-19) 참조.

## 시스템 구성도

시스템 구성도

## 호스 연결

호스 연결도

## 준비물

구매 링크 포함 상세 목록은 [준비물 목록](parts-list.md)을 참조하세요.

## 하우징 (3D 프린팅)

| 제어기 하우징 | 펌프 + 에어 분배기 하우징 |
|:---:|:---:|
| 제어기 | 펌프+분배기 |
| 180 x 173 x 45mm | 296 x 53 x 75mm |
| <a href="../hardware/housing/controller-box.scad" target="_blank">OpenSCAD 도면</a> | <a href="../hardware/housing/pump-air-box.scad" target="_blank">OpenSCAD 도면</a> |

OpenSCAD 파라메트릭 설계 — 부품 실측 후 상단 파라미터만 수정하면 치수 자동 조정됩니다.

## 구성 요소

### 제어기 본체

| 구성 | 사양 |
|---|---|
| MCU | Arduino Nano V3.0 (ATmega328P) |
| pH 센서 | DFRobot SEN0161-V2 + ADS1115 16bit ADC |
| 온도 센서 | DS18B20 (위즈 탱크 내 침수) |
| 통신 | HC-06 블루투스 (9600 baud) |
| 모터 드라이버 | L298N1/L298N2 (도징 펌프, 12V) + L298N3 (에어 펌프, USB 5V) |
| 속도 제어 | PWM 컨트롤러 Motor− 출력 → L298N ENA/ENB (역 PWM) |
| 전원 | 12V DC → Buck 5V (MCU) + USB 5V (L298N3 에어 펌프) |

### 연동 펌프 (4구, 모두 양방향)

| 펌프 | 경로 | 정방향 (f) | 역방향 (b) |
|---|---|---|---|
| 펌프1 (M1) | 수조 ↔ 수조물 비이커 | 수조 → 수조물 비이커 (샘플링) | 수조물 비이커 → 수조 (반환) |
| 펌프2 (M2) | 수조물 비이커 ↔ pH 측정 비이커 | 수조물 → pH 비이커 (측정 이송) | pH 비이커 → 수조물 (측정 후 반환) |
| 펌프3 (M3) | 3M KCl 비이커 ↔ pH 측정 비이커 | KCL → pH 비이커 (프로브 보관) | pH 비이커 → KCL 비이커 (저장수 배출) |
| 펌프4 (M4) | 위즈 탱크 ↔ pH 측정 비이커 | 참조수 → pH 비이커 (측정 이송) | pH 비이커 → 위즈 탱크 (참조수 반환) |

### 에어 공급 및 PWM 속도 제어 (L298N3)

| 핀 | 명령 (ON / OFF) | 용도 |
|-----|---|---|
| D12 (L298N3 채널A) | `ron` / `roff` | USB 5V 에어 펌프 ON/OFF (참조수 + 수조수 폭기) |
| D13 (L298N3 채널B) | `ton` / `toff` | PWM 속도 제어기 ON/OFF (모터 구동 시 활성화) |
| D12 + D13 | `airoff` | 둘 다 LOW (에어 OFF + PWM 제어기 OFF) |

- `ron`/`roff`: D12 → 에어 펌프 ON/OFF (참조수·수조수 동시 탈기)
- `ton`/`toff`: D13 → PWM 속도 제어기 ON/OFF (도징 펌프 구동 전 `ton`)
- `airoff`: D12·D13 동시 LOW (둘 다 OFF). 전체를 한 번에 끄려면 `stop`(모터 전체 + 에어/PWM 핀)
- **하드웨어 규칙:** 액체 이동(`mXf`/`mXb`) 직전에는 반드시 `airoff`로 폭기를 끈다.

> **참고:** 구 펌웨어의 `air:총초:주기초`(교대 공급) 명령은 **제거**되었고, 독립 OFF용 `roff`/`toff`와 전체 정지 `stop`이 추가되었습니다.

### 위즈 탱크

| 항목 | 사양 |
|---|---|
| 용기 | 다이소 락앤락 김치통 (5L) |
| 내용물 | 참조 해수 (알려진 dKH 값) |
| 센서 | DS18B20 온도 센서 침수 |
| 비이커 | 200ml x 3개 (수조물, pH 측정, 3M KCl) |

모든 비이커는 위즈 탱크 안에 담겨 있어 참조수와 동일한 온도 환경을 유지합니다.

> ## ★밀폐 공통 헤드스페이스 — 선택이 아니라 필수
>
> **참조수 통·측정 챔버·펌프 흡입을 *하나의 공통* 밀폐 공기로 묶습니다(폐루프 흡입).** 차동식 `KH_tank = KH_ref × 10^(−ΔpH)`이 순수 KH차를 주려면 측정 순간 ref·tank가 **같은 pCO₂**여야 하는데, 밀폐 공통 헤드스페이스는 두 물이 *같은 한 덩어리 공기*를 공유하게 해 이 조건을 **본질적으로 보장**합니다.
>
> 1. **방 CO₂ 변동 차단(핵심):** 외부 공기를 끊으므로 방 CO₂가 ΔpH로 새어들 통로가 없어집니다. 차동 상쇄가 가장 잘 일어나는 조건.
> 2. **증발 차단:** 측정수의 증발 농축(경도 상승)을 막아 ΔKH=0 전제를 지키고 참조수 dKH도 장기간 일정하게 유지합니다.
> 3. **온도 균일:** 밀폐 공간 내 참조수·수조수·KCL이 동일 온도로 유지되어 Nernst 보정 정확도가 향상됩니다.
>
> **★필수 조건 — 분리 밀폐 금지.** ref와 tank가 **서로 다른** 밀폐 공간에 있으면 두 헤드스페이스가 따로 드리프트해 상쇄가 깨집니다. 반드시 **하나의 공통 헤드스페이스**를 공유해야 합니다. 펌프 흡입도 외기가 아니라 이 공통 공기에서 폐루프로 끌어옵니다.
>
> **검증(2026-06-19):** 밀폐 적용 후 첫 새벽(고-CO₂) 측정에서 그간 3회 재현되던 새벽 오차(ΔpH −0.043~−0.059)가 **−0.008**로 붕괴했습니다(낮 baseline 수준). 또 헤드스페이스가 참조수 알칼리니티 버퍼로 핀고정돼 평형이 사실상 즉시 도달(과거 새벽 33회 → 4회, 측정 ~50분 → ~5분) → tank↔ref 측정 시간차가 붕괴해 드리프트성 오차까지 구조적으로 사라졌습니다. 무보정 원시오차도 −0.78 → −0.165 dKH로 줄어 목표 정확도 안에 들어왔습니다. 상세는 [측정 대장](measurement-ledger.md).
>
> **주의:** 펌프 발열이 헤드스페이스/수온을 밀어올릴 수 있으므로 온도욕조 안정과 응결을 점검하세요(6/19 측정은 28.1℃로 폭주 없음).

## 노이즈 대책

노이즈 제거 콘덴서 배치도

## 자동 측정 시퀀스 (PC 측 V4)

### 설계 배경 — 폭기 중 평형 추종

차동식 `KH_tank = KH_ref × 10^(−ΔpH)`이 순수 KH차를 반영하려면 측정 순간
ref·tank가 **같은 pCO₂**여야 합니다. 이를 두 축으로 달성합니다.

1. **밀폐 공통 헤드스페이스(필수, 가스 기준 고정):** ref·tank가 하나의 밀폐 공기를
   공유하므로 *같은 pCO₂*가 본질적으로 보장되고 방 CO₂ 변동 통로가 차단됩니다 →
   [위즈 탱크 — 밀폐 공통 헤드스페이스](#위즈-탱크) 참조.
2. **폭기 중 평형 추종:** V4는 **폭기를 유지한 채** tank·ref가 각각 **진짜
   평형(평탄)에 도달할 때까지** 반복 측정합니다 — 폭기를 끄고 닫아두는 방식이
   아니라 두 물을 같은 평형(천장)으로 끌고 갑니다.

밀폐가 평형의 기준(헤드스페이스 pCO₂)을 고정하므로 평형 추종은 *움직이는* 천장이
아니라 *고정된* 천장을 향하게 되어, 측정 시간차(gap)에 따른 드리프트 오차까지
사라집니다. (근거·실측은 [측정 대장](measurement-ledger.md) 참조: 6/18 개방 셋업의
ΔpH −0.042/−0.043가 방 CO₂ 스윙과 무관하게 일정함을 보였고, **6/19 밀폐 적용 후
새벽 ΔpH가 −0.008로 붕괴**해 새벽 오차가 제거됨.)

- **폭기 중 측정 + 평탄 판정**: `tank`/`ref`를 30초 간격으로 반복하며 **최근 4개
  측정의 정수 milli-pH (max−min) ≤ 2 mpH**면 평형으로 보고 종료(윈도우 span 판정).
  정수 비교라 float 지터가 없고, 느린 크리프에 조기 종료되지 않습니다.
- **2-phase**: **[A]** tank·ref 동시 폭기 + tank 평탄까지(ref는 홀딩 챔버에서
  co-aeration) → 전이(무대기) → **[B]** ref 평탄까지(co-aeration이라 평형 근처서
  시작 → 빨리 수렴).
- **무한 대기 방지**: phase별 최대 측정시간 `PHASE_MAX_SECS=7200`s(=2h), 최대 횟수
  `MEAS_MAX=240`, 연속 측정실패 `FAIL_MAX=5`, 시리얼 read 타임아웃. 미평탄 상한
  도달 시 마지막값 채택 + 경고(`dkh.dat`에 음수 표식).
- **트림평균 전위**: 펌웨어가 64샘플을 정렬해 상·하위 16개를 버리고 중앙 32개만
  평균 → 폭기 버블 스파이크 제거(차동이라 절대 pH만 미세 변동, dKH 무영향).
- **프로브 보관액 3M KCl**: 측정 외 상시 소크가 곧 컨디셔닝이라 별도 재생 루틴
  불필요. 중성염이라 잔류(캐리오버)가 dKH에 무영향 → V4는 헹굼 단계 생략.

### 전체 흐름 (measure_kh_once.py)

배관(2026-06-20): `m1`=본수조↔홀딩, `m2`=홀딩↔측정챔버, `m3`=KCl↔측정챔버,
`m4`=참조수(5L 위즈수조)↔측정챔버. **측정 순서 = tank 먼저 → ref 나중** —
tank 측정 내내 5L 위즈수조를 *동시 폭기*해 ref 가 5L서 co-aeration → ref 차례엔
이미 평형 근처라 빨리 수렴합니다. (헹굼 단계는 V4에서 제거됨.)

```
── 준비 ──────────────────────────────────────────
  airoff → ton
  ① m3b:68  KCl 보관액 배출 (측정 챔버 비우기)
  ② m1f:70  본수조수 → 홀딩 챔버
  ③ m2f:60  홀딩 → 측정 챔버 (tank 측정수 채움)

── [A] tank 평탄까지 ─────────────────────────────
  airoff → ron   (측정 챔버 tank + 5L 위즈수조 *동시* 폭기)
  ④ tank 평탄 측정 (30초 간격 반복, span4≤2mpH AND net8≤1mpH)
       ※ 이 동안 5L 위즈수조가 co-aeration → ref 미리 평형 근처로

── 전이 (무대기: 홀딩 파킹으로 ref 측정 조기 시작) ──
  airoff → ton
  ⑤ m2b:68  측정 챔버 tank → 홀딩 *임시 파킹* (완전 배출 대신 빠른 비움)
  ⑥ m4f:60  참조수 5L → 측정 챔버 (동시폭기로 이미 평형 근처)

── [B] ref 평탄까지 ──────────────────────────────
  airoff → ron   (측정 챔버 ref + 5L 위즈수조 *동시* 폭기)
  ⑦ ref 평탄 측정 (co-aeration이라 빨리 수렴) → airoff
  ⑧ calkh    dKH 계산 + 출력 + 이력 저장
       └ calref 모드(--setref): calkh 대신 calref = ref dKH 역산·EEPROM 저장

── 정리 ─────────────────────────────────────────
  ton
  ⑨ m4b:70  참조수 측정 챔버 → 5L 위즈수조 회수 (긴 호스 +10)
  ⑩ m1b:82  파킹된 tank 홀딩 → 본수조 마무리 배출
  ⑪ m3f:60  KCl 재공급 (프로브 소크) → airoff
```

> 펌웨어는 측정 순서와 무관합니다. `ref`/`tank` 플래그가 독립 저장되고
> `calkh`/`calref`는 둘 다 갖춰진 뒤 계산하므로 tank 우선이어도 동작이 같습니다.
>
> **★규칙:** 모든 액체 이동(`mXf`/`mXb`) 직전에 `airoff`로 폭기를 끄고, 펌프 구동 전
> `ton`으로 PWM 제어기를 켭니다. 폭기(`ron`)는 *액체 정지 구간*(측정)에만.
>
> **★종료 상태:** V4는 측정 후 `airoff`(KCl 소크 상태)로 끝납니다 — 구 버전의
> "측정 사이 기포기 ON 유지(terminal ron)"는 **제거**되었습니다.
>
> 오류/비정상 종료 시 `_safe_cleanup`(에어 OFF → 측정 챔버 배출 `m2b:68`→`m1b:82`
> → KCl 소크 `m3f:60` 복원)이 돌고, KCl 소크 미검증이면 에러로 `0.0`을 기록합니다.

### 구현: PC측 스크립트 (bin/)

평탄(수렴) 판정(측정값 비교 후 반복 여부 결정)이 필요하므로 펌웨어 매크로가
아닌 PC측 파이썬 스크립트가 명령을 단계별로 전송합니다. (현재 펌웨어에는 `seq`
명령이 없습니다.)

| 스크립트 | 동작 |
|---|---|
| `bin/measure_kh_once.py` | **V4** — 1회 측정 후 종료 (Windows 작업 스케줄러 정시 실행용) |
| `bin/test_aeration_plateau.py` | tank 단일 평형곡선 진단 (V4와 동일 평탄 기준, 종료 시 KCl 소크) |
| `bin/firmware_sim.py` | 소켓 가상 포트 펌웨어 시뮬레이터 (회귀 테스트용, WSL 전용) |
| `bin/test_measure_sim.py` | 통합 회귀 테스트 (10 시나리오/49 검증) — [상세](bt-reconnect-and-testing.md#3-시뮬레이터-회귀-검증-배포-전-필수) |
| `bin/bt_health.py` | (보조) HC-06 BT 링크 드롭률·RTT 모니터 |

**V4 (`measure_kh_once.py`) 주요 상수:**

| 상수 | 기본값 | 의미 |
|---|---|---|
| `FLAT_SPAN_N` | 4 | 흔들림(span) 판정 윈도우 — 최근 N개 |
| `FLAT_SPAN_MPH` | 2 | 최근 `FLAT_SPAN_N`개 정수 milli-pH의 (max−min) ≤ 2면 흔들림 통과 |
| `FLAT_NET_N` | 8 | 드리프트(net) 판정 룩백 — span보다 긴 창(★B1, 느린 단조 꼬리 조기 latch 차단) |
| `FLAT_NET_MPH` | 1 | 최근 `FLAT_NET_N`개 양끝차 ≤ 1이면 드리프트 통과(span·net 둘 다 통과해야 평형) |
| `MEAS_INTERVAL` | 30 | 측정 간 간격(초) — 폭기 지속 |
| `PHASE_MAX_SECS` | 7200 | phase(tank/ref)별 최대 측정시간(초)=2h, 초과 시 마지막값+경고 |
| `MEAS_MAX` | 240 | phase별 최대 측정 횟수(백스톱)=7200/30 |
| `FAIL_MAX` | 5 | 연속 측정 파싱 실패 허용 → 초과 시 phase 실패 |
| `SEND_RETRY_MAX` | 3 | RF 순단 시 명령 재시도 횟수 |
| `KEEPALIVE_SECS` | 12 | 유휴 keepalive 간격(초) — HC-06 ~20초 유휴 드롭 예방 |
| `MEAS_READ_TIMEOUT` | 20 | 측정 1회 `[OK]` 대기 상한(초) |
| `LINK_PING_TIMEOUT` | 3 | `ensure_link`/`reconnect` 핑 응답 대기 상한(초) |

> RF 순단(블루투스) 대응 상수(`SEND_RETRY_MAX`·`KEEPALIVE_SECS`·`RECONNECT_TRIES` 등)와 그 동작은 [블루투스 통신 안정화 & 시뮬레이터 검증](bt-reconnect-and-testing.md)에서 자세히 다룹니다.

> 폭기 시간은 **고정값이 아니라 평형(평탄)까지 적응**합니다(구 `AIR_SECS`/`STABLE`/`CONV_EPS` 폐기). 측정 펌프초: tank 채움(본수조→홀딩) `m1f:70`·완전 배출(홀딩→본수조) `m1b:82`, 이송(홀딩↔측정챔버) `m2f:60`/`m2b:68`, 참조수(5L↔측정챔버) `m4f:60`/`m4b:70`(긴 호스라 역방향 +10), KCl `m3b:68`/`m3f:60`.

**`dkh.dat` 규약** (`HH ref_pH tank_pH ref_kh(8.448) tank_kh temp`):

- **에러 표식 = 5값 전부 0** (측정 실패/타임아웃/KCl 소크 실패). **에러 래치**: 마지막 줄이 에러 표식이면 다음 실행은 측정 없이 에러 표식만 재기록 — 수동으로 마지막 에러 줄을 지우기 전까지(오류 무인 반복 방지).
- **평탄 미도달 = `tank_kh` 음수(−)** 표식 (값 크기는 유효, 서버가 부호로 인지). 전부-0 에러 표식과 구분되어 래치 안 걸림.
- 평탄 도달 여부·측정 횟수는 로그(`measure_kh.log`)와 결과 헤더(`평탄도달 : tank N회 O / ref N회 O`)에 남습니다.

### 1회 측정 실행법 (`measure_kh_once.py`)

1회만 측정하고 종료하는 스크립트입니다. Windows 작업 스케줄러가 정시(05:00/13:00/21:00)에 호출하지만, 수동 실행도 가능합니다.

**동작:** 준비 → **[A] tank·ref 동시 폭기 + tank 평탄까지** → 전이 → **[B] ref 평탄까지** → `calkh` → 정리 후 `airoff`(KCl 소크)로 종료. 평형까지 적응하므로 1회 소요는 가변이며(방 CO₂·시작 격차 의존) **대략 35~50분**, phase 상한(각 7200s=2h, 두 phase 합 최대 4h = 측정 갭 8h의 절반)에 걸리면 더 길어질 수 있습니다.

**포트 지정:** 첫 번째 명령행 인자로 포트를 넘길 수 있고, 없으면 스크립트 내 `PORT` 상수(현재 `COM9`)를 씁니다.

**모드:** 인자가 없으면 `calkh`(수조 dKH 측정 → `dkh.dat` 기록). `--setref <수조실측dKH>` 를 주면 `calref`(참조수 dKH 역산·EEPROM 저장, `dkh.dat` 기록 안 함) — 자세한 내용은 [사용설명서 §3.2](user-manual.md#32-자동-측정-pc-연동)를 참조하세요.

```bash
# 콘솔에서 출력을 보며 실행 (포트 = 스크립트 기본값 COM9)
python measure_kh_once.py

# 포트 직접 지정
python measure_kh_once.py COM7

# ref dKH 교정(역산) — 알려진 수조 dKH 기준
python measure_kh_once.py --setref 8.448

# 콘솔 없이 실행 (스케줄러 방식) — 출력은 C:\dkh\measure_kh.log 로 redirect
pythonw measure_kh_once.py

# WSL에서 Windows 파이썬으로 수동 실행 (cp949 인코딩 오류 회피용 -X utf8 필수)
/mnt/c/dkh/python313/python.exe -X utf8 'C:\dkh\work\measure_kh_once.py' 2>&1
```

**PowerShell에서 직접 실행** (정션 `C:\dkh` 경로 사용, `-X utf8` 필수):

```powershell
# 일반 측정 (calkh) — 출력을 콘솔에서 봄
& C:\dkh\python313\python.exe -X utf8 C:\dkh\work\measure_kh_once.py

# 포트 직접 지정
& C:\dkh\python313\python.exe -X utf8 C:\dkh\work\measure_kh_once.py COM7

# ref dKH 교정 (calref) — 수조 실측 8.448 dKH 기준으로 참조수 dKH 역산·저장
& C:\dkh\python313\python.exe -X utf8 C:\dkh\work\measure_kh_once.py --setref 8.448

# 콘솔 없이 (스케줄러와 동일) — 출력은 C:\dkh\measure_kh.log 로
& C:\dkh\python313\pythonw.exe -X utf8 C:\dkh\work\measure_kh_once.py
```

> - **포트(COM9)는 블루투스 페어링에 묶입니다.** 평소 유지되지만 장치 삭제 후 재페어링하면 번호가 바뀌므로, 그때 실제 포트를 인자로 넘기거나 `PORT` 상수를 수정합니다.
> - 측정 포트는 스케줄러 작업과 공유하므로, **정시 측정(05/13/21시)이 진행 중일 때 수동 실행하면 시리얼 충돌**이 납니다.
> - `pythonw`는 `sys.stdout`이 `None`이라, 스크립트가 모든 출력을 `C:\dkh\measure_kh.log`로 보냅니다(1MB 초과 시 새로 시작).

### Windows 작업 스케줄러 등록 (정시 자동 측정)

`measure_kh_once.py`를 **매일 05:00 / 13:00 / 21:00**(05시부터 8시간 간격, 하루 3회) 자동 실행하는 예입니다. 한 개의 반복 패턴(Repetition) 대신 **고정 시각 Daily 트리거 3개**를 씁니다 — 매일 재무장되어 재부팅 후에도 스케줄이 깨지지 않고, 꺼져 있던 시간대의 측정은 보충하지 않습니다(의도된 동작).

**관리자 PowerShell**에서 실행합니다(한글 경로 문제를 피하기 위해 ASCII 정션 `C:\dkh` 경로 사용):

```powershell
# 1) 하루 3회 고정 시각 트리거 (05시 + 8h 간격)
$triggers = @(
    New-ScheduledTaskTrigger -Daily -At 05:00
    New-ScheduledTaskTrigger -Daily -At 13:00
    New-ScheduledTaskTrigger -Daily -At 21:00
)

# 2) 콘솔 없는 pythonw 로 1회 측정 스크립트 실행
$action = New-ScheduledTaskAction `
    -Execute 'C:\dkh\python313\pythonw.exe' `
    -Argument 'C:\dkh\work\measure_kh_once.py'

# 3) 설정: 배터리·유휴로 중지 금지, 1회 측정 상한 270분(스크립트 자체 최대 ~4h + 여유), 중복 실행 시 새 인스턴스 무시
$settings = New-ScheduledTaskSettingsSet `
    -AllowStartIfOnBatteries -DontStopIfGoingOnBatteries `
    -ExecutionTimeLimit (New-TimeSpan -Minutes 270) `
    -MultipleInstances IgnoreNew
$settings.IdleSettings.StopOnIdleEnd = $false

# 4) 로그인한 대화형 세션의 사용자 토큰으로 실행 (COM 포트는 사용자 세션에 바인딩됨)
$principal = New-ScheduledTaskPrincipal -UserId $env:USERNAME -LogonType Interactive

Register-ScheduledTask -TaskName 'Measure KH' -TaskPath '\tsyi\' `
    -Trigger $triggers -Action $action -Settings $settings -Principal $principal -Force
```

설정값의 이유:

| 설정 | 값 | 이유 |
|---|----|---|
| `AllowStartIfOnBatteries` / `DontStopIfGoingOnBatteries` | 켬 | 노트북에서 기본값(배터리 시 중지)이 데몬·측정을 로그 없이 강제 종료하는 문제 회피 |
| `IdleSettings.StopOnIdleEnd` | `$false` | 유휴 종료 시 작업이 중단되지 않도록 |
| `ExecutionTimeLimit` | 270분 | V4 1회 측정은 평형까지 적응하므로 대개 **35~50분**이지만, tank·ref 두 phase가 모두 상한(각 `PHASE_MAX_SECS`=2h)에 걸리면 측정만 최대 4h + 이송·정리 여유가 필요. 스크립트 자체 phase 상한이 런타임을 4h로 묶으므로, 정당한 장시간 측정을 죽이지 않도록 그보다 넉넉한 270분으로 둠(멈춘 프로세스는 시리얼 타임아웃·`FAIL_MAX`로 스크립트가 자체 종료) |
| `MultipleInstances` | `IgnoreNew` | 직전 측정이 진행 중이면 다음 정시 트리거는 스킵 |
| `LogonType` | `Interactive` | COM(블루투스) 포트가 사용자 세션에 바인딩되어, 로그인된 대화형 세션에서만 접근 가능 |

> **로그인 세션 필요:** 로그아웃하면 세션·토큰이 파괴되어 작업이 죽습니다. 자리를 비울 땐 로그아웃 대신 **잠금(Win+L)** 을 쓰면 세션이 유지되어 계속 동작합니다(절전·디스플레이 OFF는 무방). 자동 복귀가 필요하면 자동 로그인을 권장합니다.
>
> 복잡한 PowerShell은 bat에 인라인으로 쓰지 말고 `.ps1`로 분리한 뒤 `register_measure_kh.bat`에서 `powershell -ExecutionPolicy Bypass -File "%~dp0register_measure_kh.ps1"` 한 줄로 호출합니다(한글 경로 + `^` 줄연속 조합 인코딩 오류 회피).

### 운용 메모

- 참조수 5L 증발 농축(1% ≈ +0.08 dKH 상당) → 주기적 RODI 수위 보충 또는 `calref`
- 3M KCl 제조: RODI 1L당 KCl 224g (≈22% w/v). 포화(≈4.2M@25°C) 대비 여유가
  있어 저온에서도 석출 없음
- 수동·단발 테스트는 펌웨어 명령(`ref`/`tank`/`calkh`, 모터·에어)으로 직접 가능하나
  (user-manual.md 참조) 평탄(수렴) 판정은 PC측 스크립트만 지원
- 측정 중 방 CO₂ **드리프트**(저녁 환기 변동 등)는 개방 셋업에서 tank·ref를 다른 평형에서
  latch시켜 오차를 만들 수 있었으나, **밀폐 공통 헤드스페이스가 이 원인을 구조적으로 제거**합니다
  (외부 공기 차단 → 헤드스페이스 pCO₂ 고정 + 평형 즉시 도달로 측정 시간차 붕괴). 상세 검증은 [측정 대장](measurement-ledger.md) 참조

### 블루투스 통신 안정화 & 시뮬레이터 검증

측정은 HC-06 블루투스 SPP(COM9)로 통신하는데, 이 RF 링크가 간헐적으로 끊긴다(주로 **명령을 보내려는 순간 이미 끊겨 있음**). 이에 대응해 `measure_kh_once.py`의 `send()`는 다음을 보장한다.

1. **송신 전 연결 확인**(`ensure_link` = `status` 핑) — 모든 명령은 보내기 전 링크 생존을 확인
2. 끊겼으면 **재연결**(`reconnect` = 포트 `close→open` + 펌웨어 응답 확인)
3. 보낸 뒤 연결 문제(예외·응답 미수신)면 **재연결 후 재시도**(`SEND_RETRY_MAX`회)
4. **모터는 재시도 시 먼저 정지(`mNs`) 후 재송신** — 펌프 중복 구동 방지
5. (예방) 유휴 구간 **keepalive** — 12초마다 빈 줄로 ~20초 유휴 드롭 차단

호스트측으로는 Wi-Fi/BT 네트워크 장치 비활성화·USB 선택적 절전 OFF로 2.4GHz 간섭·포트 절전을 줄인다.

**회귀 검증(배포 전 필수):** 소켓 가상 펌웨어 시뮬레이터로 정상·예외 상황을 검증한다.

```bash
cd bin && python3 test_measure_sim.py     # WSL, 10 시나리오/49 검증 — 전부 PASS여야 배포
```

> 증상·호스트 조치·4계층 동작·상수·시뮬레이터/테스트 구성(시나리오 표)·배포 안전성은
> **[블루투스 통신 안정화 (RF 순단 대응) 및 시뮬레이터 회귀 검증](bt-reconnect-and-testing.md)** 에 상세히 정리되어 있다.

## 온도 환경

위즈 탱크(5L) 안에 모든 비이커(200ml)가 담겨 있으므로:

- 참조수, 수조수 샘플, 3M KCl이 모두 동일 온도로 유지됨
- DS18B20이 위즈 탱크 수온을 측정하여 Nernst 온도 보상에 사용
- pH 전극의 온도 보상이 정확해짐

## 측정 정확도

### Nernst 온도 보정

pH 전극의 기울기는 온도에 따라 변합니다 (Nernst 방정식: slope = 0.19842 × T(K) mV/pH). 보정 온도를 EEPROM에 저장하여 보정 시와 측정 시 온도가 달라도 정확하게 보상합니다.

```
pH_corrected = 7.0 + (pH_raw − 7.0) × (273.15 + T_cal) / (273.15 + T_meas)
```

보정 온도 저장 후 **15°C~35°C 전 범위에서 Nernst 보정 오차 0%**입니다.

### 오차 요인 분석 (dKH 8.5 기준)

| 요인 | pH 오차 | dKH 오차 | 비고 |
|---|---|---|---|
| ADS1115 ±1 LSB | ±0.0007 pH | ±0.010 | 16비트 ADC |
| 64회 오버샘플링 | ÷8 | ±0.001 | √64 = 8배 개선 |
| Nernst 보정 | 0 | 0 | 보정 온도 EEPROM 저장 |
| DS18B20 ±0.5°C | ±0.0017 pH | ±0.023 | 온도 센서 정밀도 |
| **pH 프로브 반복성** | **±0.005 pH** | **±0.070** | **지배적 오차 요인** |
| **전체 (RSS)** | | **±0.073 dKH (±1.2%)** | |

### 시스템 성능 요약

```
측정 분해능:    ±0.001 dKH (소수점 3자리)
시스템 정확도:  ±0.07 dKH (±1.2%)
유효 자릿수:    소수점 이하 2자리
```

> 정확도의 97%는 pH 프로브(유리전극) 자체의 반복성에 의해 결정됩니다. ADC, Nernst 보정, 펌웨어 계산 로직은 프로브 성능을 충분히 살릴 수 있는 수준입니다.

### 실측 안정성 (KCL 용액, 5회 연속)

```
전압 편차: ±0.061 mV
pH 편차:   ±0.0005 pH
온도:      28.6°C 일정
```

> ADS1115 16비트 분해능의 이론적 한계에 근접하는 안정성입니다.

### 진단: 프로브 vs 셋업 분리 (널 테스트)

측정 시 참조수 pH와 수조수 pH 사이에 ΔpH 오프셋이 남을 수 있습니다(두 물이 동일 해수라면 이상적으로 ΔpH = 0). 이 오프셋의 원인이 **프로브·경로의 측정 아티팩트**인지, **두 물의 실제 화학 차이(CO2 탈기 비대칭)**인지 가르는 절차입니다.

**왜 재보정이 답이 아닌가:** dKH는 차동식(`KH_tank = KH_ref × 10^(−ΔpH)`)이라, pH 보정의 offset 오차는 참조·수조 양쪽에 똑같이 실려 ΔpH에서 상쇄되고, slope 오차도 작은 ΔpH(보통 0.02~0.07)에 비례하므로 영향이 미미합니다. 따라서 오프셋을 재보정(`calph`)으로 잡으려 하면 노이즈만 늘 뿐이며, 먼저 원인을 분리해야 합니다. (재보정은 절대 pH 동작점을 ADC 선형구간 안으로 유지하는 **예방·점검**용입니다.)

**절차:** **동일 해수**를 참조 경로와 수조 경로 양쪽에 넣고(진짜 ΔKH=0) V4로 측정합니다. V4는 양쪽을 폭기 중 진짜 평형까지 끌고 가므로, 남는 ΔpH가 프로브·경로 아티팩트인지 판별하기 좋습니다.

| 결과 | 해석 | 조치 |
|---|---|---|
| ΔpH ≈ 0 | 프로브·경로 정상, 차동이 방 CO₂를 잘 상쇄 | 그대로 운용 |
| ΔpH = 작은 상수 (방 CO₂ 무관, 재현) | 구조 baseline 후보 (경로 비대칭 등) | **영점보정은 독립 재현 확인 후** — 동일 해수 새 널테스트로 일정 vs 우연 판정 ([측정 대장](measurement-ledger.md)) |
| ΔpH가 방 CO₂ 따라 변동 | 폭기/평형 비대칭(미완) 또는 외기 유입 | **밀폐 공통 헤드스페이스 확인**(분리 밀폐·누설 점검), 평탄 도달 확인(`평탄도달 O`) |

> **현황(2026-06):** 개방 셋업(200mL 개방 챔버 tank + 5L 반밀폐 ref) 널테스트에서 V4가 방 CO₂ 의존성을 제거(ΔpH −0.042/−0.043 동일)했으나 baseline은 상수가 아니었고(13:00 −0.026, +0.29 dKH = 증발 confound 의심), 무보정 원시오차도 −0.78로 컸습니다. **2026-06-19 밀폐 공통 헤드스페이스 적용 후 첫 새벽 측정에서 ΔpH가 −0.008로 붕괴**(새벽 오차 제거)하고 원시오차도 −0.165로 줄어 목표 정확도 안에 들어왔습니다 — 밀폐가 새벽 CO₂와 증발 두 잔여 오차원을 동시에 덮은 것으로 보입니다. 다만 단일 점이므로 13:00 밀폐 측정(증발 흩어짐 판정)·시계열 누적까지는 **영점보정 확정을 보류**합니다. 상세는 [측정 대장](measurement-ledger.md).

**프로브 건강 계기:** 별도 장비 없이 `measure_kh.log`의 **평탄 도달까지 측정 횟수**(`tank N회 / ref N회`)로 전극·평형 상태를 모니터링합니다. 같은 조건에서 횟수가 점차 늘면 응답 둔화(노화) 또는 접합부(KCl junction) 오염 신호이며, 이때 묽은 HCl 접합 세척을 검토합니다. 접합전위 1 mV 변동 ≈ 0.017 pH ≈ 0.3 dKH이므로 무시할 수 없습니다. (단, 평탄 횟수는 폭기 평형시간·시작 격차에도 좌우되므로 추세로 해석.)

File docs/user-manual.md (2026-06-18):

# AquaWiz 사용 설명서 v2.0

**고정밀 pH / 경도(dKH) 측정 시스템**

> 관련 문서: [프로젝트 개요 (README)](../README.md) | [자동화 환경 구성](system-setup.md) | [준비물 목록](parts-list.md) | [측정 대장](measurement-ledger.md)

| 항목 | 내용 |
|---|---|
| 측정 공식 | `KH_tank = KH_ref * 10^(-DeltaPH)` |
| 블루투스 통신 | HC-06 하드웨어 Serial D0/D1 (9600 baud) |
| 플래시/RAM | 약 90% / 약 58% (Arduino Nano ATmega328P) — `seq`/`wait`/`air` 레거시 제거로 여유 확보 |
| 전위 산출 | 64샘플 **트림평균** (정렬 후 상·하위 각 16개 버리고 중앙 32개 평균 → 폭기 버블 스파이크 제거) |
| dKH 이력 | 최근 5개 (RAM, 전원 OFF 시 소멸) |

---

## 1. 시스템 개요

### 1.1 측정 원리

> 탈기 후 두 샘플의 CO2 농도가 동일해지면, pH 차이(DeltaPH)는 순수하게 알칼리니티(dKH) 차이만을 반영합니다.

```
[CO2] = 3 x KH x 10^(7-pH)
KH_tank = KH_ref x 10^(-DeltaPH)
DeltaPH = pH_ref - pH_tank
```

- `DeltaPH > 0` : 수조 pH가 참조보다 낮음 → 수조 dKH 낮음
- `DeltaPH < 0` : 수조 pH가 참조보다 높음 → 수조 dKH 높음

### 1.2 하드웨어 구성

| 부품 | 모델 | 역할 |
|---|---|---|
| MCU | Arduino Nano V3.0 (ATmega328P) | 메인 컨트롤러 |
| pH 센서 | DFRobot SEN0161-V2 | pH 전압 측정 |
| ADC | Adafruit ADS1115 | 16비트 I2C ADC (A4/A5) |
| 온도 센서 | DS18B20 | 1-Wire 온도 측정 (A0=D14) |
| 블루투스 | HC-06 | 하드웨어 Serial D0/D1 (9600baud) |
| 모터 드라이버 | L298N x 3 | L298N1/N2: 도징 펌프 4개 (12V), L298N3: 에어 펌프 (5V) |

### 1.3 핀 배치

| 핀 | 연결 | 설명 |
|----|---|---|
| D0 (RX) | HC-06 TX | 블루투스 수신 (직결) |
| D1 (TX) | HC-06 RX | 블루투스 송신 (전압분배기: R4 10k + R5 20k) |
| D4~D7 | L298N1 IN1~IN4 | 모터1/2 제어 |
| D8~D11 | L298N2 IN1~IN4 | 모터3/4 제어 |
| D12 | L298N3 IN2 | 에어 펌프 ON/OFF (`ron`/`roff`) |
| D13 | L298N3 IN4 | PWM 속도 제어기 ON/OFF (`ton`/`toff`) |
| A0 (D14) | DS18B20 DQ | 1-Wire 온도센서 |
| A4 | ADS1115 SDA | I2C 데이터 |
| A5 | ADS1115 SCL | I2C 클럭 |

> **주의:** 업로드 시 HC-06을 D0/D1에서 반드시 분리하세요. 분리하지 않으면 업로드가 실패합니다.

### 1.4 블루투스 터미널 앱

안드로이드 스마트폰에서 블루투스 시리얼 통신으로 AquaWiz를 제어합니다.

**추천 앱:**  <a href="https://play.google.com/store/apps/details?id=de.kai_morich.serial_bluetooth_terminal" target="_blank">Serial Bluetooth Terminal</a> (Kai Morich, 무료)

- HC-05, HC-06 등 Bluetooth Classic SPP 지원
- 시리얼 터미널 방식으로 명령 입력/응답 확인
- 매크로 기능으로 자주 쓰는 seq 명령 등록 가능
- 평점 4.6, 100만+ 다운로드

**연결 방법:**
1. 안드로이드 설정 → 블루투스 → HC-06 페어링 (PIN: 1234)
2. Serial Bluetooth Terminal 앱 실행
3. 좌측 메뉴 → Devices → HC-06 선택 → Connect
4. 9600 baud 자동 인식, 명령 입력 시작

---

## 2. 초기 설정

### 2.1 pH 2점 보정

> **주의:** 가장 먼저 수행해야 합니다. 보정값은 EEPROM에 저장되어 전원 OFF 후에도 유지됩니다.

| 단계 | 명령 | 설명 |
|---|---|---|
| 1 | `enterph` | 보정 모드 진입 |
| 2 | `calph` | pH 7.0 버퍼 용액 삽입 → 자동 인식 후 보정 |
| 3 | `exitph` | 보정값 EEPROM 저장 후 종료 |
| 4 | `enterph` | 다시 진입 |
| 5 | `calph` | pH 4.0 버퍼 용액 삽입 → 자동 인식 후 보정 |
| 6 | `exitph` | 보정값 EEPROM 저장 후 종료 |

### 2.2 온도 오프셋 설정

표준 온도계와 DS18B20의 차이값을 설정합니다. EEPROM에 저장됩니다.

```
settemp:-0.3
```

DS18B20 오프셋 설정 (예: 표준 25.0도, DS18B20 25.3도 → -0.3 입력). 범위: -10.0 ~ 10.0도.

설정 즉시 raw 온도와 보정 후 온도를 출력하여 확인할 수 있습니다.

### 2.3 참조 dKH 설정

참조 해수의 알칼리니티를 dKH로 입력합니다. EEPROM에 저장됩니다.

```
setref:8.5
```

참조 해수 dKH 설정 (범위: 0.5 ~ 30.0 dKH). 자연 해수 일반값은 약 7~8 dKH입니다. 실측값 사용을 권장합니다.

---

## 3. 측정 방법

### 3.1 표준 측정 절차

> **주의:** 참조수와 수조수를 동일 공간에서 30분 이상 동시 탈기 후 측정해야 정확합니다.

| 단계 | 명령 | 설명 |
|---|---|---|
| 1 | `settime:HH` | 현재 시(0~23) 설정 (이력 타임스탬프용, 예: `settime:14`) |
| 2 | `ref` | 참조수 pH 측정 (약 8초, 64회 오버샘플링) — RAM 저장 |
| 3 | `tank` | 수조수 pH 측정 (약 8초) |
| 4 | `calkh` | dKH 계산 + 결과 출력 + 이력 저장 |

> 참조수 pH는 RAM에만 저장됩니다. 전원 ON 후 매번 `ref` 명령을 실행해야 합니다.

### 3.2 자동 측정 (PC 연동)

> **변경(현재 펌웨어):** 폭기 중 측정을 반복해 **진짜 평형(평탄)까지** 측정해야 하므로(평탄 판정 = 측정값 비교 후 반복 결정), 자동화는 PC측 파이썬 스크립트가 담당합니다. 펌웨어의 `seq`/`seqstop`/`wait`/`air` 명령은 **제거**되었습니다. 단발 테스트는 위 §3.1처럼 `ref`/`tank`/`calkh`를 직접 입력하거나 모터/에어 명령을 수동 전송하면 됩니다.

PC측 자동 측정 스크립트:

```bash
# 1회 측정 후 종료 (Windows 작업 스케줄러 정시 호출 / 수동 실행 가능)
python bin/measure_kh_once.py        # 포트 = 기본값 COM15
python bin/measure_kh_once.py COM7   # 포트 직접 지정
```

스크립트가 준비 → **[A] tank·ref 동시 폭기 + tank 평탄까지** → 전이 → **[B] ref 평탄까지** → `calkh` → 정리 순으로 펌웨어 명령을 단계별 전송합니다. 상세 흐름·상수·스케줄러 등록은 [자동화 환경 구성 — 자동 측정 시퀀스](system-setup.md#자동-측정-시퀀스-pc-측-v4)를 참조하세요.

### 3.3 calkh 결과 출력

```
===[dKH]===
시각:14   참조pH:8.350   수조pH:8.201   dPH:0.1490   refKH:8.50 dKH   수조KH:6.012 dKH   온도:25.0C
===========
```

- ppm, meq/L, 상태 표시는 제거되었습니다. dKH 값으로 직접 판단하세요.
- 산호 수조 권장 범위: **8 ~ 12 dKH**

### 3.4 status 출력 예시

```
=== 상태 ===
시각:14
온도:25.30C 오프셋:-0.30 보정T:25.0C
수조pH:8.201
참조pH:8.350
dPH:0.1490
refKH:8.50 dKH
수조KH:6.012 dKH
KH이력:2개
[M1] 정지
[M2] 정지
[M3] 정지
[M4] 정지
[직접] 에어(D12):OFF PWM(D13):OFF
============
```

| 항목 | 설명 |
|---|---|
| 온도 / 오프셋 / 보정T | 현재 수온, DS18B20 오프셋, pH 보정 시 온도 (Nernst 기준) |
| [M1]~[M4] | 모터 상태 — 동작 중이면 잔여 시간 표시 |
| [직접] 에어(D12) / PWM(D13) | D12(에어 펌프)·D13(PWM 속도 제어기) 핀 ON/OFF 상태 |

> 구 펌웨어의 `[대기]`(wait)·`[SEQ]`(seq) 표시는 해당 명령 제거와 함께 사라졌습니다.

### 3.5 calref — 참조 dKH 역산

참조 해수의 dKH를 직접 측정하기 어려운 경우, 수조수의 dKH(상용 테스트킷 실측값)를 기준으로 참조수의 dKH를 역으로 계산합니다.

```
1. setref:8.5          ← 수조 dKH 실측값 (상용 테스트킷)
2. ref                 ← 참조수 pH 측정
3. tank                ← 수조수 pH 측정
4. calref             ← 참조 dKH 역산 + EEPROM 저장
```

**계산 공식:**

```
newRefDKH = 수조dKH × 10^(-(tankPH − refPH))
```

> 참고: calref의 `dPH`는 `tankPH − refPH`로, calkh/§1.1의 ΔpH(`refPH − tankPH`)와 부호가 반대입니다. calref는 calkh의 역산(참조 dKH를 거꾸로 구함)이라 부호가 뒤집힌 것이며, 결과는 서로 일관됩니다.

**출력 예시:**

```
===[calref]===
  시각:14
  참조pH:8.350
  수조pH:8.201
  dPH:-0.1490
  새refDKH:11.985 dKH
  수조dKH:8.50 dKH
  온도:25.0C
===============
[OK] refDKH 저장:11.985 dKH
```

> 이후 `calkh`로 측정하면 저장된 refDKH를 기준으로 수조 dKH를 자동 계산합니다. 이력은 저장하지 않습니다.

---

## 4. 명령어 전체 참조

### 4.1 pH 측정 명령

| 명령 | 설명 |
|---|---|
| `settime:HH` | 현재 시 설정 (0~23, 예: `settime:14`) — 이력 타임스탬프용 |
| `ref` | 참조수 pH 측정 → RAM 저장 (전원 OFF 시 소멸, 매번 측정 필요) |
| `tank` | 수조수 pH 측정 |
| `calkh` | dKH 계산 + 출력 + 이력 저장 (최대 5개) |
| `calref` | 수조 dKH 기준으로 참조 dKH 역산 + EEPROM 저장 (아래 참고) |
| `setref:xx.x` | 참조 dKH 설정 [EEPROM] (예: `setref:8.5`, 범위: 0.5~30.0) |
| `settemp:xx.x` | 온도 오프셋 설정 [EEPROM] (예: `settemp:-0.3`, 범위: +/-10.0) |
| `khhist` | dKH 이력 조회 (최신순 5개, 번호/시각/dKH) |
| `status` | 현재 전체 상태 출력 (아래 참고) |

| `help` | 명령어 도움말 출력 |

### 4.2 pH 보정 명령

| 명령 | 설명 |
|---|---|
| `enterph` | 보정 모드 진입 — 버퍼 용액에 프로브 삽입 후 안정화 |
| `calph` | pH 4.0 / 7.0 자동 인식 후 보정 |
| `exitph` | 보정값 EEPROM 저장 후 종료 |

### 4.3 펌프 모터 명령

| 명령 | 설명 |
|---|---|
| `m1f:초` | 모터1 정방향 N초 (예: `m1f:10`, 범위: 1~3600초) |
| `m1b:초` | 모터1 역방향 N초 |
| `m1s` | 모터1 즉시 정지 |
| `m2f:초` / `m2b:초` / `m2s` | 모터2 (L298N1 채널B) |
| `m3f:초` / `m3b:초` / `m3s` | 모터3 (L298N2 채널A) |
| `m4f:초` / `m4b:초` / `m4s` | 모터4 (L298N2 채널B) |

> PC측 측정 스크립트는 각 모터 명령의 완료 응답(`[모터N] 완료`)을 받은 뒤 다음 단계로 진행합니다.

### 4.4 에어 / PWM 공급 명령

| 명령 | 설명 |
|---|---|
| `ron` | D12 HIGH — 에어 펌프 ON (참조수+수조수 폭기) |
| `roff` | D12 LOW — 에어 펌프 OFF |
| `ton` | D13 HIGH — PWM 속도 제어기 ON (도징 펌프 구동 전 활성화) |
| `toff` | D13 LOW — PWM 속도 제어기 OFF |
| `airoff` | D12·D13 동시 LOW — 에어 + PWM 제어기 둘 다 OFF |

> `ron`/`roff`로 에어 펌프(D12)를, `ton`/`toff`로 PWM 속도 제어기(D13)를 독립적으로 켜고 끕니다. `airoff`는 두 핀을 한 번에 LOW로 내립니다.
> **하드웨어 규칙:** 액체 이동(`mXf`/`mXb`) 직전에는 반드시 `airoff`로 폭기를 끄고, 펌프 구동 전 `ton`으로 PWM 제어기를 켭니다.
> 구 펌웨어의 `air:총초:주기초`(교대 폭기) 명령은 **제거**되었습니다.

### 4.5 정지 명령

| 명령 | 설명 |
|---|---|
| `m1s`~`m4s` | 해당 모터 개별 즉시 정지 |
| `stop` | 전체 모터 정지 + 에어/PWM 핀 OFF (motorAllStop + stopAir) |

> 구 펌웨어의 `seq`/`seqstop`(시퀀스 매크로)·`wait:`(대기) 명령은 **제거**되었습니다. 자동 측정은 PC측 스크립트가 담당합니다(§3.2).

---

## 5. dKH 측정 이력

### 5.1 이력 구조

| 항목 | 내용 |
|---|---|
| 저장 위치 | RAM (전원 OFF 시 소멸 — EEPROM 미사용) |
| 최대 개수 | 5개 (라운드 로빈 — 6번째부터 가장 오래된 것 덮어쓰기) |
| 저장 항목 | 시각(HH), dKH |
| 타임스탬프 | `settime:HH` 설정값 기준 경과 시간 자동 보정 |

### 5.2 khhist 출력 형식

```
[KH이력] 5개
1  14  8.52
2  12  8.48
3  10  7.93
4  08  8.61
5  06  8.55
```

- 번호 1이 가장 최신, 번호가 클수록 오래된 값입니다.
- `settime` 미설정 시 시각은 `??`로 표시됩니다.

---

## 6. EEPROM 저장 항목

| 항목 | 저장 위치 | 비고 |
|---|---|---|
| pH 보정값 (pH4/7 전압) | `0x00~0x07` | DFRobot_PH 라이브러리 자동 관리 |
| 참조 dKH (`setref`) | `0x10~0x13` | 전원 OFF 후에도 유지 |
| 온도 오프셋 (`settemp`) | `0x14~0x17` | 전원 OFF 후에도 유지 |
| pH 보정 온도 (`exitph`) | `0x18~0x1B` | Nernst 보정 기준 온도, 보정 시 자동 저장 |
| 참조수 pH 전압 (`ref`) | RAM만 | 전원 ON 후 매번 측정 필요 |
| dKH 측정 이력 (`calkh`) | RAM만 | 전원 OFF 시 소멸 |

---

## 7. 오류 메시지 안내

| 메시지 | 조치 |
|---|---|
| `[ERR] ADS1115 실패!` | ADS1115 I2C 배선(A4/A5) 확인 후 재시작 |
| `[WARN] DS18B20 없음!` | DS18B20 배선(A0) 및 4.7k 풀업저항 확인 |
| `[WARN] DS18B20 오류→25C` | 온도 센서 일시 오류, 25도로 pH 계산 진행 |
| `[WARN] ref 없음→ref 실행` | `ref` 명령으로 참조수 측정 필요 |
| `[WARN] refDKH 없음→setref` | `setref:xx.x` 명령으로 참조 dKH 입력 필요 |
| `[ERR] tank 미측정` | `tank` 명령 실행 후 `calkh` 실행 |
| `[WARN] dKH 이상` | pH 보정 재실행 또는 참조 dKH 확인 |
| `[ERR] 모터시간 1~3600초` | 1~3600초 범위로 재입력 |

---

## 8. 사용 팁

### 8.1 정확한 측정을 위한 필수 조건

1. **동시 폭기:** 참조수와 수조수를 같은 공기로 동시에 폭기하여 CO₂(pCO₂)를 동일하게 맞춥니다. 차동식은 ref·tank가 같은 pCO₂일 때만 순수 KH차를 반영합니다.
2. **평형까지 측정:** 현재 자동 측정(PC측 V4)은 **폭기를 유지한 채** tank·ref가 각각 진짜 평형(평탄)에 도달할 때까지 반복 측정합니다. 즉 "뚜껑 닫고 측정"이 아니라 **폭기 중 평형 추종**으로 대기 CO₂를 공통모드로 상쇄합니다.
3. **온도 보정:** `settemp`로 DS18B20 오프셋을 설정하면 pH 계산 정확도가 높아집니다.
4. **pH 보정:** 월 1회 pH 4.0/7.0 버퍼 용액으로 2점 보정을 실시합니다.
5. **ref 재측정:** 전원 ON 후 반드시 `ref` 명령으로 참조수를 다시 측정해야 합니다(수동 측정 시).
6. **업로드:** HC-06을 D0/D1에서 분리한 후 업로드하고, 완료 후 다시 연결합니다.

### 8.2 산호 수조 권장 dKH 범위

| 범위 | dKH | 비고 |
|---|-----|---|
| 자연 해수 | 약 6.5~7.5 | 참조 기준 |
| 산호 수조 권장 | 8 ~ 12 | 일반적 권장 |
| SPS 산호 최적 | 8 ~ 9 | 경산호류 |
| LPS/소프트 코랄 | 7 ~ 11 | 연산호류 |

---

펌웨어 빌드, 필수 라이브러리, 업로드 절차는 [README — 빌드 및 업로드](../README.md#빌드-및-업로드)를 참조하세요.

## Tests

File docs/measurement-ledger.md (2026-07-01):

# KH 측정 대장 (코드 상태 · 환경 · 결과)

> 관련 문서: [프로젝트 개요 (README)](../README.md) | [자동화 환경 구성](system-setup.md) | [사용 설명서](user-manual.md) | [준비물 목록](parts-list.md)

> **이 문서의 의의:** 측정 정확도의 신뢰성을 떠받치는 1차 기록이다. 코드 버전(V0~V4)별 실측, 환경(방 CO₂) 통제, 차동 측정이 방 CO₂ 의존성을 제거함을 보인 ΔpH 검증, 그 해석을 뒷받침한 학술 문헌까지 — 많은 시행착오의 결과를 시각순으로 남긴다.

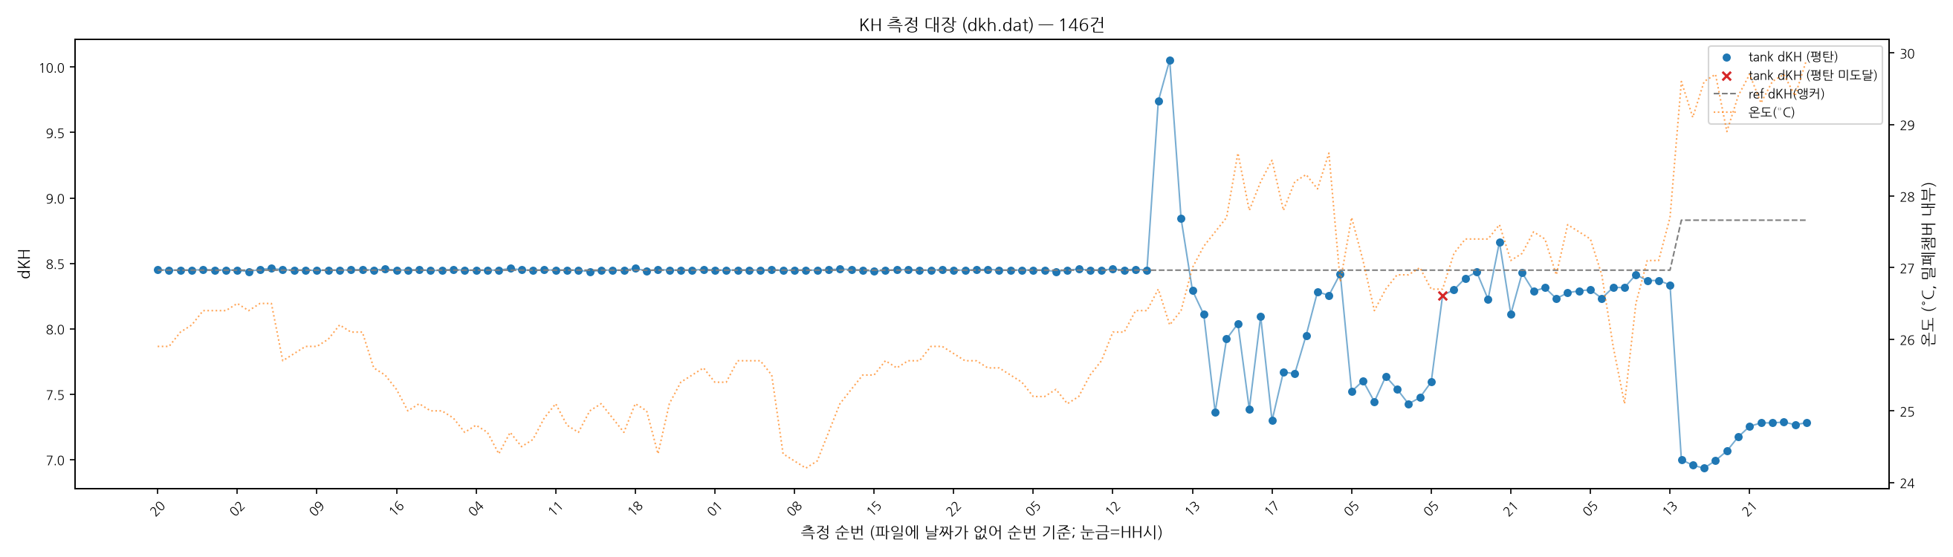
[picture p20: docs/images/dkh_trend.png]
dKH 추세


*하루 3회(05/13/21시) 측정 결과 자동 반영. WSL이 주기적으로 Windows 원본 `dkh.dat`을 [`data/dkh.dat`](../data/dkh.dat)로 동기화·push하면, GitHub Actions([`plot-dkh.yml`](../.github/workflows/plot-dkh.yml))가 이 그래프를 다시 그려 커밋한다 — 최대 수십 분 지연.*

ΔpH/dKH 검증을 계속하려면 "각 측정이 어떤 코드·환경에서 나왔는가"를 정확히 알아야 한다.
git 커밋만으로는 부족하다 — **6/16 13:00 변경(STABLE·EPS)과 v2 재작성은 커밋되지 않고 작업트리에서만
돌았다.** 그래서 이 대장에 측정 시각별로 직접 기록한다.

**기록 원칙:** 새 측정이 끝날 때마다 아래 표에 한 줄 추가. 값은 `measure_kh.log`(실제 실행 진실)와
`dkh.dat`에서 가져온다. 코드를 바꾸면 ① 새 "코드 버전" 항목을 정의하고 ② 가능하면 **커밋해 SHA를 남긴다**
(미커밋이면 표에 `(작업트리)`로 표기). 환경(방 CO₂)은 직접 로그가 없으므로 **절대 pH를 대리지표**로 쓴다
(절대 pH 낮음 = 방 CO₂ 높음). dKH 계산: `tank_dKH = 8.448 × 10^(−(ref_pH−tank_pH))`, ΔpH는 `tank_pH − ref_pH`.

dkh.dat 컬럼: `HH ref_pH tank_pH ref_kh(앵커 8.448) tank_kh temp`
- **에러 표식**: 5개 값 전부 `0.000…0.0` = 측정 실패/타임아웃/KCl 소크 실패. **에러 래치**(V4): 마지막 줄이 에러 표식이면 다음 실행은 측정 없이 에러 표식만 재기록 — *수동으로 마지막 에러 줄 제거* 전까지(오류 무인 반복측정 방지).
- **평탄 미도달 표식**(V4): `tank_kh`가 **음수(−)** = 정상 측정이나 평형 미도달(값 크기 유효, 서버가 부호로 인지). 에러 표식(전부 0)과 구분되어 래치 안 걸림.

---

## ★★★ 최종 결론 (2026-06-21) — 목표 정확도 달성, 계측 offset −0.06

며칠간의 "널테스트 오차가 계측기 결함인가, 물 문제인가" 모호함이 **완전 널테스트**로 종결되었다.

**핵심 결과 (완전 널, 6/21 19:00):** 위즈(5L) 해수를 떠서 tank 외부 챔버 100mL에도 넣어 **ref·tank 양쪽을 같은 물**로 만들었다(물 차이 = 구성상 0). 양쪽 모두 진짜 평탄 도달(tank 21회·ref 18회 O), 온도 27.4℃ 안정:

| 측정 | ΔpH | dKH | 무보정 오차 (vs 8.448) |
|---|-----|-----|---|
| **완전 널 (양쪽 같은 물)** | **−0.003** | **8.387** | **−0.061** |

**−0.92 절대오차의 정체 완전 규명:**
- **−0.86 dKH = 옛 200mL tank 시료 물의 알칼리니티 손실** (6일 개방+반복 폭기로 CaCO₃ 석출/생물막 → 알칼리니티 감소). *증발은 KH를 올리지만(밀폐가 차단), 폭기가 CaCO₃ 과포화를 키워 석출시키는 손실이 더 컸다.*
- **−0.06 dKH = 계측기 순수 시스템 offset** (물 차이 0에서 측정 → ΔpH −3mpH = 분해능/전극 미세 비대칭 수준).

**입증 경로 (부분 널 → 완전 널):**
```
옛 tank 물 (6/20~21):      ΔpH −0.05   dKH 7.4~7.6   오차 −0.9   ← 옛 시료 물 degrade
신선 tank vs 옛 5L (13:00): ΔpH −0.008  dKH 8.298     오차 −0.15  ← tank만 신선으로 교체
완전 널, 양쪽 같은 물(19:00): ΔpH −0.003  dKH 8.387     오차 −0.06  ← 물 차이 0 = 순수 offset
```

**목표 판정 ([README](../README.md) 사양 ±0.07, 사용자 희망 ±0.25 / 허용 ±0.5):**
- 정밀도(흩어짐): SD ±0.08 dKH → 합격
- 계측 offset: −0.06 dKH → ±0.25의 1/4, **영점보정 불요**(보정 가치 없음)
- ⟹ **희망 ±0.25 dKH 달성 확정.** 실제 리프수조의 정상 물이면 무보정 ±0.1 안.

**이를 가능케 한 3대 조건:**
1. **밀폐 공통 헤드스페이스** — ref·tank 같은 pCO₂ 공유(방 CO₂ 공통모드 상쇄) + 증발 차단.
2. **완전평형 측정** — 4시간 상한 + B1 평탄 게이트(span4 AND net8≤1)로 양쪽이 *진짜* 대기평형 천장까지. ⟹ 부피 비대칭(100mL vs 5L)도 완전평형에선 상쇄됨을 실측 확인.
3. **차동식** `KH_tank = 8.448 × 10^(ΔpH)` — 절대 pCO₂가 공통모드로 소거.

상세 시각순 기록은 아래 측정 기록표, 손실 메커니즘은 본 문서 "★석출(CaCO₃) 가설" 섹션 참조.

---

## ★★★ 며칠간 동일시료 완전 널 캠페인 통계 (2026-06-23 05:00 ~ 06-27 05:00, n=13)

6/22 22:00 시료 신선화(대용량 마개 외부챔버 + 해수 보충) 이후, **장치·시료 무변경으로 4일간 1일 3회(05/13/21시) 동일 시료 완전 널**을 연속 측정했다. 참값 = ref 앵커 **8.448 dKH**(같은 물 → 차동식상 출력이 앵커와 같아야 함, 편차 = 순수 계측 오차).

**통계 요약 (n=13, 출력 dKH):**

| 지표 | 값 | 판정 |
|---|-----|---|
| 평균 출력 | **8.318 dKH** | (참값 8.448) |
| **편향 (bias)** | **−0.130 dKH** | \|편향\| ≤ 0.25 → 희망목표 충족 |
| 편향 95% CI | **[−0.167, −0.093]** | **0 미포함 → 편향 실재(통계적 유의)** |
| **정밀도 σ** | **0.061 dKH** | 희망 ±0.25의 1/4 → 우수 |
| RMSE (총오차) | **0.142 dKH** | ±0.25 안 |
| 평균 95% CI | 8.318 ± 0.037 | — |
| **단발 1회 95% 예측구간** | −0.130 ± 0.120 = **[−0.25, −0.01]** | 아무 1회나 95% 확률로 참값 ±0.25 안 |
| ΔpH(tank−ref) 평균 | **−6.7 mpH** (SD 3.1) | ref>tank 계통 = 액간전위/전극 비대칭 |

**핵심 결론:**
1. **−0.13 dKH의 계통 편향이 실재한다** (95% CI가 0을 배제). 6/21 완전 널의 −0.06보다 약 2배 큰 값으로, **"−0.06·영점보정 영구 불요"(6/21 결론)는 이 캠페인으로 갱신됨** — 잔여 baseline이 더 크다.
2. **★온도·KCl은 원인이 아님 (사용자 결론).** 편향 vs 수온 상관계수 **r = −0.10**(≈0, 25.1~27.6℃ 범위 내 무상관)으로 온도 배제가 데이터로도 정합. KCl도 배제됨. ⟹ **남은 유력 원인 = 액간전위/기준전극 비대칭**(ΔpH가 일관되게 tank<ref −6.7mpH인 계통 offset, [project-kh-offset-aeration-test](notes/project-kh-offset-aeration-test.md)의 정적 baseline 항).
3. **그래도 목표는 충족**: 편향 −0.13 + 정밀도 σ 0.06 → RMSE 0.14, 단발 예측구간도 ±0.25 안. 희망 ±0.25 / 허용 ±0.5 모두 합격(영점보정으로 −0.13 제거하면 ±0.06까지 가능하나 운영상 불필요).

**신뢰수준 / 필요 표본수 (널 테스트라 σ 기지):**
- 편향 추정 95% CI = ±1.96σ/√n. **±0.25 보장 n≥1, ±0.1 보장 n≥2, ±0.05 보장 n≥6.**
- 현재 n=13으로 편향은 이미 ±0.037(95%)까지 좁혀짐 → **신뢰수준 확보 목적의 추가 측정 불필요.** 성능은 통계적으로 충분히 특성화됨.
- 정밀도를 더 줄이는 건 횟수가 아니라 물리(전극 드리프트·액간전위) 문제 = 단발 ±0.1 바닥([project-accuracy-target](notes/project-accuracy-target.md) 6/26).

---

## ★★★ calref 실전 재보정 + 올포리프(All-For-Reef) 투입 + 신뢰도 평가 (2026-06-27 21:00 ~ 07-01 13:00)

며칠간 이어진 완전 널 캠페인(위 섹션, n=13, ~6/27 13:00 종료) 직후, 그날 저녁 21:00에 **최초로 라이브 본수조를 대상으로 `calref` 실전 재보정**을 수행 → 이후 "정식 측정"(널테스트가 아닌 실제 수조 dKH 추적) 시작.

**calref 이벤트 (2026-06-27 21:00):** 핸드테스트(사용자 실측) 수조 dKH **7.000** → `--setref 7.000` → 펌웨어 `calref`가 ref dKH 역산·EEPROM 저장: **8.448 → 8.830**. `dkh.dat`: `21 7.886 7.786 8.830 7.000 29.6`. 이 시점부터 `ref_kh` 컬럼이 8.830으로 전환.

**타임라인 (05/13/21시 3회/일 스케줄, 12회 전부 정상측정·에러/미평탄 0건 — dkh.dat 최종 줄이 measure_kh.log의 2026-07-01 13:00 항목과 일치해 8시간 간격 역산으로 날짜 복원):**

| 시각 | 수조 dKH | 온도(℃) | 비고 |
|---|---|---|---|
| 6/27(토) 21:00 | **7.000** | 29.6 | calref 앵커(핸드테스트 실측) |
| 6/28(일) 05:00 | 6.957 | 29.1 | |
| 6/28(일) 13:00 | **6.935** | 29.6 | 최저점 |
| 6/28(일) 21:00 | 6.993 | 29.7 | **올포리프 55mL 투입**(사용자 확인 — 타임라인 정확히 일치) |
| 6/29(월) 05:00 | 7.066 | 28.9 | 회복 시작 |
| 6/29(월) 13:00 | 7.174 | 29.4 | |
| 6/29(월) 21:00 | 7.254 | 29.7 | |
| 6/30(화) 05:00 | 7.281 | 29.3 | 플래토 진입 |
| 6/30(화) 13:00 | 7.281 | 29.6 | |
| 6/30(화) 21:00 | 7.287 | 29.7 | |
| 7/1(수) 05:00 | 7.267 | 29.4 | |
| 7/1(수) 13:00 | 7.282 | 29.9 | 최신(이 기록 시점) |

- **투입 효과:** 최저점 6.935 → 플래토 7.28대까지 **+0.345 dKH**, 상승은 즉발 스파이크가 아니라 ~1.5일에 걸친 완만한 곡선(올포리프 특유의 서방형 반응과 정합).
- **안정성:** 6/30 05:00부터 5회 연속 7.267~7.287 — 하락 저지+안정화 성공.

**정밀도 평가:** 6/30 05:00~7/1 13:00 플래토 5점 SD ≈ **0.008 dKH**(범위 0.020) — 며칠간의 널캠페인이 확립한 단발 잡음바닥 σ0.061([project-accuracy-target](notes/project-accuracy-target.md))보다 훨씬 타이트함. n=5라 새 정밀도로 확정 짓기엔 이르나(σ0.061 자체가 여러 날 표본이라 순수 측정잡음 외 환경드리프트까지 포함해 부풀려졌을 가능성 + 지금은 진짜 평형이라 신호도 안정), 최소 σ0.06 수준은 확실히 지키고 있다는 추가 증거. ⟹ **추세·변화량(하락→투입→회복→평탄 곡선)은 노이즈에 매몰되지 않는 신뢰 가능한 신호.**

**정확도(절대값) 평가 — 한계는 계측기가 아니라 기준측정법 쪽:** 이 시점부터 절대 정확도는 6/27 21:00 calref 앵커(핸드테스트 7.000) 단 1점에 의존. calref가 그 순간의 ΔpH를 새 ref_kh에 흡수시키는 구조라, 며칠간의 캠페인이 찾은 계통편향(−0.13 dKH, 액간전위/전극비대칭)이 상당 부분 상쇄됐을 것으로 추정되나 검증되진 않음(그 편향이 ΔpH 도메인의 진짜 상수라는 가정에 의존). **★사용자 확인(2026-07-01): 시중 리프 KH 테스트킷/체커 자체가 7.28 같은 값을 확정할 만큼 정밀하지 않음.** 추가 핸드테스트로 앵커를 교차검증해도 "대략 7~7.5대"라는 정보 이상은 못 얻음 — **한계가 AquaWiz 쪽이 아니라 가용한 기준측정법(ground truth) 해상도 쪽에 있음**(AquaWiz 재현성 σ0.06~플래토 0.008이 오히려 이 기준측정법들보다 더 좋음). ⟹ 절대값의 마지막 자리(7.28 vs 7.2 vs 7.3)는 이 시스템도 어떤 핸드테스트도 답할 수 없는 질문 — 목표(±0.5 허용/±0.25 희망)가 애초에 이 현실적 해상도 한계에 맞춰 설정된 것([project-accuracy-target](notes/project-accuracy-target.md), 상용 AquaWiz "0.5 이하=excellent·추세용" 기준과 일치, [reference-aquawiz-overseas-cases](notes/reference-aquawiz-overseas-cases.md)). 남은 검증 근거는 외부 교차검증이 아니라 **내부 일관성**(위 타임라인의 매끈한 하락→투입→회복→평탄 곡선 자체) — 순수 노이즈였다면 이런 물리적으로 그럴듯한 곡선이 나오기 어려움.

**밀폐 챔버 온도 정정:** 이 구간 온도 28.9~29.9℃는 dkh.dat 온도컬럼이 **완전 밀폐형 측정챔버 내부에서 평형된 수온**이기 때문(리프위즈 박스 자체가 완전밀폐라 승온, 사용자 확인). 메인 리프탱크의 실제 수온 대리값이 아니며, ref·tank가 같은 온도를 공유해 dKH 계산(차동식)엔 무관함. [project-dkh-temp-column-is-sealed-box](notes/project-dkh-temp-column-is-sealed-box.md)

---

## 코드 버전 정의

| 버전 | git | 활성 기간 | 폭기 | 대상 | STABLE | CONV_EPS | 토폴로지(시퀀스) | 측정후 지속폭기(terminal ron) | 모터 |
|---|-----|---|---|---|---|---|---|---|---|
| **V0** | `74df769` (6/14 19:30) | 6/14 20:12 – 6/15 05:00 | 1200s | 저장수조(5L)+챔버 | 60 | 0.005 | 구-대칭: tank=챔버(m2), ref=5L→측정컵(m4) | **없음** | m1f:80 / m1b:92 |
| **V1** | `cd7602f` (6/15 10:35) | 6/15 13:00 – 6/16 05:00 | 1200s | 저장수조(5L)+챔버 | 60 | 0.005 | 구-대칭(V0와 동일) | **있음**(다음 측정까지 ron 유지) | m1f:80 / m1b:92 |
| **V1b** | (작업트리, ~6/16 정오) | 6/16 13:00 | 1200s | 저장수조(5L)+챔버 | **120** | **0.002** | 구-대칭(V1과 동일) | 있음 | m1f:80 / m1b:92 |
| **V2** | `b5bb839` (6/16) | 6/16 21:21 – 6/17 05:00 | 1200s | **측정챔버(tank)+홀딩챔버(ref) 동시** | 120 | 0.002 | v2: tank=측정챔버 제자리, ref=홀딩→측정챔버(m2f) 이송. 측정 시 airoff(폭기 OFF) 후 측정 | **없음**(제거) | m1f:60 / m1b:72 |
| **V3** | (작업트리, 6/17) | 6/17 13:00 (→V4 대체) | 1200s + ref 재폭기 **300s** | 측정챔버+홀딩 동시 | **0** | 0.002 | v2 + **측정 중 폭기**(tank·ref 둘 다 ron 유지한 채 수렴) + ref 측정챔버 재폭기 + KCl 헹굼 시 **기포 청소**(CLEAN 60s, 정지 중). STABLE=0 | 없음 | 측정 m1f:70/m1b:82(긴 호스 +10s), 헹굼 m1f:60/m1b:72 |
| **V4** | (작업트리, 6/17) | 6/17 V4배포~ | **평형까지 적응**(고정 폭기시간 없음) | 측정챔버+홀딩 동시 | — | **정수 mpH 윈도우 span ≤2mpH**(최근4, 간격30s) | v3 + **진짜 평형(평탄)까지 측정**(measure_until_flat). 판정=최근 4개 정수 milli-pH의 max−min ≤ 2mpH(윈도우 span). [A]tank 평탄까지(ref 홀딩서 co-aeration) [B]ref 평탄까지(co-aeration이라 빨리). 전이 무대기로 조임. **★무한대기 방지**(PHASE_MAX 2400s·MEAS_MAX 80·연속실패 FAIL_MAX 5·시리얼 타임아웃, 미평탄시 마지막값+경고). 오류시 비상정리(_safe_cleanup=에어OFF+배출+KCl소크). | 없음 | 측정 m1f:70/m1b:82, 헹굼 m1f:60/m1b:72 |

- 공통(전 버전): 측정 1회=64샘플×125ms=8초, 포트 COM15(6/15부터), 펌웨어 차동식.
- **★펌웨어 플래시 완료 (2026-06-17 ~20:50, help로 검증):** 트림평균(TRIM_N=16, 중앙32 평균) + seq/air/wait 제거 + roff/toff + stop + help/status 정리. **이제 전위=트림평균.** ⟹ 절대 pH 성격이 또 바뀜(단순평균→트림평균; 버블 스파이크 제거) — 직접 비교 시 유의(ΔpH/dKH는 무영향). 클론 Nano(CH341)라 신 부트로더(arduino:avr:nano)로 업로드, HC-06이 D0/D1 공유라 보드에서 Nano 빼고 단독 플래시(USB).
- **★하드웨어 규칙(사용자 2026-06-17): 액체 이동(mXf/mXb) 직전엔 반드시 airoff.** 펌웨어상 `ron`=에어(D12)·`ton`=PWM(D13) 독립이고 `airoff`만 둘 다 OFF(ino:646,652-653) — 그래서 V3는 폭기를 *액체 정지 구간*(기포 청소·측정)에만 켜고, 모든 모터 앞엔 airoff.
- **V3 검증 포인트 = 폭기 중 수렴 Δ.** V2까지(폭기 OFF 측정)는 연속 Δ=0.0000. 폭기 중에도 Δ≤0.002로 수렴하면 OK, 0.005~0.02로 튀면 버블 노이즈 과함 → 버블률↓/CONV_EPS 완화.
- **V3 측정 중 폭기 → 절대 pH에 흐름(streaming) 오프셋 포함. V2 이전 절대 pH와 직접 비교 금지**(흐름 오프셋은 ref·tank 공통모드라 ΔpH=dKH엔 무영향, 절대값만 이동).
- 근본 변경 요지: V0→V1 지속폭기. V1→V1b 안정화/수렴 조임. V1b→V2 참조수 소량분취 직접폭기. **V2→V3: 측정 중 폭기로 ref·tank를 같은 pCO₂에 핀고정(차동 CO₂ 상쇄) + ref 측정챔버 재폭기로 경로 대칭 + KCl 기포 청소(baseline).**

---

## 측정 기록 (시각순)

| 측정 시각 | 코드 | ref_pH | tank_pH | **ΔpH(t−r)** | tank_dKH | T(℃) | 절대 pH(=방 CO₂ 대리) | 비고 |
|---|---|---|---|---|---|---|---|---|
| 2026-06-14 20:12 | V0 | 7.959 | 8.021 | **+0.062** | 9.741 | 26.7 | ~8.0 | 대칭화 첫 수동 실행 |
| 2026-06-14 21:00 | V0 | 7.997 | 8.072 | **+0.075** | 10.054 | 26.2 | ~8.0 | |
| 2026-06-15 05:00 | V0 | 8.057 | 8.077 | **+0.020** | 8.843 | 26.4 | ~8.07 (CO₂ 낮음=**창문 열어 환기**) | 새벽인데 +부호. **① 사용자 수동 ron(연속폭기)** — V0 코드엔 지속폭기 없으나 수동 제공. **② 그날 창문 열어둠(환기) → 방 CO₂ 낮음 = 절대 pH 높음.** 측정 시퀀스 자체는 V0 그대로 |
| 2026-06-15 13:00 | V1 | 8.050 | 8.042 | **−0.008** | 8.293 | 27.0 | ~8.05 | 지속폭기(V1) 첫 적용, 부호 전환 |
| 2026-06-15 21:00 | V1 | 8.109 | 8.091 | **−0.018** | 8.109 | 27.3 | ~8.10 (CO₂ 낮음) | 지속폭기 깨끗한 검증점 |
| 2026-06-16 05:00 | V1 | 7.810 | 7.751 | **−0.059** | 7.362 | 27.5 | ~7.78 (**CO₂ 높음**) | 새벽 닫힘방 CO₂ 급등, 큰 음 ΔpH |
| 2026-06-16 13:00 | V1b | 8.091 | 8.063 | **−0.028** | 7.922 | 27.7 | ~8.08 | STABLE120·EPS0.002 첫 적용. 낮에 절대pH 회복, ΔpH 음수 유지 |
| 2026-06-16 21:00 | — | — | — | — | — | — | — | **실패**(`0.000`, COM15 세마포): 하드웨어 작업 중 전원 차단 |
| 2026-06-16 21:21 | V2 | 8.042 | 8.021 | **−0.021** | 8.039 | 28.6 | ~8.03 | v2 첫 실측(수동 재실행), baseline 안착 |
| 2026-06-17 05:00 | V2 | 7.997 | 7.939 | **−0.058** | 7.386 | 27.8 | ~7.97 (**CO₂ 높음**) | v2 결정적 검증=실패. 새벽 ΔpH가 V1(−0.059)과 동일 회귀 |
| 2026-06-17 13:00 | V3 | 8.109 | 8.091 | **−0.018** | 8.095 | 28.2 | ~8.10 (낮, 저CO₂) | V3 첫 실측. **폭기 중 수렴 노이즈 작음(읽기당 Δ 0.001~0.003)=측정중 폭기 성립.** 단 **ref 5회·단조상승(8.100→8.109, 평형 미달)=300s 재폭기 부족**(tank 1200s는 2회 Δ0.002 안착). ΔpH −0.018은 낮이라 원래 baseline 수준 — dawn 검정 아님. 절대 pH=폭기 중(흐름 오프셋), V2 이전과 비교 금지 |
| 2026-06-17 21:00 | V4 | 8.113 | 8.071 | **−0.042** | 7.669 | 27.8 | ~8.1 (저녁, 저CO₂) | V4+신펌웨어(트림평균) 첫 풀스택 자동측정. tank 8.026↗8.071 단조상승(24회), ref 8.084↗8.113 단조상승(23회), 둘 다 진짜 평탄 latch(span2). 깨끗. |
| 2026-06-18 05:00 | V4 | 7.738 | 7.695 | **−0.043** | 7.657 | 28.2 | ~7.7 (**새벽, 고CO₂**) | ★**결정적 검증=성공.** tank 7.960**↘**7.695 단조하강(33회, 방CO₂ 천장이 출발pH보다 아래), ref 7.750↘7.738 단조하강(10회, co-aeration 헤드스타트). 둘 다 진짜 평탄 latch(span2), 17:08의 비단조 산모양 없음=측정 중 CO₂ 안정. **ΔpH −0.043이 21:00(−0.042)과 동일 = 절대pH 0.4 스윙(고↔저CO₂)에도 ΔpH 불변 → 완전평형이 방CO₂ 의존성 제거 입증.** 과거 새벽 −0.058/−0.059 → −0.043 개선. |
| 2026-06-18 13:00 | V4 | 8.081 | 8.055 | **−0.026** | 7.950 | 28.3 | ~8.07 (낮, 저CO₂) | tank 7.906↗8.055 단조상승(45회 1729s~29분), ref 8.057↗8.081 단조상승(20회 750s, co-aeration). 둘 다 진짜 평탄 latch(span2), 드리프트·산모양 없음=깨끗한 완전평형. **★완전평형 3번째 점이 baseline 비상수 확인:** 21:00과 같은 저CO₂(절대~8.1)인데 −0.042가 아닌 −0.026 ⟹ ① 점간 변동이 **CO₂ 무관**(V4 핵심 유지·강화) ② 그러나 tank_dKH 7.67/7.66→**7.95(+0.29dKH)** = −0.042는 이전 가능한 장치 상수가 **아님**(영점보류 정당화). 유력 confound=증발 농축(개방200mL 5일째, 한낮 증발 최대→tank KH 실제↑→ΔpH +방향). 단 21:00→05:00 불변·05:00→13:00 계단점프라 증발/드리프트/변동 미구분. |
| 2026-06-19 05:00 | V4+**밀폐** | 7.976 | 7.968 | **−0.008** | 8.283 | 28.1 | ~7.97 (새벽; 밀폐 후 절대pH=박스 pCO₂ 반영, 방CO₂ 아님) | ★★**밀폐(공통 헤드스페이스) 첫 새벽 사이클 = 검증 ① 성공.** tank 7.967↗7.968 **4회·125s 평탄**(span1), ref 7.972↗7.976 **6회·203s 평탄**(span2), 둘 다 단조·진짜 평탄, 경고/타임아웃 없음, 28.1℃(펌프발열 폭주 없음). **(1) 새벽 dip 붕괴:** 3회 재현되던 −0.043~−0.059가 **−0.008**(역대 최소, 낮 baseline 수준) → 방 CO₂ 유입 차단 입증. 절대pH ~7.97로 6/17 새벽(7.97, −0.058)과 같은 수준인데 dip만 소멸=깨끗한 대조. **(2) 평탄 폭발적 단축:** 과거 새벽 33회→4회, 측정 ~50분→~5분 = 헤드스페이스가 5L 버퍼로 핀고정돼 추종 격차 없음 → tank↔ref gap 붕괴 → 17:08식 inter-phase 드리프트 구조적 제거(레버 a+b 동시 달성). **(3) 원시오차 급감:** tank_dKH 8.283 vs 8.448 = **−0.165**(무보정으로 이미 ±0.25 희망범위 안) → −0.78은 증발+불완전평형+CO₂ 아티팩트가 부풀린 값이었을 가능성 → 영점보정 *필요성* 약화. **단 n=1** — 검증 ②(증발 흩어짐↓)는 13:00 밀폐 점, 박스 느린 드리프트는 시계열 필요. 영점/오차 확정은 보류. |
| 2026-06-19 13:00 | V4+**밀폐** | 7.957 | 7.947 | **−0.010** | 8.255 | 28.6 | ~7.95 (낮; 밀폐 박스 pCO₂, 방CO₂ 아님) | ★★**밀폐 검증 ② 성공 = 증발 confound 제거.** tank 7.946↗7.947 **4회·125s 평탄**(span1), ref 7.952↗7.957 **6회·203s 평탄**(span2), 둘 다 단조·진짜 평탄·경고 없음(새벽과 동일하게 빠름). **핵심: 새벽→낮 dKH 점프가 +0.29(개방 6/18) → −0.03(밀폐)로 ~10배 축소.** 6/18 13:00의 +0.29 dKH를 만들던 한낮 증발 농축이 밀폐로 사라짐(05:00 8.283→13:00 8.255, Δ−0.028). 두 밀폐 점(05:00/13:00)이 ΔpH −0.008/−0.010·dKH 8.283/8.255로 타이트 군집(새벽↔낮인데도 거의 동일). 절대pH도 ~7.97→7.95로 거의 불변(개방 0.4 스윙 대비)=헤드스페이스가 5L 버퍼로 핀고정돼 방CO₂ 일주기서 분리. 절대pH 공통모드 ~20mpH 동시하강에도 ΔpH 보존=차동 정확. **⟹ 검증 ①②(CO₂+증발) 모두 충족 → 밀폐 우위 확정.** 남은 systematic offset ~−0.18 dKH(−0.165/−0.193)는 작고(±0.25 안) 안정해 보이나 n=2·동일물/전극 → 21:00·시계열(또는 신선해수 새 널)로 재확인 후 영점보정 결정. |
| 2026-06-19 21:00 | V4+**밀폐** | 7.969 | 7.968 | **−0.001** | 8.421 | 26.8 | ~7.97 (저녁; 밀폐 박스 pCO₂, 방CO₂ 아님) | ★**밀폐 시계열 3번째 점 = offset "완벽 상수 아님, 단 흩어짐 작아 무관" 확정.** tank 7.970↘7.968 **4회·125s 평탄**(span2, 미세 단조하강), ref 7.968↗7.969 **4회·125s 평탄**(span1, 미세 단조상승), 둘 다 진짜 평탄·경고없음(새벽/낮과 동일하게 빠름=핀고정 유지). **(1) ΔpH −0.001 = 측정 분해능(1mpH) 한계 = 사실상 완벽한 널** → dKH 8.421, **원시오차 −0.027(역대 최소, 8.448에 거의 일치).** **(2) ★offset 상수성:** 밀폐 3점 ΔpH −0.008/−0.010/−0.001·dKH 8.283/8.255/**8.421**. 05:00↔13:00 타이트(Δ0.028)했으나 **21:00이 +0.166 위로 점프** → "−0.18 안정 상수" 가설 **반증**, offset은 완벽 상수 아님(±~0.085 dKH 변동). **그러나 세 점 무보정 원시오차 −0.027~−0.193 전부 ±0.25 안**(평균 −0.128, SD~0.073) → **정밀 영점상수 박기 부적절(상수 아님 확인)·무보정으로 목표 충족 → 영점보정 사실상 불요.** [project-accuracy-target](notes/project-accuracy-target.md) 완화기준("±0.25 군집") 충족. **(3) 견고성:** 절대pH 7.95→7.969 거의 불변=헤드스페이스 핀고정 지속. **(4) ★confound = 냉방 과도(사용자 확인): 온도 28.6→26.8℃(−1.8℃)는 펌프발열 안정이 아니라 *너무 더워 냉방기 가동*한 외부 개입.** dKH +0.166 점프와 타이밍 일치 ⟹ 인과 후보. 메커니즘=기존 드리프트 구조의 온도판: **오차 ≈ gap(tank↔ref 측정 시간차) × dT/dt.** 냉방 ON 직후 온도가 능동적으로 떨어지는 중이라 tank(Phase A)·ref(Phase B, ~125s 뒤)가 다른 온도에서 측정→차동이 *정적* 공통모드 온도는 상쇄하나 *측정 중 변하는* 온도 과도는 gap만큼 누출→ΔpH 1mpH·dKH +0.166. ⟹ 밀폐 우위를 깨는 게 아니라 "측정 중 환경 안정 필요"(CO₂든 온도든) 원칙을 온도 축에서 재확인. **offset 변동이 랜덤 전극 드리프트가 아니라 통제 가능한 열 과도라는 신호**(온도 안정 시간대 측정 시 소멸 예상). 온도 안정 후(냉방 정상상태) 재측정이 깨끗한 검정. |
| 2026-06-20 05:00 | V4+**밀폐** | 7.922 | 7.871 | **−0.051** | 7.521 | 27.7 | ~7.9 (새벽; 밀폐 박스 pCO₂) | ★**새벽 dip 재출현 — 단 밀폐 실패가 아니라 tank 미평형 조기 latch 유력.** tank 7.861**↗**7.871 **11회·399s, 11번 연속 단조상승(한 번도 안 꺾임)** = 진짜 평탄 아님(진짜면 노이즈로 왕복해야). ref 7.921↔7.922 **4회·125s 흔들림=진짜 평탄.** ⟹ tank가 ref(7.922) 향해 아직 등반 중이었고 못 채운 ~50mpH가 가짜 dip으로 latch(plateau_analyze가 경고한 "느린 지수 꼬리 조기 latch", span≤2mpH 약점). **6/19(4회·125s, tank 출발 7.967=평형근처)와 차이=이번 tank 출발 7.861(60mpH 아래)→긴 등반 필요.** 냉방으로 박스 식음(28.1→27.7℃)→가스교환 τ 느려짐→399s까지 길어진 것과 정합(차가울수록 CO₂용해도↑·평형 느림). **★냉방 이후 두 점 모두 튐:** 냉방 전 6/19 05/13 타이트(−0.008/−0.010)→냉방 ON 21:00 +0.166→냉방 후 05:00 −0.73, 박스 열정상상태 상실(28→26.8→27.7 진동)이 측정 교란. 단 이번은 측정 중 T=27.7 안정(양 phase 동일)→측정중 dT/dt누출보다 *냉각 후유증*(tank 출발 산성화+느린 kinetics→미평형). **함의: ①밀폐 새벽 검증=1성공(6/19)+1문제(6/20) 혼재, 깨끗한 재현 필요 ②온도 안정화가 1순위 confound ③평탄기준 보강(단조 윈도우 latch 금지=꺾임 요구) 검토.** |
| 2026-06-20 15:00 | V4+**밀폐**+**5L앵커**+**net게이트** | 7.975 | 7.929 | **−0.046** | 7.602 | 27.1~27.4 | ~7.95 (낮; 밀폐 박스 pCO₂) | ★★**5L 능동폭기 앵커 첫 실측 = 기대 미달, 단 net 게이트로 "실제 gap" 확정(미평형/가짜latch 배제).** (실행=15:55:39, 자동 14:35 실행은 `m1b:72`서 **모터1 타임아웃**=튜브 막힘으로 실패→사용자 튜브 점검 후 재실행 정상=기계 문제 해결.) **(1) net 게이트가 의도대로 작동:** tank 7.868↗7.929 **34회·1296s(21.6분) 끝까지 단조상승**, net이 22~33회 3에 묶여 안 멈추다가 34회서 span=1·net=1로 *진짜* 평탄 latch(05:00 11회 조기 latch 의심을 net 게이트가 교정). ref 7.966↗7.975 11회·399s 단조→net=1 latch. **(2) ★핵심: 21분 진짜 평탄까지 갔는데도 ΔpH −0.046 ⟹ 이 음수 dip은 가짜 조기 latch 아티팩트가 아니라 tank·ref 진짜 평형 pH가 46mpH 갈라진 *실제 gap*.** 05:00의 "조기latch 탓?" 가설을 net 게이트가 배제 → dip은 미평형이 아닌 *천장 불일치*가 원인. **(3) 유력 원인=순서 아티팩트(앵커 천장 미확립):** 같은 물·같은 헤드스페이스인데 tank(먼저, 7.929)<ref(나중, 7.975). **앵커(5L 폭기)를 phase A와 *동시에* 켜서** tank 측정 21분 내내 헤드스페이스가 5L pCO₂로 *올라가는 중*(천장 미완성)→tank 낮은 천장 평형. ref(25분 뒤)는 천장 확립 후라 진짜 천장 도달. tank +61mpH 단조등반이 이 그림과 정합. 냉방 27℃가 가스교환 τ↑로 천장 확립을 더 느리게=악화. **(4) 온도는 이번 비원인:** 양 phase 27.1~27.4 안정→측정중 dT/dt 누출 작음. **(5) ★6/20 두 점(05:00 −0.051·7.521, 15:00 −0.046·7.602) 모두 6/19 좋은 군집(8.25~8.42)보다 ~0.7~0.9 dKH 낮음=냉방+앵커 도입 후 일관된 dip.** 원시오차 −0.846(역대 최악급). **함의: ①앵커는 *예비폭기(warmup)* 없이는 효과 없음 — phase A 시작 *전* 수 분 5L 폭기로 천장 먼저 박기(다음 결정 테스트, 예측=tank 등반 급감+ΔpH→0) ②튜브 점검=기계적 성공 ③net 게이트=코드 성공(실제 gap 노출).** |
| 2026-06-20 18:11 | V4+밀폐+**2배폭기**(tank-먼저) | 7.979 | 7.924 | **−0.055** | 7.443 | 26.4 | ~7.95 (저녁) | **2배 폭기 통제실험 ① (구코드, tank 먼저).** tank 7.9↗7.924 **19회·711s** 단조→net=1 평탄, ref 7.975↗7.979 5회·164s 평탄. **★2배 폭기가 tank 등반시간을 15:00 대비 ~절반(1296→711s)으로 단축했으나 ΔpH는 −0.046→−0.055로 안 고침 ⟹ gap은 kinetics(미평형)가 원인 아님.** 빠른 kinetics가 진단을 갈라줌: tank가 더 빨리 진짜 평탄에 가도 ref보다 −0.055 깔림. |
| 2026-06-20 18:57 | V4+밀폐+**2배폭기**+**호스스왑/ref-먼저** | 7.975 | 7.931 | **−0.044** | 7.636 | 26.7 | ~7.95 (저녁) | ★★**결정적 통제실험 ② (신코드: m4=5L→측정챔버, m1=본수조→홀딩, ref 먼저 측정=천장확정+웜업 → tank 나중).** ref 7.972↗7.975 5회·164s 평탄, tank 7.908↗7.931 **20회·750s** 단조→net=1 평탄. 모터·전이·정리 전부 정상 완주. **★판정: ref-먼저(웜업)도 gap 못 고침 — 순서 아티팩트 가설 기각.** ΔpH −0.055→−0.044는 tank-먼저 런 산포(−0.046~−0.055) 안의 변동(의미 없음), tank 등반도 19회·711s→20회·750s로 거의 동일(천장 미리 서 있어도 tank 똑같이 느리게 기어오름). **★★장치 가설 4개 연쇄 기각:** ①kinetics 아님(2배폭기) ②순서/웜업 아님(ref-먼저) ③측정경로(홀딩) 아님(18:11=ref가 홀딩경유, 18:57=tank가 홀딩경유인데 부호 안 뒤집힘=tank가 늘 낮음) ④미평형 아님(18:57 tank가 head-start로 더 높이 7.908 출발했는데도 같은 7.931 안착=다른 출발→같은 도착=진짜 평형). **⟹ 남은 결론=tank·ref 물의 진짜 차이(널 degrade): tank가 같은 pCO₂서 ref보다 낮은 pH=tank 알칼리니티가 더 낮음. 부호상 증발(농축=KH↑) 아님=알칼리니티 손실(6일 200mL 개방 tank의 석출/생물막/분기). raw 오차 −0.81이 이 물 차이.** 다음=★신선 동일 해수 널(ΔpH→0이면 옛물 degrade 확정·계측 정상; 여전히 −0.045면 계통 잔여→영점 검토). |
| 2026-06-20 19:50 | V4+밀폐+2배폭기 (ref-먼저) | 7.975 | 7.926 | **−0.049** | 7.539 | 26.9 | ~7.95 (저녁) | ref-먼저 재현 점. ref 7.971↗7.975 7회, tank 7.912↗7.926 18회 평탄. **gap −0.049 = tank≈7.926/ref≈7.975 패턴 재현(누적 −0.044~−0.055).** 순서·폭기 무관 재확인. |
| 2026-06-20 20:29 | V4+밀폐+**tank-먼저+5L동시폭기+파킹** | 7.977 | 7.921 | **−0.056** | 7.426 | 26.9 | ~7.95 (저녁) | ★**새 흐름(tank 먼저→5L 동시폭기로 ref co-aeration→tank 홀딩 파킹→즉시 ref) 첫 실측.** **(1) 속도 설계 성공:** ref가 **7.976서 출발(이미 천장)→4회·125s 역대 최速**(동시폭기 co-aeration 입증), 전이도 파킹(m2b)+ref직접(m4f)로 단축 → 총 측정 ~절반(950s→485s). **(2) gap −0.056 = 6번째 확증**(누적 −0.044~−0.056, tank≈7.92/ref≈7.98) → 진짜 물 차이 확정적. **(3) ⚠️ tank 10회·360s "반토막"은 진짜 가속 아니라 조기 latch:** tank 평탄값 7.921=역대 최저(이전 7.926~7.931), 같은 슬로우 꼬리인데 4점 net=1이 10회에 위장 latch → dKH 7.426(최저)·gap −0.056(최대)에 기여(물 차이+tank 약간 미평형). ⟹ **B1 적용 결정:** net 룩백 4→8점(span 4점 유지). 20:29 데이터 검증=8점이면 net=8>1로 10회 latch 차단(진짜 평탄까지 계속). measure_kh_once.py 반영·배포 완료. |
| 2026-06-20 21:00 | V4+밀폐+동시폭기+**B1(net8)** | 7.979 | 7.926 | **−0.053** | 7.474 | 27.0 | ~7.95 (저녁) | ★★**B1(net 룩백 4→8) 첫 실측 = 검증 성공 + 물 gap −0.053 확정.** tank 7.913↗7.926 **25회·945s**, ref 7.977↗7.979 9회·320s, 둘 다 span4=0·net8=1 진짜 평탄. **(1) net8 조기 latch 차단 입증:** 10회 시점 `span4:2 net8:5` — span 만족인데 net8>1이라 안 멈춤(20:29이면 여기서 latch), net8 5→4→3→2→25회 1로 줄며 진짜 평탄(22~25회 전부 7.926). **(2) 20:29 tank ~5mpH 미평형 확정:** B1으로 끝까지 가니 **7.921→7.926**(진짜 평형) → 20:29 "10회 반토막"은 가속 아닌 조기 latch였음 입증. **(3) 물 gap ≈ −0.05 (7번째 확증):** tank 미평형 제거한 깨끗한 값 −0.053(dKH 7.474), tank≈7.926/ref≈7.979 둘 다 완전평형 → 순수 물 차이(tank 알칼리니티 < ref). **(4) ref도 B1 따라 9회·320s**(net8 최소 8회 — 예상된 느려짐, 정상). **⚠️ 대가=총 측정 ~21분**(tank 945s가 long pole; 20:29 485s "빠름"은 조기latch 착시). ⟹ **운영 구성 확정=tank-먼저+5L동시폭기+파킹+B1+밀폐. 결정타=신선 동일 해수 널(ΔpH→0이면 옛 tank물 degrade 확정).** |
| 2026-06-21 05:00 | V4+밀폐+동시폭기+B1(net8) | 7.974 | 7.928 | **−0.046** | 7.594 | 26.7 | ~7.95 (새벽; 밀폐 박스 pCO₂) | ★★**B1 새벽 검증 = gap의 8번째 확증 + 시간대 의존성 최종 배제.** tank 7.928 **13회 진짜 평탄**, ref 7.974 **11회·398s span4=0·net8=1 진짜 평탄**, 둘 다 깨끗(경고/타임아웃 없음, 26.7℃). **(1) 어제 새벽(6/20 05:00 −0.051·dKH 7.521)의 tank 11회 조기 latch 의심을 B1이 교정:** 이번엔 tank가 13회까지 *진짜* 평탄에 도달 → −0.046·dKH 7.594. **(2) ★새벽인데 저녁 6점(−0.044~−0.056)과 같은 군집** → 물 gap이 더 이상 시간대(새벽↔저녁)·CO₂·코드구성에 의존하지 않음 = 하루 전체 주기에서 재현. **(3) 7점(6/20 15:00~6/21 05:00) 분산: ΔpH 평균 −0.0499·SD ±0.0048(≈5mpH), dKH 평균 7.531·SD ±0.084·범위 0.21.** 흩어짐은 희망 ±0.25의 1/3 = 정밀도 합격. 남은 건 무보정 절대오차 −0.92(평균 7.53 vs 참 8.448)뿐 → 신선 해수 널이 "물 degrade냐 계통 offset이냐" 결정. |
| 2026-06-21 06:00 | V4+밀폐+**부분널(tank=신선해수, ref=옛5L)** | 7.973 | 7.963 | **−0.010** | (−8.255 미평탄) | 26.7 | ~7.95 (아침) | ★★★**부분 널 = 석출/degrade 가설 강력 지지.** tank 외부챔버수만 처음 분취 신선 해수로 교체(ref 5L는 옛물 유지). **(1) gap 붕괴: tank pH 7.926(옛물)→7.963(신선, +37mpH), ΔpH −0.05 → −0.010.** 옛 tank 물을 신선으로 갈았더니 gap이 0 근처로 무너짐 = 아까 틀의 "ΔpH 0근처/부호반전 → 옛 tank degrade 강력증거" 케이스 적중. **(2) ⚠️ tank 미평형(하한값): tank 63회 X(상한)** = 옛 PHASE_MAX 2400s(40분) cap에 걸려 평탄 미도달(dat −8.255 음수표식, 코드 변경 *전* 측정). tank가 ref(7.973) 향해 아직 등반 중 → **진짜 ΔpH는 −0.010보다 더 0에 가깝다(부호반전 가능).** ref 8회 O 정상 평탄. **(3) ⟹ −0.05 gap의 주범 = 옛 tank 200mL 물의 알칼리니티 손실(석출/생물막) 확정적.** 남은 −0.010은 (a)tank 미평형 잔여(더 줄 것) (b)신선tank↔옛ref(5L) 미세차 (c)소 offset. **(4) ★다음=완전 널(5L ref도 신선 교체)+새 7200s 상한으로 완전평형 → ΔpH→0 기대 = 계측 정확도 최종 결정타.** |
| 2026-06-21 13:00 | V4+밀폐+**부분널(tank=신선)+4h상한** | 7.964 | 7.956 | **−0.008** | 8.298 | 27.2 | ~7.95 (낮) | ★★★**부분 널 완전평형 = degrade 확정 + 정확도 회복 + 4h상한 검증.** tank **46회 O**(양수 dKH 8.298, 06:00의 미평탄 −8.255 표식 사라짐), ref 8회 O, m4b:70 정리 정상. **(1) 4h상한 작동:** 06:00 옛 2400s cap에 `63회 X` 미평탄이던 tank가 새 7200s 여유로 진짜 평탄 도달(이번엔 27.2℃로 따뜻해 ~46회·29분 평형, cap은 안전망). **(2) ★옛 tank 물 degrade 확정 + 정확도 회복:** 신선 tank 완전평형 ΔpH **−0.008**·dKH **8.298**(무보정 오차 −0.15) = 6/19 좋은 군집(−0.008/−0.010/−0.001, dKH 8.28~8.42)에 그대로 복귀. 옛 tank −0.05·dKH 7.4~7.6·오차 −0.9에서 신선으로 갈자 **오차 −0.9→−0.15(±0.25 안)** ⟹ **−0.92 절대오차는 거의 전부 옛 200mL tank 물의 알칼리니티 손실(석출/생물막)이었고 계측 offset 아님 = 좋은 물이면 ±0.25 사실상 달성.** (3) 부호 여전히 살짝 음(tank<ref)=옛 5L ref는 degrade 안 됨(멀쩡). 남은 −0.008=5L↔신선 미세차 또는 분해능(8mpH). **(4) 다음=완전 널(5L도 신선)로 ΔpH→0 최종 확인(선택). 운영상은 실제 리프수조 물이면 이미 ±0.25 OK.** |
| 2026-06-21 19:00 | V4+밀폐+**완전 널**(양쪽=위즈물)+4h상한 | 7.960 | 7.957 | **−0.003** | 8.387 | 27.4 | ~7.95 (저녁) | ★★★★★**완전 널 = 정확도 최종 확정 + 계측 offset 격리.** 위즈(5L) 물을 떠서 tank 외부챔버 100mL에도 넣음 → **양쪽이 같은 물 = 물 차이 구성상 0** = 5L 교체보다 깨끗한 완전 널. tank **21회 O** / ref **18회 O**(둘 다 양수 dKH 진짜 평탄), 온도 27.4 안정, m4b:70 정상. **(1) ΔpH −0.003·dKH 8.387, 무보정 오차 −0.061** = 기대(ΔpH→0, dKH→8.448) 거의 적중. **(2) ★물차이=0이라 나온 −0.061이 *순수 계측 offset의 진짜 값*** (ΔpH로는 −3mpH=분해능/전극 미세 비대칭). ⟹ **−0.92 절대오차 정체 완전 규명: −0.86=옛 tank 물 degrade(석출), 계측 offset은 −0.06뿐. 계측기 멀쩡.** **(3) 부피 비대칭 상쇄 입증:** tank 100mL vs ref 5L인데 둘 다 완전평형(21/18회 O) 도달→ΔpH −0.003 = 평형 원리(부피 무관, [reference-aeration-equilibrium](notes/reference-aeration-equilibrium.md)) 실측 확인, 4h상한·B1이 가능케 함. **(4) ★정확도 목표 판정: 정밀도 SD ±0.08 + 계측 offset −0.06 ⟹ 희망 ±0.25 달성 확정, 영점보정 불요(−0.06은 보정 가치 없음). 실제 리프수조 정상 물이면 무보정 ±0.1 안.** 며칠간 "degrade냐 offset이냐" 모호함 종결. |
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

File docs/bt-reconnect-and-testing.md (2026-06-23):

# 블루투스 통신 안정화 (RF 순단 대응) 및 시뮬레이터 회귀 검증

측정(`bin/measure_kh_once.py`)은 PC ↔ AquaWiz 사이를 **HC-06 블루투스 SPP(가상 시리얼 COM9)** 로
통신한다. 이 링크가 간헐적으로 끊겨 측정이 실패하던 문제와, 그 대응(코드 4계층 + 예방 keepalive),
그리고 하드웨어 없이 검증하는 소켓 시뮬레이터 회귀 테스트를 정리한다.

> 한 줄 요약은 [system-setup.md](system-setup.md#블루투스-통신-안정화--시뮬레이터-검증)에, 사건 기록은
> [measurement-ledger.md](measurement-ledger.md)(6/23 05:00)에 있다.

---

## 1. 문제 — HC-06 SPP RF 순단

- **링크:** COM9 = PC 내장 **인텔 Dual Band Wireless-AC 8265** 의 블루투스 SPP. (USB CSR 동글은 미사용.)
- **증상:** RF 링크가 간헐(버스트)적으로 끊긴다. 펌웨어는 살아있고, **드롭은 대부분 "명령을 보내려는 순간 이미 끊겨 있음"**(통신 도중엔 잘 안 끊김). 재연결하면 금방 붙고 재페어링·COM 번호 변경은 없다.
- **대표 사건(6/23 05:00):** 자동 측정이 첫 `tank` 측정에서 `[START]` 출력 후 통신이 완전히 멎어 실패(`dkh.dat`에 `05 0.000` 에러 표식). 수동 재실행(05:56)은 정상(`dKH 8.427`).
- **원인:** RF 마진 부족(거리) 아님 — 바로 옆에서도 끊김 → **주변 2.4GHz 간섭**으로 추정. HC-06은 ~20초 무통신 시 링크가 끊기는 경향도 있음(유휴 타임아웃).

### 호스트(Windows)측 조치

| 조치 | 이유 |
|---|---|
| **Wi-Fi 어댑터·BT 네트워크 장치 "사용 안 함"** | 유선랜 사용 중. 같은 콤보칩의 Wi-Fi가 미연결이어도 백그라운드 스캔으로 2.4GHz를 점유해 BT를 방해 |
| **USB 선택적 절전 OFF** (`powercfg ... 48e6b7a6... 0`, AC/DC) | 내장 BT도 내부 USB 버스라, 포트 절전 서스펜드가 RF 드롭을 유발 |
| (참고) 내장 BT 라디오 전원관리 | 이미 "절전을 위해 끔" 비활성 상태 |

---

## 2. 대응 — `measure_kh_once.py`의 `send()` 4계층 + keepalive

모든 펌웨어 명령은 `send()`(모터는 `send_motor()`)를 거친다. RF 순단에 대해 다음을 보장한다.

1. **송신 전 연결 확인** — 모든 명령은 보내기 전 `ensure_link()`(부작용 없는 `status` 핑)로 링크 생존을 확인한다. (드롭이 대개 "보낼 때 이미 끊김"이므로 이 단계가 핵심.)
2. **끊겼으면 재연결** — `reconnect()`가 포트를 `close→open` 하여 HC-06 재연결을 유도하고, `status` 응답으로 복구를 확인한다.
3. **보낸 뒤 연결 문제면 재연결 후 재시도** — 송신/수신 예외 또는 응답 미수신(타임아웃)이면 재연결 후 같은 명령을 재시도한다.
4. **재시도 횟수 상한** — `SEND_RETRY_MAX`(기본 3)회까지. 소진하면 기존 백스톱(측정 `FAIL_MAX`·phase 상한·`_safe_cleanup`·에러 래치)이 처리한다.
5. **모터는 재시도 시 먼저 정지(`mNs`) 후 재송신** — 죽은 링크에 미전달됐든 진행 중이든, 정지 명령으로 멈춘 뒤 재송신해 **펌프 중복 구동(과주입/오버플로)을 방지**한다. (측정·계산·솔레노이드는 멱등/읽기전용이라 그냥 재송신해도 안전.)

**예방 — keepalive:** 측정 간격(30초)·모터 동작(60~85초) 등 유휴 구간 동안 `KEEPALIVE_SECS`(12초)마다 빈 줄(`\r\n`, 펌웨어가 조용히 무시)을 보내 링크를 깨워 둔다 → HC-06 ~20초 유휴 타임아웃 드롭을 애초에 줄인다. 그래도 끊기면 위 4계층이 복구한다.

`calkh`·`calref`(`--setref`)는 동일한 `send()`/측정 루프를 타므로 같은 대응이 자동 적용된다.

### 관련 상수 (실전값)

| 상수 | 기본값 | 의미 |
|---|---|---|
| `RECONNECT_TRIES` | 5 | `reconnect()` 1회당 `close→open` 재연결 시도 횟수(진짜 순단은 1~2회면 붙음) |
| `RECONNECT_BACKOFF` | (1,1,2,2,3) | 재연결 시도별 대기(초). 범위 넘으면 마지막값 유지 |
| `SEND_RETRY_MAX` | 3 | `send()` 1회당 재시도 횟수(튜닝 가능) |
| `KEEPALIVE_SECS` | 12 | 유휴 keepalive 간격(초) — HC-06 ~20초 임계 아래 |
| `MEAS_READ_TIMEOUT` | 20 | 측정 1회 `[OK]` 대기 상한(초). 펌웨어 측정 ~8초이므로 20초면 RF 드롭 판정 |
| `LINK_PING_TIMEOUT` | 3 | `ensure_link`/`reconnect`의 `status` 핑 응답 대기 상한(초) |

> 펌웨어는 `m1s`~`m4s` 개별 모터 정지를 지원한다(응답 `[Mn] 정지`).

---

## 3. 시뮬레이터 회귀 검증 (배포 전 필수)

하드웨어 없이 측정 흐름·RF 순단 대응·keepalive·평탄 판정·`calkh`/`calref` 파싱을 상황별로 검증한다.

| 파일 | 역할 |
|---|---|
| `bin/firmware_sim.py` | **소켓 가상 포트 펌웨어 시뮬레이터.** 펌웨어 명령 응답을 충실히 모방. 측정은 상수 pH라 호스트 평탄 판정상 **정확히 8회째 latch**, 모터는 지연 없이 즉시 완료. 펌웨어 상태는 연결을 가로질러 유지(RF 드롭 중에도 살아있는 펌웨어 모사). 드롭/서버 kill/깨진 응답/모터 미완료/먹통 등 예외 주입 가능. 단독 실행(`python3 bin/firmware_sim.py`)으로 수동 접속 테스트도 가능. |
| `bin/test_measure_sim.py` | **통합 회귀 테스트.** 10 시나리오 / 49 검증. |
| `bin/bt_health.py` | (보조) BT 링크 드롭률·RTT 모니터. `--once`(즉석 확인) 또는 연속 로깅. |

### 실행 — WSL, 저장소 안에서

```bash
cd bin && python3 test_measure_sim.py      # WSL python3 + pyserial 3.5 (socket://)
```

> **★규칙: `measure_kh_once.py`(측정·시리얼·RF 순단 로직)나 펌웨어 명령 프로토콜을 바꾸면, 배포
> *전* 항상 이 테스트를 돌려 전부 PASS인지 확인한 뒤 `C:\dkh\work`로 배포한다.** 시뮬레이터·테스트는
> 저장소 `bin/`에만 두고 Windows로 배포하지 않는다.

### 시나리오 (10개 / 49 검증)

| # | 시나리오 | 검증 수 | 확인 내용 |
|---|---|:---:|---|
| 1 | 클린 측정(calkh) | 9 | 전체 흐름·정확히 8회째 평탄·dKH·모터 8종·재연결 0 |
| 2 | 측정 중 드롭(after) | 6 | 송신 전 연결확인이 다음 측정 전 재연결, 정확도 유지 |
| 3 | 모터 응답 중 드롭 | 5 | 재시도 시 `mNs` 정지 후 재송신(순서 `m1f→m1s→m1f`) |
| 4 | calref(`--setref`) | 5 | ref dKH 역산 경로 동일 견고성 |
| 9 | 측정 read 중 드롭(before) | 5 | **send 내부 재시도**로 같은 측정 재송신해 성공(tank 9회=8+재송신1) — 측정의 in-send 재시도 경로 |
| 10 | calref 도중 드롭(setref) | 6 | calref 고유 명령 `setref` 응답 전 드롭 → 재연결+재송신(setref 2회) 후 ref dKH 역산 완주 |
| 5 | 완전 통신 두절(서버 kill) | 3 | `main`이 잡는 예외로 우아하게 종료(크래시·행 없음, 상위가 0.0 기록) |
| 6 | 깨진 응답(pH 누락) | 3 | 파싱 실패 → `FAIL_MAX`로 phase 실패(연결 문제 아님 → 재연결 안 함) |
| 7 | 모터 완료 누락(튜브 막힘) | 3 | 재시도(정지+재송신) 소진 후 미완료 처리 |
| 8 | 버스트(연속 2회 드롭) | 4 | 두 번 재연결하며 완주, 정확도 유지 |

### 배포 안전 — 테스트 타이밍 패치는 in-memory 한정

테스트는 `import measure_kh_once` 후 `mk.MEAS_INTERVAL=0.02`, `mk.FAIL_MAX=2`,
`mk.MEAS_READ_TIMEOUT=0.5`, `mk.LINK_PING_TIMEOUT=0.3` 등으로 **메모리상 모듈만** 패치해 빠르게
돈다. **소스 파일의 실전 상수는 바뀌지 않으므로**(§2 표) 배포본은 정상 동작한다. 이 분리를 위해
매직넘버를 모듈 상수로 빼 두었다(테스트에서 패치 가능하도록).

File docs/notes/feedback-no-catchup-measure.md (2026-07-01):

# feedback-no-catchup-measure

> 밀린(놓친) KH 측정 보충은 불필요 — StartWhenAvailable 추가하지 말 것

---

Measure KH 작업에 **놓친 정시 측정의 보충(catch-up) 기능은 추가하지 않는다.** 사용자가 "밀린 것을 할 필요는 없다"고 명시.

즉 `StartWhenAvailable=true`를 추가하지 말 것. 노트북이 꺼져 있던 시간대의 측정 공백은 그대로 두고, 부팅·로그인 후 다음 정시부터 재개되는 현재 동작이 의도된 정상 상태.

**Why:** KH는 매시간 추세만 보면 되므로, 꺼져 있던 시간의 데이터 포인트를 굳이 메울 필요가 없다고 사용자가 판단.

**How to apply:** 시간별 스케줄 신뢰성 관련 질문/개선 시, catch-up(StartWhenAvailable)은 제안하지 않는다. 현재 트리거(매일 00:00 + PT1H/P1D, 절대 정시 고정)는 재부팅해도 스케줄이 안 깨지므로 그대로 유지. 관련: [project-windows-files](project-windows-files.md)

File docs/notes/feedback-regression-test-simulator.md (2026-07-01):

# feedback-regression-test-simulator

> measure_kh_once.py 등 측정/BT 로직 변경은 배포 전 항상 시뮬레이터(bin/test_measure_sim.py)로 회귀 검증

---

measure_kh_once.py(측정·시리얼·RF 순단 로직) 또는 펌웨어 명령 프로토콜을 바꾸면 **배포 전 항상**
WSL 저장소에서 시뮬레이터 회귀 테스트를 돌려 전부 PASS인지 확인한다(사용자 지시 2026-06-23, "기억해").

**How to apply:**
- 실행: `cd bin && python3 test_measure_sim.py` — **WSL 안, 저장소 bin/ 아래**서만(윈도우로 가지 말 것). pyserial 3.5 + `serial.serial_for_url('socket://…')` 사용.
- 전부 PASS여야 `cp bin/measure_kh_once.py /mnt/c/dkh/work/`로 배포.
- 도구 2종(저장소 bin/에만, 윈도우 배포 안 함):
  - `firmware_sim.py` — 소켓 가상 포트 펌웨어 시뮬레이터. 펌웨어 명령 충실 모방, 측정은 상수 pH라 정확히 8회째 평탄 latch, 모터 즉시 완료. 펌웨어 상태가 연결을 가로질러 유지(RF 드롭 모사). 드롭/kill/garble/no_done/hang 예외 주입 가능. 단독 실행 `python3 bin/firmware_sim.py`로 수동 접속 테스트도 됨.
  - `test_measure_sim.py` — **총 12 시나리오 / 58 검증, 전부 PASS여야 함**:
    정상/회복 6(36 검증)=클린 calkh(9)·측정중 드롭after(6)·모터 재시도 정지(5)·calref(5)·측정 in-send 재시도before(5)·calref 드롭(6);
    예외 6(22 검증)=완전두절 kill(3)·깨진응답 pH누락(3)·모터 미완료(3)·버스트 회복(4)·setref 예외(4)·모터정지 명령 드롭(5).

**★배포 안전(중요):** 테스트는 `import measure_kh_once` 후 `mk.MEAS_INTERVAL=0.02`, `mk.FAIL_MAX=2`,
`mk.MEAS_READ_TIMEOUT=0.5`, `mk.LINK_PING_TIMEOUT=0.3` 등으로 **메모리상 모듈만** 패치해 빠르게 돈다.
**소스 파일의 실전 상수는 안 바뀐다**(MEAS_INTERVAL=30·FAIL_MAX=5·MEAS_READ_TIMEOUT=20·
LINK_PING_TIMEOUT=3·RECONNECT_TRIES=5·SEND_RETRY_MAX=3·KEEPALIVE_SECS=12). 그래서 배포본은 정상 동작.
이 분리를 위해 매직넘버를 모듈 상수로 빼 둠(테스트에서 패치 가능하게).

**Why:** RF 순단 대응(연결확인→재연결→재시도→모터정지)·keepalive를 하드웨어 없이 상황별로 검증.
이미 실버그(수신 중 예외 미처리)와 단언 오류를 잡아냄. 관련: [project-measure-kh-script](project-measure-kh-script.md) [project-kh-v4-firmware-state](project-kh-v4-firmware-state.md)

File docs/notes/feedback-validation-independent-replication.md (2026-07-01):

# feedback-validation-independent-replication

> "보정(영점 등) 적용 전, 비독립 소표본을 독립 재현으로 검증 — 일정 vs 우연을 먼저 가른다"

---

측정 baseline/오프셋을 보정(예: ΔpH 영점보정)으로 코드·펌웨어·서버에 박기 전에, 그 값이 **재현되는 상수**인지 **우연**인지 독립 재현으로 먼저 가른다.

**Why:** 6/18 V4에서 21:00·05:00 ΔpH가 −0.042/−0.043으로 일치 → CO₂ 불변성은 강하게 입증됐으나, 두 점은 **같은 물·증발 상태·전극 상태**를 공유한 통제실험(CO₂만 바꿈)이라 baseline *값*의 독립 표본은 사실상 n=1. 게다가 4일 된 개방 200mL 챔버는 증발 농축으로 ΔKH=0 전제가 흔들리는 confound. 이런 데이터에 영점보정을 박으면 (우연일 때) 오히려 망친다. 내가 "즉시 영점보정"을 권했으나 사용자가 정당하게 보류시킴.

**How to apply:** ① 통제실험에서 "한 변수만 바꿈"이 증명하는 것(예: CO₂ 불변성)과 못 하는 것(예: 절대값의 이전 가능성)을 분리해서 말한다 — n이 많아 보여도 비독립이면 effective n은 작다. ② 보정값을 박기 전 **독립 재현**(동일 조건 신선 시료의 새 측정)으로 같은 값이 나오는지 + 시계열 누적이 타이트 군집(낮은 SD·추세 없음)인지 확인. ③ 노화·증발 등 전제 붕괴 confound를 항상 점검. 관련 [feedback-one-change-at-a-time](feedback-one-change-at-a-time.md) [project-kh-v4-firmware-state](project-kh-v4-firmware-state.md)

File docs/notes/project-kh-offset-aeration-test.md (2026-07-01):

# project-kh-offset-aeration-test

> "KH 널테스트 ΔpH 오프셋 튜닝. 현 가설=부피·시간상수 비대칭(5L ref가 느려 새벽 방CO₂ 과도 추종 못 함; 6/16 05:00 오차 −1.09dKH, 고-CO₂평형=낮은pH라 tank가 평형·ref가 lag). 6/16 STABLE_SECS 60→120·CONV_EPS 0.005→0.002 동시변경, 다음 검정=13:00. 미실행=ron제거 대칭널테스트, 정공법=참조수 소부피화"

---

**진단 중인 현상 (2026-06-14):** 참조수·수조수가 **동일 해수**(외부 수조수 대응=외기노출 300 mL, 참조수=AquaWiz 탱크 거의 밀폐)인데도 측정 시 **tank pH > ref pH** 로 ΔpH 오프셋이 나옴. 펌웨어 dKH는 차동식(ΔpH→dKH, ref 8.448 앵커, [project-firmware-kh-calc](project-firmware-kh-calc.md))이라 이 오프셋이 가짜 dKH 차이로 증폭됨. 이상적으론 ΔpH=0이어야 함.

**관측 데이터 (커밋 9b333e2 대칭화 시퀀스, [project-symmetric-kh-redesign](project-symmetric-kh-redesign.md)):**
| 시각 | ref pH | tank pH | ΔpH(tank−ref) | tank dKH | temp | 수렴 |
|---|---|---|---|---|---|---|
| 20:00 (수동 테스트) | 7.959 | 8.021 | +0.062 | 9.741 | 26.7 | tank2/ref2, Δ≈0 |
| 21:00 (정규) | 7.997 | 8.072 | +0.075 | 10.054 | 26.2 | tank2/ref2, Δ≈0 |
| **05:00 (8h 폭기 후)** | **8.057** | **8.077** | **+0.020** | **8.843** | 26.4 | tank2/ref2, Δ=0 |
| **13:00 (지속폭기 후)** | **8.050** | **8.042** | **−0.008** | **8.293** | 27.0 | tank2/ref2, Δ=0 |
| **21:00 (ron 깨끗한 검증점)** | **8.109** | **8.091** | **−0.018** | **8.109** | 27.3 | tank2/ref2, Δ=0.001 |
| **6/16 05:00 (무변경)** | **7.810** | **7.751** | **−0.059** | **7.362** | 27.5 | tank2(Δ0)/ref2(Δ0.001) |

**6/16 05:00 분석 — 정정: "지수 수렴" 아님, regime 전환 + 공통모드 CO₂ 누출:** 6/15 21:00→6/16 05:00에 ΔpH(tank−ref) −0.018→**−0.059**(오차 −0.34→**−1.09 dKH**)로 *가속 악화*. 결정적: **절대 pH가 둘 다 ~0.3 급락**(ref 8.109→7.810 −0.30, tank 8.091→7.751 −0.34, 직전 며칠 상승추세 반전) = 공통모드 = **폭기 방 공기 CO₂가 밤사이 급등**(새벽 밀폐+호흡 → 실내 CO₂ 피크 → 폭기수 산성화, 온도 +0.2°C는 이 크기 불가). **공통모드인데 ΔpH로 새어 들어옴**: tank가 ref보다 0.041 더 떨어짐(−0.34 vs −0.30) = ΔpH 확대분(−0.018→−0.059, Δ−0.041)과 정확히 일치.

**[중요 방향 정정, 2026-06-16 사용자 지적]:** 어느 쪽이 평형(포화)인지 내가 거꾸로 봤었음. **고-CO₂ 공기와 평형 = 낮은 pH**이므로, 새벽 방 CO₂ 급등 시 **더 낮은 pH(tank 7.751)가 평형 도달, 더 높은 pH(ref 7.810)가 미평형(lag)**. 접근 방향: 직전 며칠 ~8.0~8.1(낮 저-CO₂ 평형) → 새벽 평형 pH ~7.75로 하강 → 두 물이 위에서 아래로 CO₂ 흡수하며 접근. **tank(소량 챔버, 짧은 시간상수)=빨리 7.75 도착, ref(5L, 긴 시간상수)=움직이는 평형 추종 못 하고 위에 처짐.** ⟹ ΔpH −0.059는 tank 결함이 아니라 **ref(5L)의 지연**. **이전 "ron이 ref를 실시간 추종/완전평형"·"ron 과보정으로 tank 미평형" 프레이밍 철회 — 5L는 부피 율속이라 절대 실시간 추종 못 함(메모리 스스로 8h 잔차 0.020). 진짜 원인 = 부피·시간상수 비대칭(작은 tank 빠름 vs 큰 ref 느림)** → 과도구간에 벌어짐. 정적 접합 아티팩트는 약화(0.3 공통급락과 동기 안 되므로). **함의: 소부피화(~150mL)가 더 강하게 정당화** — 참조수 시간상수를 tank와 맞추면 방 CO₂ 흔들려도 동반 이동해 ΔpH≈0 유지. **이전 사례 검증(2026-06-16, dkh.dat 6점):** "tank=평형, ref=지연" 직접 증거 = **D1 21:00→D2 05:00 8h 연속폭기 개입에 ref +0.060 크게 이동 vs tank +0.005 사실상 정지** = tank가 평형 천장에 닿아 추가폭기 무반응(평형 도달 증거), ref만 끌려 올라옴. 통일원리=tank는 방공기 평형의 빠른 추종자/ref(5L)는 느린 지연. 구간별 "누가 더 움직이나"는 교란 성격차(ref결손 이완 시 ref이동 / 평형 자체 이동 시 tank가 더 이동: #3→4 tank−0.035 vs ref−0.007, #5→6 tank−0.340 vs ref−0.299)이지 모순 아님. 한계=대칭데이터 6점뿐·방CO₂ 독립로그 없음(새벽급등은 추론). **이전 "지수적 정상상태 수렴" 프레이밍 철회** — 13:00 부근 |오차| 최저(0.16) 찍고 부호 뒤집혀 다시 벌어진 = 서로 다른 두 오차의 교대. 일주기 예측: 오후 13:00에 방 CO₂ 내려가면 |ΔpH| 다시 축소 기대.

**변경 적용 (2026-06-16, measure_kh_once.py bin+Windows, loop 무변경) — 안정성 2변수 동시 조정:** ①`STABLE_SECS` 60→**120**(채움 후 안정화, 제품 스펙 응답시간 최대 2분 근거), ②`CONV_EPS` 0.005→**0.002**(수렴 슬랙 ≈0.1→0.04 dKH). 사용자 의사로 동시 변경 — **두 변수는 "전극이 충분히 안착·평형된 값만 채택"하는 동일 인과 축(안정성/응답완성도, 메모리 가설3)**을 다른 지점에서 거는 손잡이라 한 묶음(같은 성격)으로 취급 정당, 폭기/CO₂(`ron`·`AIR_SECS`)·경로/접합(헹굼·KCl) 등 다른 축과 분리됨. STABLE=샘플링 전 고정대기(응답꼬리), CONV_EPS=측정 후 채택문턱. 서로 보강(같은 방향), 안 싸움. ⟹ **결과 개선 시 "안정화/응답완성도" 요인으로 귀속, 두 숫자 분리 불필요.** (※이전에 내가 "두 변수 분리 안 됨"이라 경고한 건 과함 — 같은 메커니즘 검정이라 OK.) AIR_SECS·CONV_INTERVAL(45)·CONV_MAX(6)·ron 무변경. 다음 검정점 = 13:00 결과.

**CONV_EPS 실측 분석 (2026-06-16, 재설계 6/14 20:12 이후 12회 로그):** 실제 수렴 Δ(연속측정 pH차) = **0.0000 ×8 / 0.0010 ×4, 최대 0.0010, 전부 2회 수렴**(3회 이상 0건). ⟹ **기존 0.005는 실측 최악 Δ의 5배라 한 번도 안 물림** = 수렴판정이 사실상 "무조건 2회 통과", 채택값이 평형서 최대 ~0.005pH(≈0.1dKH) 벗어나도 합격 가능했음. pH는 **0.001 단위 양자화**(보고 3자리) → Δ는 0.000/0.001/0.002…만 가능 → 새 0.002 = "연속 2값 ≤0.001(1 LSB) 이내" 강제. 역사적 최악 0.0010 대비 **2배 여유라 여전히 2회 수렴 정상 예상**, 단 여유 1 LSB뿐이라 가끔 Δ=0.002 런은 3회째 측정(정상 동작=타이트해진 효과). 결론: 실측 정밀도는 이미 ≤0.001로 충분히 타이트, 0.005는 느슨한 상한이라 무용 → 0.002가 그 실측 정밀도를 강제(수렴비용 거의 불변, 평형보장 0.1→0.04dKH).

**추세 분석 (2026-06-15 21:00 갱신, ※6/16 05:00에 "지수 수렴" 철회됨 — 위 6/16 분석 참조) — 정상상태 미도달, 단 지수적 수렴 중:** 재설계(6/14 20:12) 이후 ΔpH(tank−ref) 단조 하강 +0.075→+0.020→−0.008→−0.018, dKH 단조 하강 10.054→8.843→8.293→**8.109**. **핵심: 8h당 변화량이 감속(반감) 중** — ΔpH 델타 −0.055→−0.028→−0.010, dKH 델타 −1.21→−0.55→−0.18. 발산 아닌 **지수적 정상상태 접근**(참조수 폭기평형 이완이 안착 중, [reference-aeration-equilibrium](reference-aeration-equilibrium.md)). 실수조 KH가 하루새 변할 리 없으니 이 변동=참조-수조 상대 오프셋의 느린 이완이지 진짜 KH 변화 아님. 21:00은 ron 코드의 깨끗한 검증점(13:40~21:00 지속폭기)으로, 예측대로 평형 쪽 이동 확인됨. **판정: 폭기시간 요인 효과는 아직 단정 불가(추세 미평탄). 다음 05:00·13:00에서 ΔpH 델타<0.005로 평탄화되면 그 dKH를 기준선 확정 후 다음 요인(헹굼 제거)로 진행. 계속 음으로 커지면(감속 안 멈춤) 참조수 소부피화 앞당겨 검토.** [feedback-one-change-at-a-time](feedback-one-change-at-a-time.md)

**결론 (2026-06-15 05:00) — 폭기 부족 가설 확정:** 8h 연속 폭기로 ΔpH +0.075→+0.020 (~73%↓). **결정적: 격차가 참조수가 올라와서 닫힘** (ref 7.997→8.057 +0.060 급상승, tank 8.072→8.077 거의 정지) = 밀폐로 덜 탈기됐던 참조수가 폭기로 CO₂ 빠지며 tank 따라잡음. 가설 예측 메커니즘 그대로. tank dKH 10.054→8.843(앵커 8.448 근접). → **ΔpH 오프셋 지배원인 = 참조수(밀폐) 폭기 부족 = CO₂ 탈기 비대칭.** (KCl 기각이 옳았음 — KCl이면 ref 상승 설명 불가.)

**헹굼 제거 & STABLE/시간차 트레이드오프 (2026-06-15):** ref 헹굼=m4f60+m4b68=**128초**, 목적 ①carryover 방지 ②부피대칭(사용자: "같은 수량으로 헹굼"). 동일성분 널테스트선 carryover(알칼리도) 무해→①소멸→제거후보. 단 CO2/희석 이월·**헹굼방식 비대칭(tank=KCl스윕 / ref=참조수)**은 남을 수 있어 제거결과가 진단정보. 검정=헹굼 유/무 ΔpH비교(불변→제거정당). **정상운영(성분다름) 복귀 시 헹굼 필수**(carryover)—널테스트 한정 제거·양쪽 대칭. STABLE 60→120: 시간차 +60초(드리프트 누출 +0.003dKH=무시) vs 응답꼬리 개선(잠재 0.1+)→순이득. **헹굼 제거로 번 128초를 STABLE에 재배분하면 tank↔ref 간격 316→248초로 오히려 단축**하며 평형 확보(사용자 시간차 우려 해소).

**실험 계획 (사용자 지시 2026-06-15) — 한 번에 하나씩:** 지금은 **아무것도 변경 안 함**(현 코드 유지). 다음 갈림길 = **21:00 측정에서 ΔpH 변동(안정/표류) 관찰**. 이후 요인을 차근차근 **한 번에 하나만** 바꿔 각각 ΔpH 효과 측정: ①수조수(tank) 폭기시간 ②헹굼 제거(널테스트 한정·양쪽 대칭, 정상운영 복귀 시 복원 필수) ③`STABLE_SECS` 120 ④`CONV_EPS` 0.002. 동시변경 금지. [feedback-one-change-at-a-time](feedback-one-change-at-a-time.md)

**[중요] 현재 운영=널테스트 (사용자 확인 2026-06-15):** ref·tank가 **동일 성분 해수** → 진짜 알칼리도차=0 → **정답 ΔpH=0/dKH=8.448 확정 → 0.155는 전부 시스템 오차(진짜 KH차 아님, "진짜차일수도" 가능성 철회)**. 함의 ①**영점보정 정당성 확보** — 정답을 아니 잔차가 안정적 상수면 ΔpH 가산보정 정당(전제=재현성, 21:00 등 확인). ②남은 진단=오차의 정체만: **CO2 폭기비대칭**(ΔpH가 폭기따라 −0.062→+0.008 크게 변함=주원인) vs **경로·접합·응답**(KCl잔막/헹굼차/응답꼬리, 잔여분). 단 현재 ref(지속폭기)/tank(측정직전20분) 폭기상태 비대칭이라 0.155에 CO2성분 섞임 — 순수 경로/접합 바닥은 **양쪽 동일 충분폭기**(검정A)로 재야. 개선경로: 물리적 대칭화(검정A 폭기동일·검정B 순서·STABLE↑)로 ΔpH→0 밀고 + 남는 안정잔차는 영점보정(+CONV_EPS↓ 슬랙축소). 개선대상 실재 확정.

**13:00 결과 (2026-06-15) — 부호 전환(통과):** ΔpH(tank−ref)가 +0.020→**−0.008**로 0을 넘어 **반대편**으로. tank dKH도 앵커보다 처음으로 **낮아짐**(8.293, |오차|0.155). 즉 ref 폭기부족(ref 낮음→dKH과대) 문제는 해소를 넘어 **tank<ref**가 됨. 같은 방 공기로 ref·tank 둘 다 평형 도달했다면 남는 ΔpH는 순수 KH차(수조 KH가 참조수보다 미세히 낮음)+전극노이즈(±0.005~0.01). 0.008은 노이즈 바닥 수준이라 "오차"라기보다 평형 안착. **"과폭기로 틀어졌다"는 잘못된 해석 — 폭기는 평형이 상한이라 과폭기로 pH가 더 안 오름**([reference-aeration-equilibrium](reference-aeration-equilibrium.md)). 사용자 판단기준(|오차|≤0.1→5L유지)은 0.155로 약간 초과지만, 메커니즘이 "정체"가 아닌 "통과"라 단순적용 부적합 — 21:00로 재현/안정성 확인.

**폭기시간 30→20분 단축 (2026-06-14 20:12, 대칭화와 동시):** 로그상 ~6/13까지 1800초(30분)+비대칭(ref==tank 단일기록, ΔpH 없음), 6/14 20:12부터 1200초(20분)+대칭(ref/tank 분리). **두 변경이 겹쳐 30 vs 20을 ΔpH/dKH로 직접 비교 불가(교란).** 영향 다각도: ①정확도 영향 거의 0 — 5L는 부피가 율속이라 10분 차이 무의미(8h에도 잔차 0.020), 진짜 평형도구는 측정사이 지속폭기(ron) 누적. ②tank 시료(챔버 소량)는 20분이면 충분 평형. ③얻은 것=측정 10분 단축·증발/온도 안정. ④취약성=지속폭기 끊기면 직전 폭기로 평형 맞춰야 하나 5L엔 20·30분 둘 다 부족이라 30분도 실효 방어 못 됨 → 근본해법은 폭기시간이 아니라 참조수 ~150mL 소부피화(20분 1회 완전평형, 지속폭기·증발 문제 동시 소멸, 메모리 위 38번대 권고와 일치).
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

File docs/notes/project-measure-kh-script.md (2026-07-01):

# project-measure-kh-script

> "KH 측정 파이썬 스크립트 — once(V4 본 측정)/test 진단, dkh.dat 기록, Windows COM 포트(블루투스 재페어링 시 바뀜, 2026-06-20 현재 COM9). measure_kh_loop.py는 2026-06-22 삭제(미사용)"

---

KH 측정 스크립트 (모두 `bin/`):

**⚠️ COM 포트는 블루투스 페어링에 묶임.** 한 번 연결되면 포트는 **계속 유지**되고, 장치를 **삭제(제거)한 뒤 다시 연결할 때만** 번호가 바뀜(매 연결마다 바뀌는 게 아님). 재페어링했으면 실제 포트 확인 후 스크립트 `PORT` 갱신 필요. (2026-06-14: COM15였음 → **2026-06-20 재페어링으로 COM9.** 스크립트 기본 `PORT`도 COM9로 갱신됨.)

| 파일 | 동작 | 기록 |
|---|---|---|
| `measure_kh_once.py` | **V4 본 측정** — 1회 실행 후 종료(스케줄러 정시용). 인자 없으면 calkh, `--setref <수조dKH>`면 calref(ref dKH 역산·저장, dkh.dat 미기록). 자세히 [project-kh-v4-firmware-state](project-kh-v4-firmware-state.md) | dkh.dat ✓ (calref 제외) |
| `test_aeration_plateau.py` / `test_aeration_plateau_ref.py` | 평형곡선 진단(V4 평탄 기준) | 없음 |
| `test_pump.py` | 펌프/배관 시험용 순서 1회 | 없음, 화면 출력만 |

**★2026-06-22 `measure_kh_loop.py` 삭제** (repo + `C:\dkh\work` + 문서). 전혀 사용 안 함(once+스케줄러로 대체). 구 방식=매 정시 무한 반복·고정 폭기시간.
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

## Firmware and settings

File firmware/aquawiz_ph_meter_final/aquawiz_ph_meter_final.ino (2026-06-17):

/*
 * AquaWiz - pH/dKH 측정 시스템 (탄산염 화학법)
 * KH_tank = KH_ref x 10^(-DeltapH), DeltapH = pH_ref - pH_tank
 * EEPROM: 0x00-0x07 DFRobot_PH, 0x10 refDKH, 0x14 tempOffset, 0x18 calTemp
 */

#include "DFRobot_PH.h"
#include <EEPROM.h>
#include <Adafruit_ADS1X15.h>
#include <OneWire.h>
#include <DallasTemperature.h>

// ============================================================
// 핀 정의
// HC-06: 하드웨어 Serial (D0=RX, D1=TX) 직접 연결
// 업로드 시 HC-06 분리 필요
// ============================================================
#define ONE_WIRE_BUS  14
#define M1_IN1        4
#define M1_IN2        5
#define M2_IN3        6
#define M2_IN4        7
#define M3_IN1        8
#define M3_IN2        9
#define M4_IN3        10
#define M4_IN4        11
#define SOL_REF       12
#define SOL_TANK      13

// ============================================================
// EEPROM 주소
// ============================================================
#define REF_DKH_ADDR      0x10
#define TEMP_OFFSET_ADDR  0x14
#define CAL_TEMP_ADDR     0x18

// ============================================================
// 시퀀스/이력 설정
// ============================================================
#define SEQ_CMD_LEN    24
#define CMD_BUF_SIZE   128
#define KH_HIST_MAX    5
#define KH_TIME_LEN    4

// ============================================================
// BTPRINT 매크로 (Serial = 하드웨어 Serial = HC-06)
// ============================================================
#define BTPRINT(x)       Serial.print(x)
#define BTPRINTLN(x)     Serial.println(x)
#define BTPRINTF(x)      Serial.print(F(x))
#define BTPRINTLNF(x)    Serial.println(F(x))
#define BTPRINTFD(v,d)   Serial.print(v,d)
#define BTPRINTLNFD(v,d) Serial.println(v,d)

// ============================================================
// 구조체
// ============================================================
struct KHRecord {
    char  timestamp[KH_TIME_LEN];
    float dkh;
    bool  valid;
};

struct DateTime {
    int           hour;
    bool          valid;
    unsigned long setMillis;
};

struct MotorTimer {
    bool          active;
    int           pinA, pinB;
    unsigned long endTime;
};



// ============================================================
// 객체 선언
// ============================================================
OneWire           oneWire(ONE_WIRE_BUS);
DallasTemperature sensors(&oneWire);
Adafruit_ADS1115  ads;
DFRobot_PH        ph;

// ============================================================
// 오버샘플링
// ============================================================
const int           SAMPLE_N        = 64;
const int           TRIM_N          = 16;   // 트림 평균: 정렬 후 상·하위 각 TRIM_N개 버림(버블 스파이크 제거). 0이면 단순 평균
const unsigned long SAMPLE_INTERVAL = 125;

// ============================================================
// 전역 변수
// ============================================================
int           sampleCount    = 0;
float         sampleSum      = 0.0;       // (트림 평균으로 대체 — 리셋 호환 위해 유지)
int16_t       sampleBuf[SAMPLE_N];        // 트림 평균용 raw 샘플 버퍼 (int16×64 = 128 B)
unsigned long lastSampleTime = 0;
bool          voltageReady   = false;

float voltage     = 0.0;
float phValue     = 0.0;
float temperature = 25.0;
float tempOffset  = 0.0;
float calTemp     = 25.0;
float refDKH      = 0.0;
float refPH       = 0.0;
float tankPH      = 0.0;
float deltaPH     = 0.0;
float tankDKH     = 0.0;

bool refMeasDone  = false;
bool tankMeasDone = false;

enum MeasureMode { MODE_IDLE, MODE_TANK, MODE_REF, MODE_CALIBRATION };
MeasureMode currentMode = MODE_IDLE;

KHRecord  khHist[KH_HIST_MAX];
int       khHistHead  = 0;
int       khHistCount = 0;

DateTime   currentTime;
MotorTimer motorTimers[4];
bool       phCalMode = false;
bool       calphPending = false;

// ============================================================
// Nernst 온도 보상
// ============================================================
float nernstPH(float phRaw, float tempC) {
    return 7.0 + (phRaw - 7.0) * (273.15 + calTemp) / (273.15 + tempC);
}

// ============================================================
// 현재 시각 문자열
// ============================================================
void getTimeStr(char* buf) {
    if (!currentTime.valid) {
        strcpy(buf, "??");
        return;
    }
    unsigned long elapsed = (millis() - currentTime.setMillis) / 3600000UL; // 경과 시간(시)
    int h = (currentTime.hour + (int)(elapsed % 24)) % 24;
    snprintf(buf, KH_TIME_LEN, "%02d", h);
}

// ============================================================
// dKH 이력
// ============================================================
void saveKHRecord(float dkh) {
    KHRecord &r = khHist[khHistHead];
    getTimeStr(r.timestamp);
    r.dkh   = dkh;
    r.valid = true;
    khHistHead = (khHistHead + 1) % KH_HIST_MAX;
    if (khHistCount < KH_HIST_MAX) khHistCount++;
}

void printKHHist() {
    if (khHistCount == 0) { BTPRINTLNF("[KH이력] 없음"); return; }
    BTPRINTF("[KH이력] "); BTPRINT(khHistCount); BTPRINTLNF("개");
    for (int i = 0; i < khHistCount; i++) {
        int idx = ((khHistHead - 1 - i) % KH_HIST_MAX + KH_HIST_MAX) % KH_HIST_MAX;
        KHRecord &r = khHist[idx];
        if (!r.valid) continue;
        char dkhStr[8];
        dtostrf(r.dkh, 6, 3, dkhStr);
        char buf[20];
        snprintf(buf, sizeof(buf), "%2d  %s  %s", i+1, r.timestamp, dkhStr);
        BTPRINTLN(buf);
    }
}

// ============================================================
// 초기화
// ============================================================
void setup() {
    Serial.begin(9600);  // HC-06 기본 보드레이트
    BTPRINTLNF("=== AquaWiz v3.0 ===");

    sensors.begin();
    if (sensors.getDeviceCount() == 0) BTPRINTLNF("[WARN] DS18B20 없음!");
    else                               BTPRINTLNF("[OK] DS18B20");

    if (!ads.begin()) { BTPRINTLNF("[ERR] ADS1115 실패!"); while(1){delay(1000);} }
    ads.setGain(GAIN_ONE);
    ads.setDataRate(RATE_ADS1115_8SPS);
    BTPRINTLNF("[OK] ADS1115");

    ph.begin();
    BTPRINTLNF("[OK] pH lib");

    EEPROM.get(REF_DKH_ADDR, refDKH);
    if (isnan(refDKH) || refDKH < 0.5 || refDKH > 30.0) {
        refDKH = 0.0; BTPRINTLNF("[WARN] refDKH 없음 → setref:xx.x");
    } else { BTPRINTF("[OK] refDKH: "); BTPRINTFD(refDKH,3); BTPRINTLNF(" dKH"); }

    EEPROM.get(TEMP_OFFSET_ADDR, tempOffset);
    if (isnan(tempOffset) || tempOffset < -10.0 || tempOffset > 10.0) {
        tempOffset = 0.0; BTPRINTLNF("[OK] 온도오프셋: 0.0");
    } else { BTPRINTF("[OK] 온도오프셋: "); BTPRINTFD(tempOffset,2); BTPRINTLNF(" C"); }

    EEPROM.get(CAL_TEMP_ADDR, calTemp);
    if (isnan(calTemp) || calTemp < 0.0 || calTemp > 50.0) {
        calTemp = 25.0; BTPRINTLNF("[OK] 보정온도: 25.0C (기본)");
    } else { BTPRINTF("[OK] 보정온도: "); BTPRINTFD(calTemp,1); BTPRINTLNF("C"); }

    BTPRINTLNF("[INFO] ref 매번 측정 필요");

    int pins[] = {M1_IN1, M1_IN2, M2_IN3, M2_IN4,
                  M3_IN1, M3_IN2, M4_IN3, M4_IN4, SOL_REF, SOL_TANK};
    for (int i = 0; i < 10; i++) { pinMode(pins[i], OUTPUT); digitalWrite(pins[i], LOW); }
    BTPRINTLNF("[OK] 핀 초기화");

    // 구조체 초기화
    currentTime.hour = 0;
    currentTime.valid = false; currentTime.setMillis = 0;

    for (int i = 0; i < 4; i++) {
        motorTimers[i].active = false; motorTimers[i].pinA = 0;
        motorTimers[i].pinB = 0;      motorTimers[i].endTime = 0;
    }
    for (int i = 0; i < KH_HIST_MAX; i++) {
        khHist[i].timestamp[0] = '\0'; khHist[i].dkh = 0.0; khHist[i].valid = false;
    }

    BTPRINTLNF("[READY] 명령대기 (help 입력)");
}

// ============================================================
// 메인 루프
// ============================================================
void loop() {
    unsigned long now = millis();

    // ① pH 오버샘플링
    if (currentMode != MODE_IDLE && now - lastSampleTime >= SAMPLE_INTERVAL) {
        lastSampleTime = now;
        int16_t raw = ads.readADC_SingleEnded(0);
        if (raw < 0) raw = 0;
        sampleBuf[sampleCount] = raw;     // 트림 평균용: raw 저장 (정렬은 64개 모인 뒤)
        sampleCount++;

        if (sampleCount % 16 == 0) {
            BTPRINTF("  샘플링: "); BTPRINT(sampleCount);
            BTPRINTF("/"); BTPRINTLN(SAMPLE_N);
        }

        if (sampleCount >= SAMPLE_N) {
            // 트림 평균: 삽입정렬 후 상·하위 각 TRIM_N개 버리고 중앙 (SAMPLE_N-2*TRIM_N)개만 평균.
            // computeVolts는 선형이라 raw 트림 평균 = mV 트림 평균과 동일.
            for (int i = 1; i < SAMPLE_N; i++) {
                int16_t key = sampleBuf[i]; int j = i - 1;
                while (j >= 0 && sampleBuf[j] > key) { sampleBuf[j+1] = sampleBuf[j]; j--; }
                sampleBuf[j+1] = key;
            }
            float vsum = 0.0;
            for (int i = TRIM_N; i < SAMPLE_N - TRIM_N; i++)
                vsum += ads.computeVolts(sampleBuf[i]) * 1000.0;
            voltage = vsum / (SAMPLE_N - 2 * TRIM_N);
            sampleSum = 0.0; sampleCount = 0; voltageReady = true;

            sensors.requestTemperatures();
            float t = sensors.getTempCByIndex(0);
            if (t == DEVICE_DISCONNECTED_C || t < -10.0 || t > 85.0) {
                BTPRINTLNF("[WARN] DS18B20 오류→25C"); temperature = 25.0;
            } else {
                temperature = t + tempOffset;
            }
            phValue = nernstPH(ph.readPH(voltage, temperature), temperature);
            if (phValue < 0.0 || phValue > 14.0) {
                BTPRINTF("[WARN] pH 이상: "); BTPRINTLN(phValue);
            }
            onSamplingComplete();
        }
    }

    // ② 보정 모드 모니터링 (2초마다 전압/pH 표시)
    static unsigned long calMonTime = 0;
    if (phCalMode && !voltageReady && currentMode == MODE_IDLE && (long)(now - calMonTime) >= 0) {
        calMonTime = now + 2000UL;
        sensors.requestTemperatures();
        float t = sensors.getTempCByIndex(0);
        if (t != DEVICE_DISCONNECTED_C && t > -10.0 && t < 85.0) temperature = t + tempOffset;
        int16_t raw = ads.readADC_SingleEnded(0);
        if (raw < 0) raw = 0;
        float v = ads.computeVolts(raw) * 1000.0;
        float p = nernstPH(ph.readPH(v, temperature), temperature);
        BTPRINTF("  [모니터] V:"); BTPRINTFD(v,3);
        BTPRINTF(" pH:"); BTPRINTFD(p,3);
        BTPRINTF(" T:"); BTPRINTLNFD(temperature,1);
    }

    // ③ 모터 타이머 (millis 오버플로우 안전)
    for (int i = 0; i < 4; i++) {
        if (motorTimers[i].active && (long)(now - motorTimers[i].endTime) >= 0) {
            digitalWrite(motorTimers[i].pinA, LOW);
            digitalWrite(motorTimers[i].pinB, LOW);
            motorTimers[i].active = false;
            BTPRINTF("[모터"); BTPRINT(i+1); BTPRINTLNF("] 완료");
            
        }
    }



    // ⑦ 명령 처리
    handleCommand();
}

// ============================================================
// pH 측정 시작
// ============================================================
void startMeasure(MeasureMode mode) {
    currentMode = mode; voltageReady = false;
    sampleSum = 0.0;    sampleCount = 0;
    lastSampleTime = millis();
    if (mode == MODE_TANK)        BTPRINTLNF("\n[START] 수조수 측정(8초)...");
    if (mode == MODE_REF)         BTPRINTLNF("\n[START] 참조수 측정(8초)...");
    if (mode == MODE_CALIBRATION) BTPRINTLNF("\n[CAL] 보정 측정중...");
}

// ============================================================
// 샘플링 완료
// ============================================================
void onSamplingComplete() {
    BTPRINTLNF("---");
    if (currentMode == MODE_TANK) {
        tankPH = phValue;
        BTPRINTF("[수조수] V:"); BTPRINTFD(voltage,3);
        BTPRINTF(" pH:"); BTPRINTFD(tankPH,3);
        BTPRINTF(" T:"); BTPRINTFD(temperature,1); BTPRINTLNF("C");
        tankMeasDone = true; BTPRINTLNF("[OK]");
        

    } else if (currentMode == MODE_REF) {
        refPH = phValue;
        BTPRINTF("[참조수] V:"); BTPRINTFD(voltage,3);
        BTPRINTF(" pH:"); BTPRINTFD(refPH,3);
        BTPRINTF(" T:"); BTPRINTFD(temperature,1); BTPRINTLNF("C");
        refMeasDone = true; BTPRINTLNF("[OK]");
        currentMode = MODE_IDLE;
        
        return;
    } else if (currentMode == MODE_CALIBRATION && calphPending) {
        BTPRINTF("[CAL] V:"); BTPRINTFD(voltage,3);
        BTPRINTF(" pH:"); BTPRINTFD(phValue,3);
        BTPRINTF(" T:"); BTPRINTFD(temperature,1); BTPRINTLNF("C");
        calphPending = false;
        bool inRange = (voltage>1322&&voltage<1678)||(voltage>1854&&voltage<2210);
        char calCmd[] = "CALPH";
        ph.calibration(voltage, temperature, calCmd);
        if (!inRange) voltageReady = false;
    }
    BTPRINTLNF("---");
    currentMode = MODE_IDLE;
}

// ============================================================
// dKH 계산 + 이력 저장
// ============================================================
void calcAndSaveKH() {
    if (!refMeasDone) { BTPRINTLNF("[ERR] ref 없음");  return; }
    if (refDKH    <= 0.0) { BTPRINTLNF("[ERR] refDKH 없음");  return; }
    if (!tankMeasDone)    { BTPRINTLNF("[ERR] tank 미측정");  return; }

    deltaPH = refPH - tankPH;
    tankDKH = refDKH * pow(10.0, -deltaPH);

    if (tankDKH < 0.0 || tankDKH > 50.0) {
        BTPRINTF("[WARN] dKH 이상:"); BTPRINTLN(tankDKH);
         return;
    }

    char ts[KH_TIME_LEN]; getTimeStr(ts);
    BTPRINTLNF("===[dKH]===");
    BTPRINTF("  시각:"); BTPRINTLN(ts);
    BTPRINTF("  참조pH:"); BTPRINTLNFD(refPH,3);
    BTPRINTF("  수조pH:"); BTPRINTLNFD(tankPH,3);
    BTPRINTF("  dPH:"); BTPRINTLNFD(deltaPH,4);
    BTPRINTF("  refKH:"); BTPRINTFD(refDKH,3); BTPRINTLNF(" dKH");
    BTPRINTF("  수조KH:"); BTPRINTFD(tankDKH,3); BTPRINTLNF(" dKH");
    BTPRINTF("  온도:"); BTPRINTFD(temperature,1); BTPRINTLNF("C");
    BTPRINTLNF("===========");

    saveKHRecord(tankDKH);
    BTPRINTF("[OK] 이력저장 총"); BTPRINT(khHistCount); BTPRINTLNF("개");

    tankMeasDone = false; refMeasDone = false;
    
}

// ============================================================
// 참조 dKH 역산 (수조 dKH 기준)
// setref에 저장된 값을 수조 dKH로 간주하여 참조 dKH를 계산
// ============================================================
void calcRefDKH() {
    if (!refMeasDone) { BTPRINTLNF("[ERR] ref 없음"); return; }
    if (refDKH    <= 0.0) { BTPRINTLNF("[ERR] setref 없음 (수조dKH 입력)"); return; }
    if (!tankMeasDone)    { BTPRINTLNF("[ERR] tank 미측정"); return; }

    float knownTankDKH = refDKH;
    deltaPH = tankPH - refPH;
    float newRefDKH = knownTankDKH * pow(10.0, -deltaPH);

    if (newRefDKH < 0.5 || newRefDKH > 30.0) {
        BTPRINTF("[WARN] refDKH 이상:"); BTPRINTLN(newRefDKH);
        return;
    }

    char ts[KH_TIME_LEN]; getTimeStr(ts);
    BTPRINTLNF("===[calref]===");
    BTPRINTF("  시각:"); BTPRINTLN(ts);
    BTPRINTF("  참조pH:"); BTPRINTLNFD(refPH,3);
    BTPRINTF("  수조pH:"); BTPRINTLNFD(tankPH,3);
    BTPRINTF("  dPH:"); BTPRINTLNFD(deltaPH,4);
    BTPRINTF("  새refDKH:"); BTPRINTFD(newRefDKH,3); BTPRINTLNF(" dKH");
    BTPRINTF("  수조dKH:"); BTPRINTFD(knownTankDKH,3); BTPRINTLNF(" dKH");
    BTPRINTF("  온도:"); BTPRINTFD(temperature,1); BTPRINTLNF("C");
    BTPRINTLNF("===============");

    refDKH = newRefDKH;
    EEPROM.put(REF_DKH_ADDR, refDKH);
    BTPRINTF("[OK] refDKH 저장:"); BTPRINTFD(refDKH,3); BTPRINTLNF(" dKH");

    tankMeasDone = false; refMeasDone = false;
    BTPRINTLNF("[INFO] ref/tank 재측정 필요");
}

// ============================================================
// 모터 제어
// ============================================================
void motorRunTimed(int idx, int pinA, int pinB, bool fwd, long sec) {
    if (sec <= 0 || sec > 3600) {
        BTPRINTLNF("[ERR] 모터시간 1~3600초");
         return;
    }
    if (motorTimers[idx].active) {
        digitalWrite(motorTimers[idx].pinA, LOW);
        digitalWrite(motorTimers[idx].pinB, LOW);
    }
    digitalWrite(pinA, fwd ? HIGH : LOW);
    digitalWrite(pinB, fwd ? LOW  : HIGH);
    motorTimers[idx].active  = true;
    motorTimers[idx].pinA    = pinA;
    motorTimers[idx].pinB    = pinB;
    motorTimers[idx].endTime = millis() + (unsigned long)sec * 1000UL;
    BTPRINTF("[M"); BTPRINT(idx+1);
    if (fwd) BTPRINTF("] 정방향 "); else BTPRINTF("] 역방향 ");
    BTPRINT(sec); BTPRINTLNF("초");
}

void motorStopNow(int idx, int pinA, int pinB) {
    digitalWrite(pinA, LOW); digitalWrite(pinB, LOW);
    motorTimers[idx].active = false;
    BTPRINTF("[M"); BTPRINT(idx+1); BTPRINTLNF("] 정지");
}

void motorAllStop() {
    motorStopNow(0,M1_IN1,M1_IN2); motorStopNow(1,M2_IN3,M2_IN4);
    motorStopNow(2,M3_IN1,M3_IN2); motorStopNow(3,M4_IN3,M4_IN4);
}

// ============================================================
// 에어/PWM 핀 OFF (airoff 용)
// ============================================================
void stopAir() {
    digitalWrite(SOL_REF, LOW); digitalWrite(SOL_TANK, LOW);
}


// ============================================================
// 단일 명령 실행
// ============================================================
void executeOneCmd(const char* rawCmd) {
    char cmd[SEQ_CMD_LEN]; strncpy(cmd, rawCmd, SEQ_CMD_LEN-1); cmd[SEQ_CMD_LEN-1]='\0';
    // 소문자 변환
    for (int i = 0; cmd[i]; i++) if (cmd[i]>='A'&&cmd[i]<='Z') cmd[i]+=32;

    // settime:HH
    if (strncmp(cmd, "settime:", 8) == 0) {
        int h = atoi(cmd + 8);
        if (h >= 0 && h <= 23) {
            currentTime.hour = h;
            currentTime.valid = true; currentTime.setMillis = millis();
            char ts[KH_TIME_LEN]; getTimeStr(ts);
            BTPRINTF("[OK] 시각(시): "); BTPRINTLN(ts);
        } else { BTPRINTLNF("[ERR] settime:HH (0~23)"); }
         return;
    }

    // ref / tank / calkh / calref
    if (strcmp(cmd,"ref")==0)     { refMeasDone=false;  startMeasure(MODE_REF);  return; }
    if (strcmp(cmd,"tank")==0)    { tankMeasDone=false; startMeasure(MODE_TANK); return; }
    if (strcmp(cmd,"calkh")==0)  { calcAndSaveKH(); return; }
    if (strcmp(cmd,"calref")==0) { calcRefDKH();  return; }

    // 모터: m1f:초, m1b:초, m1s
    struct { int idx; int pa; int pb; const char* pf; } mdef[4] = {
        {0,M1_IN1,M1_IN2,"m1"}, {1,M2_IN3,M2_IN4,"m2"},
        {2,M3_IN1,M3_IN2,"m3"}, {3,M4_IN3,M4_IN4,"m4"}
    };
    for (int i = 0; i < 4; i++) {
        char pff[3]; strncpy(pff, mdef[i].pf, 2); pff[2]='\0';
        char pfF[5], pfB[5], pfS[4];
        snprintf(pfF, sizeof(pfF), "%sf:", pff);
        snprintf(pfB, sizeof(pfB), "%sb:", pff);
        snprintf(pfS, sizeof(pfS), "%ss", pff);
        if (strncmp(cmd, pfF, 4)==0) { motorRunTimed(mdef[i].idx,mdef[i].pa,mdef[i].pb,true,  atol(cmd+4)); return; }
        if (strncmp(cmd, pfB, 4)==0) { motorRunTimed(mdef[i].idx,mdef[i].pa,mdef[i].pb,false, atol(cmd+4)); return; }
        if (strcmp(cmd, pfS)==0)     { motorStopNow(mdef[i].idx,mdef[i].pa,mdef[i].pb);  return; }
    }

    if (strcmp(cmd,"airoff")==0) { stopAir(); BTPRINTLNF("[에어] OFF");  return; }

    // 솔레노이드 직접 (ron/ton=각 핀 ON, roff/toff=각 핀 OFF, airoff=둘 다 OFF)
    if (strcmp(cmd,"ron")==0)       { digitalWrite(SOL_REF,  HIGH); BTPRINTLNF("[SOL] 참조ON"); }
    else if (strcmp(cmd,"roff")==0) { digitalWrite(SOL_REF,  LOW);  BTPRINTLNF("[SOL] 참조OFF"); }
    else if (strcmp(cmd,"ton")==0)  { digitalWrite(SOL_TANK, HIGH); BTPRINTLNF("[SOL] 수조ON"); }
    else if (strcmp(cmd,"toff")==0) { digitalWrite(SOL_TANK, LOW);  BTPRINTLNF("[SOL] 수조OFF"); }
    else { BTPRINTF("[?] "); BTPRINTLN(cmd); }
    
}
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

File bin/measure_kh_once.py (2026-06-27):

#!/usr/bin/env python3
"""
AquaWiz KH 1회 측정 (V4 — 평형(plateau) 추종 측정)
HC-06 블루투스 시리얼로 한 번만 측정하고 dkh.dat 에 기록 후 종료.

두 가지 모드:
  • (기본) calkh 모드 — 인자 없이 실행. ref dKH(EEPROM 앵커)로 tank dKH 측정,
    결과를 dkh.dat 에 기록(아래 형식). Windows 작업 스케줄러 정시 실행용.
  • calref 모드 — `--setref <수조실측dKH>` 지정. tank·ref pH 측정은 동일하나
    calkh 대신 calref 를 호출해 *ref dKH 를 역산*한다. 절차:
      1) 명령라인 수조 실측 dKH 를 setref 로 펌웨어에 기록(측정 전 즉시 검증).
      2) tank·ref pH 측정(calkh 모드와 완전히 동일).
      3) calref 호출 → 펌웨어가 newRefDKH = 수조dKH · 10^(-(tankPH-refPH)) 계산 후
         refDKH 에 대입 + EEPROM 저장(펌웨어 calcRefDKH 가 자동 저장 → 추가 setref 불요).
    ★측정 결과도 dkh.dat·reefCore 에 기록한다(수조 dKH = --setref 로 입력한 실측값,
    ref_kh 칼럼 = 역산된 새 ref dKH). 평탄 미도달이면 calkh 와 동일하게 수조 dKH 에
    음수(-) 표식을 붙여(값 크기는 입력값 유지) 값만으로 미평탄을 알 수 있게 한다
    (음수=미평탄·0=에러도 reefCore 에 그대로 발행 — 부호/0 이 상태 전달). 알려진 수조 dKH 로 ref 를 교정할 때 쓴다.
    ★★calref 의 저장·발행·에러 처리는 calkh 와 **완전 동일**(성공=값 기록·발행, 실패/일부 None=0.0 에러 표식
    기록·발행, 에러 래치도 공통). 모드 차이는 콘솔 안내 문구(ref dKH 저장 여부)뿐 — 동작 일치로 상황 파악을 직관화.

V4 (2026-06-17): "측정 중 폭기 + 진짜 평형(평탄)까지" 측정.
  - tank·ref 를 폭기 유지(ron)한 채 반복 측정, **최근 FLAT_SPAN_N개 max−min ≤ FLAT_SPAN_MPH(흔들림)
    AND 최근 FLAT_NET_N개 양끝차 ≤ FLAT_NET_MPH(드리프트)** 면 평형 도달로 보고 종료. ★B1: net 룩백을
    span보다 길게(8 vs 4) 둬 느린 단조 꼬리 조기 latch 차단(정수 비교라 float 지터 없음).
    → 격차(시작 CO₂)에 자동 적응(평탄할 때까지 측정).
    차동에서 ref·tank 가 같은 평형(실내공기 pCO₂)에 도달 → 방 CO₂ 상쇄.
  - ★tank 먼저 + 5L 위즈수조 동시 폭기(2026-06-20): m1=본수조↔홀딩, m2=홀딩↔측정챔버,
    m4=참조수(5L)↔측정챔버, m3=KCl↔측정챔버.
    [A] tank(본수조수)를 측정챔버서 폭기+평탄까지 측정. 이 동안 5L 위즈수조가 *동시 폭기*돼
        ref 가 5L서 co-aeration → 평형 도달.
    [B] tank 를 홀딩에 임시 파킹(빠른 비움) → 즉시 ref(5L) 이송 → 폭기+평탄까지 측정
        (ref 가 동시폭기로 이미 평형 근처라 빨리 끝남). 파킹 tank 는 ref 측정 후 마무리 배출.
  - ★무한 대기 방지: phase 별 PHASE_MAX_SECS·MEAS_MAX·연속실패 FAIL_MAX 상한,
    시리얼 read 타임아웃. 평탄 미도달 시 마지막값+경고로 종료(행 안 함).
  - ★HC-06 블루투스 RF 순단 대응(사용자 설계 2026-06-23): 측정이 BT SPP(COM9)로 돌아 RF 링크가
    간헐적으로 끊긴다(장시간 다운 없음; 펌웨어는 살아있고 드롭은 대개 '보낼 때 이미 끊겨 있음').
      (예방) keepalive — HC-06 는 ~20초 무통신 시 링크가 끊기는 경향(조사: Arduino/Reddit 사례).
             측정 간 30초·모터 60~85초 유휴 동안 빈 줄을 주기 송신해 링크를 깨워 둔다.
      (send 정책) ①모든 명령 송신 전 연결확인(ensure_link=status 핑) ②끊겼으면 재연결(close→open)
             ③보낸 뒤 연결문제(송신/수신 예외·응답 미수신)면 재연결 후 재시도 ④재시도 SEND_RETRY_MAX 회
             ⑤모터는 재시도 시 먼저 정지(mNs) 후 재송신 → 미전달이든 진행중이든 중복 구동 방지.
    calkh·calref(--setref) 모두 같은 send()/measure_until_flat 를 타므로 동일 적용.
  - ★규칙: 액체 이동(mXf/mXb) 직전 airoff. ron=에어(D12)·ton=PWM(D13) 독립, airoff=둘 다 OFF.
  - 오류/비정상 종료 시 비상 정리(_safe_cleanup): 에어 OFF + 측정챔버 배출 + KCl 소크 복원.
  ※ 측정 중 폭기라 절대 pH 에 흐름(streaming) 오프셋 — V3 이전 절대값과 직접 비교 금지
    (오프셋은 ref·tank 공통모드라 ΔpH/dKH 엔 무영향).
  ※ 널테스트 한정: ref 채우기 전 헹굼 생략. 정상운영(KH 다름) 복귀 시 복원 필수.

dkh.dat 형식 (한 줄에 하나):
  HH ref_pH tank_pH ref_kh tank_kh temp
  14 7.823 7.412 8.523 7.901 25.3
  15 0.000 0.000 0.000 0.000 0.0   ← 오류/타임아웃/KCl 소크 실패 시 (에러 표식)
  - ★에러 래치: 마지막 줄이 에러 표식(값 전부 0)이면, 다음 실행은 *측정하지 않고*
    에러 표식만 재기록한다(수동으로 마지막 에러 줄을 지우기 전까지). 프로브 보호를
    위해 오류 상태에서 무인 반복측정을 멈춤.
  - ★평탄 미도달 표식: 정상이지만 일부 phase 가 평탄(평형) 미도달이면 측정 경도(tank_kh)에
    음수(-) 부호를 붙인다(값 크기는 유지). 서버가 부호로 "미평탄"을 인지.
"""

import serial
import time
import re
import sys
import os
import argparse
from datetime import datetime

PORT     = 'COM9'
BAUD     = 9600

# ── 평형(평탄) 판정 — measure_until_flat (정수 milli-pH 윈도우; float 비교 지터 회피) ──
FLAT_SPAN_N    = 4       # 흔들림(span) 판정 윈도우 — 최근 N개
FLAT_SPAN_MPH  = 2       # 최근 FLAT_SPAN_N개 max−min ≤ 2 mpH (흔들림 폭). 정수 비교라 float 지터 없음
FLAT_NET_N     = 8       # ★B1(2026-06-20): 드리프트(net) 판정 룩백 — span보다 긴 창(≈5분)
FLAT_NET_MPH   = 1       # 최근 FLAT_NET_N개 양끝 |win[-1]-win[0]| ≤ 1 mpH. 짧은 4점은 느린 단조 꼬리서 net=1 위장(20:29 tank 10회 조기 latch) → 8점으로 차단
MEAS_INTERVAL  = 30      # 측정 간 간격(초) — 폭기 지속
# ── ★무한 대기 방지 상한 ──
PHASE_MAX_SECS = 7200    # phase(tank/ref)별 최대 측정 시간(초)=2h. 2-phase라 총 4h(측정 갭 8h의 절반). 초과 시 마지막값+경고
MEAS_MAX       = 240     # phase별 최대 측정 횟수(백스톱)=7200s/30s, PHASE_MAX_SECS와 정합
FAIL_MAX       = 5       # 연속 측정 파싱 실패 허용 횟수 → 초과 시 phase 실패
# ── ★HC-06 블루투스 RF 순단 대응(사용자 설계 2026-06-23): 측정이 BT SPP(COM9)로 돌아 RF 링크가
#    간헐적으로 끊긴다(장시간 다운은 없음; 펌웨어는 살아있고 드롭은 대개 '보낼 때 이미 끊겨 있음').
#    send() 정책: ①모든 명령 송신 전 연결확인(ensure_link) ②끊겼으면 재연결 ③보낸 뒤 연결문제면
#    재연결 후 재시도 ④재시도 SEND_RETRY_MAX 회까지 ⑤모터는 재시도 시 정지(mNs) 후 재송신.
RECONNECT_TRIES   = 5            # reconnect() 1회당 close→open 재연결 시도 횟수(진짜 순단은 1~2회면 붙음)
RECONNECT_BACKOFF = (1, 1, 2, 2, 3)      # 시도별 대기(초). 범위 넘으면 마지막값 유지
SEND_RETRY_MAX    = 3            # send() 1회당 재시도 횟수(꼭 3 아니어도 됨 — 튜닝 가능)
# ★keepalive(2026-06-23, 조사 결과): HC-06 SPP 는 ~20초 무통신 시 링크가 끊기는 경향이 있다
#   (Arduino/Reddit 사례: "유휴=드롭, 주기적 송신=안정"). 측정 간격 30초·모터 동작 60~85초가 그 임계를
#   넘으므로, 유휴 동안 빈 줄('\r\n', 펌웨어가 line 544 에서 조용히 무시)을 주기 송신해 링크를 *예방적*으로
#   깨운다 → 애초에 드롭을 줄이고, 그래도 끊기면 send() 의 재연결-재송신이 복구.
KEEPALIVE_SECS    = 12           # 유휴 keepalive 간격(초) — HC-06 ~20초 임계 아래
MEAS_READ_TIMEOUT = 20           # 측정 1회 '[OK]' 대기 상한(초). 펌웨어 측정 ~8초이므로 20초면 RF 드롭 판정
LINK_PING_TIMEOUT = 3            # ensure_link/reconnect 의 status 핑 응답 대기 상한(초)

DAT_FILE = os.path.join(os.path.dirname(os.path.abspath(__file__)), 'dkh.dat')
LOG_FILE = r'C:\dkh\measure_kh.log' if os.name == 'nt' else None


def setup_logging():
    """Windows에서 pythonw 로 실행될 때 모든 print 출력을 로그 파일로 보낸다.
    pythonw 는 sys.stdout 이 None 이라, redirect 하지 않으면 첫 print() 에서 죽는다.
    1MB 초과 시 새로 시작해 무한 증가를 막는다."""
    if os.name != 'nt':
        return
    target = None
    try:
        mode = 'w' if (os.path.exists(LOG_FILE) and os.path.getsize(LOG_FILE) > 1_000_000) else 'a'
        target = open(LOG_FILE, mode, encoding='utf-8', buffering=1)  # 줄 단위 flush
    except OSError:
        try:
            target = open(os.devnull, 'w')   # 로그 못 열어도 print 가 죽지 않게
        except OSError:
            target = None
    if target is not None:
        sys.stdout = target
        sys.stderr = target
        print(f"\n===== measure_kh_once V4 {datetime.now():%Y-%m-%d %H:%M:%S} =====")


# ─────────────────────────────────────────────
# 파일 기록
# ─────────────────────────────────────────────

def log_kh(hour, ref_ph, tank_ph, ref_kh, tank_kh, temp):
    """시각과 측정값 전체를 dkh.dat 에 한 줄 추가 후 즉시 닫기.
    형식: HH ref_pH tank_pH ref_kh tank_kh temp
    """
    line = f"{hour:02d} {ref_ph:.3f} {tank_ph:.3f} {ref_kh:.3f} {tank_kh:.3f} {temp:.1f}"
    with open(DAT_FILE, 'a') as f:
        f.write(line + '\n')
    print(f"[LOG] {DAT_FILE} ← {line}")
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

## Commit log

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2026-05-30 Clarify KCL 3% as pH probe storage solution, not cleaning
    KCL 3% solution keeps the pH probe submerged to prevent drying.
    Pump 3 supplies/drains KCL storage water before and after measurement.
2026-05-30 All pumps are bidirectional: add reverse flow for water return
    - All 4 peristaltic pumps support forward (f) and backward (b) operation
    - After measurement, water is returned to its origin:
    M4b returns reference water to Wiz Tank
    M2b returns tank water to sample beaker
    M1b returns sample water to aquarium
    - Updated sequence, SVG diagrams (bidirectional arrows), and all docs
2026-05-30 Fix measurement sequence: simultaneous degassing of both samples
    Reference water (pH beaker) and tank water (sample beaker) must both
    be loaded BEFORE aeration so CO2 equilibrium is achieved simultaneously.
    Corrected sequence: prepare → degas → measure ref → return ref →
    transfer tank → measure tank → calculate → return all → store probe.
2026-05-30 Fix SVG viewBox overflow and minor cleanup
    - piping-diagram.svg: increase viewBox height 500→520 (D13/Air2 labels were clipped)
    - system-setup.svg: remove unused marker def
    - README.md: add piping-diagram.svg to project tree listing
2026-05-30 Move pH probe to right side of beaker to avoid overlapping text
2026-05-30 Fix SVG visibility: pump 2/3 forward arrows, M1-M4 circle labels
    - system-setup.svg: pump 2/3 forward arrows now curve above labels
    so both forward (f) and backward (b) flows are clearly visible
    - piping-diagram.svg: move "양방향" text outside circles to pump
    labels, enlarge circle radius 18→20 with larger font for M1-M4
2026-05-30 Redesign piping diagram: separate entry points on pH beaker
    M2/M3/M4 arrows no longer overlap - each pump connects to a
    different zone (top/mid/bottom) of the enlarged pH beaker.
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2026-05-30 Fix KCL text overlap, add f/b labels to pump 1/4, air lines bottom-up
    - Reroute pump 3 lines below KCL beaker to avoid text overlap
    - Add f/b direction labels to pump 1 and pump 4
    - Change air lines to enter beakers from below (consistent direction)
2026-05-30 Fix piping diagram: move f label above arrow, draw M circles over lines
    - Move "f: 샘플링" label above the arrow line (y=88)
    - Draw M1-M4 circles AFTER lines so circles render on top
    - Enlarge circles r=22 with white border for clarity
    - Increase M1-M4 font to 14px bold
2026-05-30 Fix pump 3 arrows overlap and reroute pH probe line around KCL
    - Separate pump 3 forward (y=320 horizontal) and backward (y=400 curved)
    - Reroute controller→pH probe dashed line above KCL beaker
2026-05-30 Fix backward arrow directions and rename 배관→호스
    - Replace _rev markers with normal markers on backward lines
    (orient=auto with _rev on left-going lines caused arrows to flip)
    - Rename all 배관 references to 호스
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2026-05-30 Fix air hose diagram: show 3-way solenoid serial connection
    The solenoid valves are 3-way valves connected in series
    (기포기 → SOL1 → SOL2), not in parallel from the air pump.
    SOL1 ON output goes to pH beaker, SOL1 OFF output feeds SOL2 input.
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2026-05-30 Fix critical bugs: command buffer overflow, millis() timer overflow
    - cmdBuf increased from 34 to 128 bytes (static) to hold full seq commands
    - Serial read timeout increased from 100ms to 200ms for longer commands
    - Timer comparisons changed to (long)(now - endTime) >= 0 for millis()
    overflow safety (affects motor, air, wait timers after ~49.7 days)
    - Fix user-manual seq example: was missing m4f (reference water transfer)
    - Remove unused SoftwareSerial.h from user-manual library list
    [aquawiz_ph_meter_final.ino]
2026-05-30 Fix khhist output: use dtostrf instead of snprintf %f on AVR
    AVR libc's snprintf does not support %f format, causing dKH values
    to display as '?' in khhist output. Replaced with dtostrf().
    [aquawiz_ph_meter_final.ino]
2026-05-30 Fix parts list: correct AliExpress URL, add target=_blank links, update pump image
    - AliExpress URL fixed to correct product (1005001888639071)
    - All purchase links open in new tab (target="_blank")
    - Pump image replaced with actual product photo from AliExpress
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2026-05-30 Add missing parts to parts list: resistors, capacitor, sensors, supplies
    Added components found in schematic but missing from purchase list:
    DS18B20, solenoid valves, 100nF ceramic cap, resistors (4.7k/10k/20k),
    12V adapter, jumper wires, air pump, silicone hose, beakers, KCL solution
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2026-05-30 Redesign README for first-time visitors
    - Add feature highlights (7 key points) at the top
    - Add visual gallery: system diagram, piping, circuit, housing in 2x2 grid
    - Compact pin assignments and power section
    - Add document navigation table
    - Keep setup-demo.svg as hero image
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2026-05-30 Move compile/library info out of user manual, link to README instead
    Library and build details belong near the firmware, not in the user
    manual. Replaced with a link to README#빌드-및-업로드.
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2026-05-30 Fix power diagram: L298N3 runs on 6V for solenoid valves
    Solenoid valves (ZHY-0519) are 6V DC rated. L298N3 motor supply
    connects to XL4015 Buck 6V output, not 12V directly.
    L298N1/L298N2 remain on 12V for peristaltic pumps.
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2026-05-31 Add truncation warning for long commands, fix seq limit docs
    Firmware: warn user when command exceeds 127 chars (was silently truncated)
    Docs: correct "최대 30단계" to "전체 127자 이내" (buffer is the real limit)
    Add truncation warning to error message reference table
    [aquawiz_ph_meter_final.ino]
2026-05-31 Reject truncated commands instead of executing them
    Truncated commands could cause unexpected side effects (e.g. partial
    seq running incomplete steps). Now prints error and returns without
    executing.
    [aquawiz_ph_meter_final.ino]
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2026-05-31 Add noise filter guide diagram and 10uF capacitor to parts list
    - noise-filter-guide.svg: capacitor placement diagram with power
    topology, C1-C4 positions, and installation guidelines
    - parts-list: add 10uF electrolytic (C3, ADS1115 TI recommended),
    clarify 100nF placement (C1: Arduino, C2: ADS1115, C4: DS18B20)
    - system-setup: add noise countermeasure section with diagram
2026-05-31 Update noise filter diagram: pH signal board has built-in bypass caps
    SEN0161-V2 schematic confirmed: 100nF+10uF on each op-amp power rail
    (C3/C5, C9/C10, C11/C12, C6/C4) + 2.2nF input filter (C1).
    No external bypass needed on signal board VCC-GND.
2026-05-31 Revise noise filter design based on TI ADS1115 datasheet verification
    - Remove 10uF electrolytic at ADS1115 (TI warns: parallel caps with
    different values can create LC resonance; ADS1115 draws only 150uA)
    - Add RC input filter: 330ohm + 100nF on analog signal path
    (fc=4.8kHz, ~34dB attenuation at fMOD=250kHz, TI recommended)
    - Update parts list: 100nF x4, add 330ohm, remove 10uF
    - Update noise filter diagram with R6+C3 RC filter on signal path
2026-05-31 Update Fritzing schematic with noise filter components
    Added C1(100nF Arduino), C2(100nF ADS1115 VDD), R6(330ohm)+C4(100nF)
    RC input filter on pH signal path. Regenerated PNG preview.
    [고정밀 ph 측정기-bread.fzz]
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2026-05-31 Reduce SEQ_MAX_STEPS 30→15: RAM 90%→72% (563B stack free)
    128-byte command buffer limits practical max to ~15 steps anyway.
    Saves 360 bytes of RAM, eliminates compiler stability warning.
    [aquawiz_ph_meter_final.ino]
2026-05-31 SEQ_MAX_STEPS 15→20, reject and warn on overflow
    Prints error and refuses to execute when seq exceeds 20 steps.
    Flash 94%, RAM 78%, stack 443B.
    [aquawiz_ph_meter_final.ino]
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2026-05-31 Fix stack overflow: eliminate recursive advanceSeq calls
    advanceSeq() previously called executeSeqStep() recursively.
    With 20 immediate commands (e.g. settime), recursion depth = 20,
    requiring ~2470B stack vs 443B available = OVERFLOW.
    Fix: advanceSeq() sets seqAdvancePending flag, loop() processes
    next step in the next cycle. Max stack depth is now constant.
    [aquawiz_ph_meter_final.ino]
2026-05-31 Remove redundant ph.calibration() loop call that steals serial data
    The 2-parameter ph.calibration(voltage, temperature) was called every
    loop iteration. It internally calls Serial.read(), competing with
    handleCommand() for serial bytes and potentially corrupting commands.
    Calibration is handled via the 3-parameter version called from
    handleCommand(), which processes enterph/calph/exitph correctly.
    Flash 95%→93% (-406B), RAM 78%→77% (-12B).
    [aquawiz_ph_meter_final.ino]
2026-05-31 Fix pH calculation: use measured refPH instead of recalculating
    refPH was being recalculated with current temperature in calcAndSaveKH
    and onSamplingComplete, but refVoltage was generated at ref measurement
    temperature. Using stored refPH (correctly Nernst-compensated at
    measurement time) eliminates temperature mismatch error.
    Verified: 2-point calibration, Nernst compensation, dKH formula all
    mathematically correct. Error < 0.00004 dKH at same temperature.
    Flash 93% (-202B), RAM 77% unchanged.
    [aquawiz_ph_meter_final.ino]
2026-05-31 Store calibration temperature in EEPROM for accurate Nernst compensation
    nernstPH() now uses actual calibration temperature instead of
    hardcoded 25°C. Calibration temp saved to EEPROM 0x18 on exitph,
    loaded on boot. Displayed in status output.
    Eliminates systematic error when calibrating at non-25°C temperatures
    (was up to 1.2% at 10°C difference, now 0%).
    Flash 94%, RAM 78%, stack 450B.
    [aquawiz_ph_meter_final.ino]
2026-05-31 Update EEPROM map in docs and firmware header
    Added calTemp at 0x18~0x1B, fixed address ranges for existing entries.
    [aquawiz_ph_meter_final.ino]
2026-05-31 Add measurement accuracy analysis to system-setup docs
    Nernst compensation verified: 0% error across 15-35°C range.
    System accuracy: ±0.07 dKH (±1.2%), dominated by pH probe repeatability.
    ADC resolution: ±0.001 dKH after 64x oversampling.
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2026-06-01 Redesign setup-demo SVG and update Fritzing schematic
    - setup-demo.svg: completely rebuilt with correct hose routing
    (M3/M4 through pH beaker), air distributor with AIR label,
    accuracy badge, cleaner layout
    - Fritzing: updated fzz/pdf/png with latest schematic
    [고정밀 ph 측정기-bread.fzz]
2026-06-02 Add calcref command: reverse-calculate reference dKH from tank dKH
    When the user knows the tank dKH (from a commercial test kit),
    calcref computes the reference water's dKH using the pH difference:
    newRefDKH = knownTankDKH × 10^(-(tankPH - refPH))
    The result is saved to EEPROM as the new refDKH.
    No history record is saved.
    Usage: setref:8.5 (tank dKH) → ref → tank → calcref
    Flash 97%, RAM 78%.
    [aquawiz_ph_meter_final.ino]
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2026-06-03 Replace boot help with ready message
    [aquawiz_ph_meter_final.ino]
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2026-06-03 Fix calcref: reset session after execution to prevent cumulative error
    Repeated calcref calls caused refDKH to drift because the updated
    refDKH was used as knownTankDKH in the next call. Now resets
    tankMeasDone/refMeasDone after calcref, requiring re-measurement.
    [aquawiz_ph_meter_final.ino]
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2026-06-03 Remove resetref command (unnecessary)
    refDKH is set via setref, refVoltage requires ref measurement.
    No practical need to zero-initialize. Flash 95%→94% (-108B).
    [aquawiz_ph_meter_final.ino]
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2026-06-03 Fix calTemp protection: require enterph before calph/exitph
    Added phCalMode flag. calph/exitph without enterph now shows
    "[ERR] enterph 먼저 실행" and does not overwrite calTemp.
    Prevents accidental calTemp change from stray exitph commands.
    [aquawiz_ph_meter_final.ino]
2026-06-03 Warn if calibration temperature differs >2C between sessions
    On exitph, if current temperature differs from previous calTemp
    by more than 2°C, warn user that 2-point calibration should be
    done consecutively to avoid Nernst correction error.
    [aquawiz_ph_meter_final.ino]
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2026-06-03 Fix calibration monitor: stop after calph measurement complete
    Monitor was continuing after calph because phCalMode stayed true.
    Added !voltageReady condition to stop monitoring once measurement
    is done (voltageReady becomes true after 64 samples).
    [aquawiz_ph_meter_final.ino]
2026-06-03 Fix critical: send ENTERPH to DFRobot library on enterph
    Without this, the library's enterCalibrationFlag was never set,
    causing calph and exitph to be silently ignored by the library.
    Calibration appeared to work but values were not actually updated.
    [aquawiz_ph_meter_final.ino]
2026-06-03 Add temperature reading to calibration monitor
    Monitor now reads DS18B20 for accurate Nernst-corrected pH display.
    Output: [모니터] V:2047.9 pH:3.88 T:28.1
    Flash 99% (162B remaining), RAM 78%.
    [aquawiz_ph_meter_final.ino]
2026-06-03 Trim verbose messages to free Flash: 99%→98% (+194B)
    - Buffer overflow message shortened
    - Seq step overflow message shortened
    - Calibration temperature warning shortened
    - Help example line removed
    [aquawiz_ph_meter_final.ino]
2026-06-03 Fix: reset voltageReady on enterph so monitor always works
    After previous ref/tank measurements, voltageReady was true,
    blocking the calibration monitor. Now enterph resets it.
    [aquawiz_ph_meter_final.ino]
2026-06-03 Reset measurement session on enterph
    Previous ref/tank measurements are invalid after recalibration.
    enterph now resets tankMeasDone and refMeasDone, requiring
    fresh measurements after calibration is complete.
    [aquawiz_ph_meter_final.ino]
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2026-06-03 Fix khhist dKH output: 2 decimal places → 3 (unified)
    [aquawiz_ph_meter_final.ino]
2026-06-03 Rename commands: calckh→calkh, calcref→calref (shorter, consistent)
    calph kept as-is (DFRobot library command name).
    Updated firmware, README, user-manual, system-setup.
    [aquawiz_ph_meter_final.ino]
2026-06-03 Add measured stability data: pH ±0.0005, voltage ±0.061mV
    Real-world test results from 5 consecutive measurements in KCL
    solution, near ADS1115 16-bit theoretical limit.
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2026-06-03 Resize app icon to 40x40, clarify Nano EMI rationale and ESP32 expansion
    - BT terminal icon: 20x20 → 40x40 (half of original 80x80)
    - Arduino Nano chosen for minimal EMI interference
    - ESP32 expansion for Wi-Fi, web dashboard, data logging
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2026-06-07 Prevent calTemp save when calph fails (buffer out of range)
    If measured voltage is outside pH 4.0 (1854-2210) and pH 7.0
    (1322-1678) ranges, voltageReady is reset to false. Subsequent
    exitph will cancel instead of saving calTemp.
    [aquawiz_ph_meter_final.ino]
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2026-06-08 회로도 수정, 온도센터 실드 연결
    [고정밀 ph 측정기-bread.fzz]
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2026-06-08 Update docs: air control via L298N3, remove solenoid/XL4015, add USB air pump
    - Add completion photo to README and system-setup
    - Deprecate air:총초:주기초 alternating command, use ron/ton/airoff
    - Document PWM speed control via Motor- reversed signal to ENA/ENB
    - Remove XL4015 DC-DC converter and 3-way solenoid valves from parts list
    - Add USB 5V air pump x2 with purchase link
    - Update seq examples from 13 to 16 steps (ron|ton|wait|airoff)
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2026-06-10 Add set_time.py (pyserial controller clock-sync) and file logging to dkh_server
    set_time.py replaces the fragile Arduino IDE GUI-automation (AutoHotkey)
    clock-sync with direct pyserial transmission to COM10/COM12.
    - Sends 'set time HH:MM:SS' with LF only (these controllers ignore commands
    terminated with CR; they echo all input as '수신 명령문 : <cmd>').
    - Captures the timestamp right before write for accuracy; logs the echo
    response to C:\dkh\set_time.log for delivery verification.
    dkh_server.py now logs to C:\dkh\dkh_server.log on Windows so the
    pythonw-launched scheduled task leaves a trace (no console).
    [dkh_server.py, set_time.py]
2026-06-10 measure_kh_once: redirect output to log file for pythonw execution
    The Measure KH scheduled task now runs under pythonw.exe (no console
    window each hour). pythonw has sys.stdout = None, so print() would crash;
    setup_logging() redirects stdout/stderr to C:\dkh\measure_kh.log on
    Windows (line-buffered, truncates past 1MB), falling back to os.devnull
    if the log can't be opened.
    [measure_kh_once.py]
2026-06-12 Symmetric KH measurement: tank-first sequence with convergence detection
    measure_kh_once/loop: aerate storage tank (5L) directly while probe
    rests in KCl; measure tank first (KCl sweep doubles as rinse), then ref
    with identical rinse/fill/stabilize timing so electrode response lag
    cancels as common mode. Replace single-shot ref/tank reads with
    convergence loop (45s interval, <0.003 pH, max 6) — count logged as
    electrode health indicator. dkh.dat format unchanged.
    Docs: rewrite system-setup measurement sequence for the symmetric
    design, switch probe storage solution KCL 3% -> 3M KCl across docs/SVGs.
    [measure_kh_once.py]
2026-06-14 Tune pump timings, shorten aeration, relax convergence eps
    - 헹굼(rinse) forward 30→60, back 38→68 for m2/m4: full-immersion
    rinse so the measuring cup inner wall is wetted; tank/ref kept symmetric
    - m1f:80 (long hose sampling), m1b:92 (+12s to clear long hose)
    - AIR_SECS 1800→1200 (30→20min): widens hourly margin to ~16-22min
    - CONV_EPS 0.003→0.005: noise floor measured ~0.001-0.002 pH, so
    3-5x noise converges reliably in 2-3 reads; dKH impact ~0.05
    [measure_kh_once.py]
2026-06-15 Replace product photo with front/internal shots in README and setup docs
    기존 단일 '완성한 실물' 사진을 전면(펌프·전원·튜빙)과 내부(제어 기판) 2장으로 교체, 2열 표로 배치.
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2026-06-17 ledger: record manual ron at 6/15 05:00, tighten time-gap reasoning
    6/15 05:00 ran on V0 (no terminal aeration in code) but the user
    applied continuous aeration manually via ron. Both that dawn and
    6/16 05:00 (V1, auto terminal ron) thus had equivalent pre-aeration
    state with identical measurement sequence/time-gap, yet ΔpH flipped
    sign (+0.020 vs -0.059) — so neither time-gap nor aeration state
    drives it; room CO2 (absolute pH) does.
2026-06-17 ledger: elimination complete — residual cause is sequential read timing
    Chamber/airstone confirmed already identical (user), and volume already
    matched, so at airoff ref and tank share the same pCO2. The only
    remaining asymmetry is that one probe reads them ~5 min apart while the
    room CO2 swings. Corrects the earlier loose "time gap is not the cause":
    precisely ΔpH ≈ (read interval) × (room-CO2 rate of change) — the
    interval is the conduit, dC/dt the multiplier (constant interval, so
    day-to-day swing came from dC/dt: 6/15 ventilated ~0, closed dawns large).
    Robust fixes must kill the inter-read drift: seal samples after aeration,
    aerate from a stable gas source, or minimize the inter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
2026-06-17 firmware: remove air:/wait: timed commands (legacy, unused)
    Drop the timed/alternating aeration (air:) and wait (wait:) commands plus
    their state (AirState/WaitState structs, globals, loop timers, startAir/
    applyAir/startWait). They were solenoid-era leftovers, broken after the
    rewiring and unused by the Python driver (which uses ron/airoff + its own
    timing). stopAir is kept (airoff uses it) and simplified to just drive
    both pins LOW.
    Full check (arduino:avr:nano): compiles with no warnings. flash 94%->89%
    (free 3172 B), SRAM 59%->58% (free 855 B). All Python-used commands
    present (ron/roff/ton/toff/airoff, m1-m4 f/b/s, tank/ref/calkh); motor
    dispatch intact.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
    [aquawiz_ph_meter_final.ino]
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2026-06-17 ledger: validate convergence algorithms on plateau CSV — window-flat wins
    Offline replay of the plateau curve:
    - consecutive-Δ≤0.002 (current): latches at 8.071, -0.029 (early, on the
    slow slope).
    - window-flatness (last-4 max-min ≤0.002): 8.100, error 0 — accurate but
    waits for the full plateau.
    - least-squares exponential extrapolation: within ±0.002 by ~857s but
    then drifts to +0.008 (8.108) as data accumulates — the real curve
    isn't a single exponential (fit τ creeps 440→580, slow tail), so the
    extrapolated asymptote is biased. Not deployable.
    Since identical ref/tank protocol is impossible (different source
    vessels + single probe), the robust path is window-flat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
    [plateau_analyze.py]
2026-06-17 V4: error-latch on dkh.dat + negative tank_kh flag for plateau-miss
    - Error latch: before measuring, if the last dkh.dat line is the error
    marker (all five values 0), skip the measurement and just append
    another error marker. Repeats every run until a human removes the
    trailing error line — stops unattended re-measuring while the rig is
    in a fault state (e.g., KCl soak failed / probe unsafe).
    - Plateau-miss flag: a normal-but-not-flat reading is logged with the
    measured hardness tank_kh negated (minus sign), magnitude preserved,
    so the server can recognize "not at plateau" by the sign. Distinct
    from the all-zero error marker, so it does NOT trigger the latch.
    Adds last_dat_is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
    [measure_kh_once.py]
2026-06-17 V4: use the plateau test's proven convergence (consecutive Δ≤0.001)
    Don't change what works. The plateau test (test_aeration_plateau.py)
    used consecutive Δ ≤ 0.001 (3 in a row) and cleanly detected the true
    plateau on real runs (8.100, 8.062). measure_kh_once had drifted to an
    unvalidated window max-min ≤ 0.002 criterion. Switch measure_until_flat
    to the same proven rule (consecutive Δ≤0.001 ×3, 30s interval) so the
    measurement matches the validated test exactly. Keeps the safety guards
    (PHASE_MAX/MEAS_MAX/FAIL_MAX) and 2-phase structure.
    Note: this aligns the convergence logic; it does NOT fix the 17:08 drift
    failure (that was room-CO2 drift over the long 2-phase measurement, n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
    [measure_kh_once.py]
2026-06-17 both scripts: integer milli-pH window-span plateau test (fix jitter + creep)
    plateau_run2 analysis exposed two flaws in the consecutive-Δ≤0.001 rule
    both scripts were using:
    1. Float-comparison jitter — a displayed "0.001" step is a float like
    0.0010000…1 (> 0.001), so abs(d)<=0.001 flipped True/False and kept
    resetting the consecutive counter (latched at 1053s instead of 702s:
    the explanation-vs-result mismatch the user spotted).
    2. Consecutive-Δ is too loose — deterministically "3×1mpH" latches on the
    slow exponential tail at 8.053 (−0.009 from the 8.062 plateau); the
    test's earlier "good" 8.062 was a lucky jitter delay, not by design.
    Fix (both test_aeration_p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
    [measure_kh_once.py, test_aeration_plateau.py]
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2026-06-20 측정코드 4h 상한 + m4b 긴호스 +10, 6/21 부분널(옛 tank degrade 확정)
    코드(measure_kh_once.py, repo+C:\dkh\work 동일배포):
    - m4b:68→70 (5L↔측정챔버 긴 호스, 역방향만 +10으로 완전회수)
    - PHASE_MAX_SECS 2400→7200 (2h/phase, 2-phase 총 4h = 측정갭 8h의 절반)
    - MEAS_MAX 80→240 (7200s/30s 정합), FAIL_MAX 유지(시간무관)
    ledger:
    - 6/21 05:00 B1 새벽검증(gap 8번째 확증, 시간대 의존성 배제)
    - 6/21 06:00 부분 널(tank만 신선): ΔpH −0.05→−0.010 붕괴
    → 옛 tank 200mL 물 degrade 확정적(석출 가설 지지)
    - 석출(CaCO₃) 가설 메커니즘 기록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
    [measure_kh_once.py]
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2026-07-01 fix(sync): 평탄 데이터 동기화 두 버그 수정
    1. run_started만 비교해 "같은 실행이면 스킵"하던 로직이 진행 중인 측정을
    첫 스냅샷에서 영구히 멈추게 함(측정 1회에 1시간 넘게 걸릴 수 있어 크론
    주기 안에 여러 번 갱신돼야 하는데, 두 번째 사이클부터 계속 스킵됨 —
    어제 21시 측정 그래프가 일부만 그려진 원인). run_started 대신 파싱
    결과 전체를 비교하도록 수정, 완료 여부 판단용 completed 필드 추가.
    2. 로컬이 origin을 fetch/rebase 안 해서 GitHub Actions가 직접 push하는
    렌더링 커밋과 로컬 커밋이 매번 갈라져 이후 push가 전부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
    [parse_plateau_log.py, sync_dkh_dat.py]
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
